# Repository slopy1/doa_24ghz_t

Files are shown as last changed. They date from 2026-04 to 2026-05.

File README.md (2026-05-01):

# DOA-24GHz: Direction-of-Arrival Estimation at 2.4 GHz

**Portable, real-time DoA estimation using a 2-element antenna array on an embedded FPGA platform**




## Overview

This thesis project implements a portable Direction-of-Arrival (DoA) estimation system at 2.4 GHz. A two-channel coherent SDR (BladeRF 2.0 xA4) feeds an FPGA SoC that runs the cross-correlation pipeline in fabric and root-MUSIC on the application processor. The system is bench-portable: a barrel-jack-powered SDR, two λ/2-spaced whip antennas, an nRF5340 signal source, and a single Ethernet link to a host PC.

Four DoA algorithms are implemented:
- **Root-MUSIC** (default) — polynomial root finding, fast and accurate
- **MUSIC** — spectral search with pseudo-spectrum visualization
- **MVDR** (Capon) — minimum variance beamformer
- **Phase Difference** — simple and fast baseline

Based on: Wachowiak & Kryszkiewicz (2022) — *"Angle of arrival estimation in a multi-antenna software defined radio system"*

## Current Platform Status

| Platform | Role | Branch / state |
| --- | --- | --- |
| **AMD Kria KV260** (Zynq UltraScale+ K26, Ubuntu 22.04 aarch64) | **Primary** — active thesis development, current capture campaigns | `main` |
| **Digilent Cora Z7** (Zynq-7000, PetaLinux 2025.2) | **Validated reference** — end-to-end pipeline + display, frozen | `feature/fir-backpressure` (frozen, not merged) |

The two platforms run the **same `doa_pipeline` RTL** (FIR + phase-cal rotation + cross-correlation + autocorrelation accumulators) and the same root-MUSIC implementation, with platform-specific transports for AXI register I/O and DMA.

### Why two platforms?

The thesis began on the Cora Z7. The Cora pipeline reached an end-to-end validated state on the `feature/fir-backpressure` branch (RTL + GNU Radio + headless driver + touch display), but PetaLinux 2025.2 ships with a confirmed upstream regression in chipidea USB binding (AMD answer record [AR#000039143](https://adaptivesupport.amd.com/), all-platforms, fix ETA 2026.1) that breaks BladeRF USB enumeration on any rebuilt `image.ub`. Each RTL or driver iteration past that point would have required either rolling forward onto a broken USB stack or freezing on a stale pre-rebuild image. The KV260 (Kria K26 SOM, Ubuntu 22.04 aarch64) sidesteps PetaLinux entirely and bypasses the bug, so live thesis development moved there. The Cora reference branch remains in this repo as a validated baseline; current capture campaigns run on the KV260.

## Hardware

| Component | Model | Purpose |
|---|---|---|
| FPGA SoC (primary) | AMD Kria KV260 starter kit (K26 SOM, ZU+ MPSoC) | Live thesis platform — Ubuntu + headless NumPy driver |
| FPGA SoC (reference) | Digilent Cora Z7 (Zynq-7000) | Frozen end-to-end reference — PetaLinux + GNU Radio |
| SDR | Nuand BladeRF 2.0 xA4 | 2-channel coherent receiver, 1 MS/s |
| Antennas | 2× Linx ANT-2.4-CW-RCL whips | Half-wavelength ULA (61.2 mm) |
| Signal source | nRF5340 DK (Zephyr `radio_test`) | 2.419 GHz GFSK / modulated carrier |
| Display (Cora-era, optional) | Waveshare ESP32-S3 4.3" Touch LCD | LVGL touch UI via UART |
| Power | TalentCell LiFePO4 12.8 V + DC-DC buck (Cora bench); BladeRF barrel jack 5 V/2 A | |

See [docs/HARDWARE_DETAILS.md](docs/HARDWARE_DETAILS.md) for enclosure dimensions and wiring.

## RF Parameters

| Parameter | Current campaign value |
|---|---|
| Center frequency | 2.41895 GHz (nRF ch 19 = 2.419 GHz, off-tuned 50 kHz) |
| Sample rate | 1 MS/s |
| RX bandwidth | 1 MHz |
| Antenna spacing | 61.2 mm (λ/2 at 2.45 GHz) |
| Array type | 2-element Uniform Linear Array |
| BladeRF gain | 50 dB |

## Repository Structure

```
doa_24ghz_t/
├── kv260_headless/             # KV260 driver path (PRIMARY)
│   ├── aoa_estimation_fpga_kv260.py   # NumPy + SoapySDR DoA driver
│   ├── aoa_estimation_headless.py     # ARM-only path (no FPGA accel)
│   ├── phase_calibration_headless.py  # Wired phase calibration
│   ├── emio_probe.py                  # EMIO GPIO bring-up check
│   ├── dma_probe.py                   # AXI-DMA state dump
│   └── ...
├── cora_headless/              # Cora Z7 driver (frozen reference)
│   ├── aoa_estimation_fpga_v2.py      # FPGA-accelerated DoA
│   ├── aoa_estimation_headless.py     # ARM-only baseline
│   ├── main.py                        # UART display controller
│   ├── web_dashboard.py               # HTTP + SSE web UI
│   ├── display_firmware/              # ESP32 LVGL touch display
│   └── initd/                         # SysVinit auto-start
├── fpga/
│   ├── rtl/                    # doa_pipeline + dma_safe_ctrl + supporting IP
│   ├── vivado_kv260/           # KV260 block design + constraints
│   ├── tb/                     # iverilog testbenches
│   └── GETTING_STARTED.md      # Vivado build flow
├── gnuradio_flowgraphs/        # Cora-era GRC flowgraphs (reference)
├── scripts/                    # Campaign automation, analysis, deploy
├── data/                       # Capture sessions (runA … runE, baselines)
├── results/                    # Campaign analysis outputs (plots, CSVs, fits)
├── hardware/                   # 3D-printed enclosure (OpenSCAD + STL)
└── docs/                       # Specs, thesis chapter sources, hardware details
```

## Quick Start (KV260 — primary path)

```bash
# 1. Bring up bitstream + udmabuf + EMIO gates (idempotent)
ssh ubuntu@<kv260-ip> 'sudo bash ~/doa/bench_bringup.sh'

# 2. Run a capture (60 s, root-MUSIC, unfiltered, ch 19 + 50 kHz off-tune)
ssh ubuntu@<kv260-ip> 'sudo python3 ~/doa/aoa_estimation_fpga_kv260.py \
    --filter none --algo rootmusic --freq 2.418e9 --gain 50'

# 3. Per-angle protocol (label captures by angle for the campaign)
ssh ubuntu@<kv260-ip> 'echo "50deg" > ~/doa/data/current_label.txt'
# … repeat capture for next angle …
```

Per-capture CSV + JSON sidecar lands under `~/doa/data/aoa_<LABEL>_<MODE>_<ALGO>_<TS>.csv`. See [docs/DEMO_QUICKSTART.md](docs/DEMO_QUICKSTART.md) for the full bench protocol.

## Quick Start (Cora Z7 — reference)

The Cora reference path lives on the `feature/fir-backpressure` branch (frozen, not merged into `main`):

```bash
git fetch origin feature/fir-backpressure
git checkout feature/fir-backpressure
# Then deploy to petalinux@<cora-ip>:/home/petalinux/doa/ per cora_headless/README
```

The Cora deployment includes a web dashboard (`http://<cora-ip>:8080`) and a touch display front-end. Live thesis development happens on `main` against the KV260 — this branch is preserved as the validated end-to-end baseline.

## Calibration

Wired phase calibration using a signal source, attenuator, and power splitter:

```
Signal Source (nRF5340 @ 2.419 GHz)
    → 30 dB SMA attenuator
    → 2-way power splitter
        → matched cable → BladeRF RX1
        → matched cable → BladeRF RX2
```

```bash
# KV260
sudo python3 ~/doa/phase_calibration_headless.py --freq 2.418e9 --duration 10
```

The `--filter=none` calibration is filter-agnostic (broadband static phase offset), reusable across filter regimes.

## Documentation

| Document | Description |
|---|---|
| [DEMO_QUICKSTART](docs/DEMO_QUICKSTART.md) | Step-by-step bench/demo procedure |
| [DEMO_COMMANDS](docs/DEMO_COMMANDS.txt) | Command reference (nRF + driver) |
| [HARDWARE_DETAILS](docs/HARDWARE_DETAILS.md) | Enclosure, components, power |
| [INSTALL_GUIDE](INSTALL_GUIDE.md) | Host PC + KV260 software setup |
| [fpga/GETTING_STARTED](fpga/GETTING_STARTED.md) | Vivado build flow + register map |
| [docs/specs/](docs/specs/) | Phase-by-phase RTL design specs |

## FPGA Pipeline

The `doa_pipeline` IP runs the per-snapshot signal processing in fabric:

```
BladeRF IQ stream → channel_splitter → fir_filter_sc16 → phase_rotate_sc16
                                                              ↓
                                       xcorr_acc + autocorr_acc (R00, R11)
                                                              ↓
                                                    AXI-Lite read-back
```

15 AXI-Lite registers, 48-bit accumulators read as LO/HI pairs. Same RTL on both targets, two transports:

- **Cora Z7**: AXI-Lite at `0x4000_0000` via `/dev/mem` mapping; AXI-DMA on OCM (0xFFFC_0000) bypassing CMA
- **KV260**: AXI-Lite at `0xA001_0000` via EMIO GPIO bit-banged register I/O (Path C); AXI-DMA on `S_AXI_HP0_FPD` with udmabuf-allocated CMA buffers

The KV260 transport works around an AXI-Lite write-strobe stride bug observed on the Kria HPM0_FPD aperture — see [docs/specs/2026-04-22-kv260-plan-of-attack.md](docs/specs/2026-04-22-kv260-plan-of-attack.md) for the full debug arc.

## License

MIT License

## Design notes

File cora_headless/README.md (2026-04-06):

# Cora Z7 Headless DoA System

This package contains all the software and documentation for the portable Direction of Arrival (DoA) estimation system based on the BladeRF 2.0 SDR and Cora Z7 FPGA board.

## System Architecture

```
┌─────────────────────────────────────────────────────────────────┐
│                                                                  │
│   ┌──────────────┐      UART       ┌──────────────────────┐    │
│   │   Waveshare  │◄───────────────►│      Cora Z7         │    │
│   │  ESP32 LCD   │   (Commands &   │   (PetaLinux +       │    │
│   │  (Touch UI)  │    Responses)   │    Python Scripts)   │    │
│   └──────────────┘                 └──────────┬───────────┘    │
│                                               │                 │
│                                          USB 2.0               │
│                                          (6 MSPS max)          │
│                                               │                 │
│                                    ┌──────────▼───────────┐    │
│                                    │     BladeRF 2.0      │    │
│                                    │     2×2 MIMO SDR     │    │
│                                    │     (Coherent RX)    │    │
│                                    └──────────┬───────────┘    │
│                                               │                 │
│                                    ┌──────────▼───────────┐    │
│                                    │   2-Element ULA      │    │
│                                    │   λ/2 = 61.2mm       │    │
│                                    │   @ 2.45 GHz         │    │
│                                    └─────────────────────-┘    │
│                                                                  │
└─────────────────────────────────────────────────────────────────┘
```

## Package Contents

```
cora_headless/
├── README.md                          # This file
├── main.py                            # UART command listener (runs on Cora)
├── phase_calibration_headless.py      # Calibration script
├── aoa_estimation_headless.py         # DoA estimation with multiple algorithms
│
├── display_firmware/
│   └── doa_display_firmware.ino       # ESP32 display firmware (Arduino)
│
├── systemd/
│   └── doa-controller.service         # Auto-start service for Cora
│
└── docs/
    └── WIRING_DIAGRAM.md              # Complete electrical connections
```

## Quick Start

### 1. Deploy to Cora Z7

```bash
# Copy files to Cora (adjust IP/hostname)
scp -r main.py *_headless.py root@cora:/home/root/doa/

# SSH into Cora
ssh root@cora

# Install service
cp doa-controller.service /etc/systemd/system/
systemctl daemon-reload
systemctl enable doa-controller
systemctl start doa-controller
```

### 2. Flash Display Firmware

1. Open `display_firmware/doa_display_firmware.ino` in Arduino IDE
2. Install required libraries:
   - LVGL (v8.x)
   - Board support for ESP32-S3
3. Select board: "ESP32S3 Dev Module" (or Waveshare-specific if available)
4. Flash via USB

### 3. Connect Hardware

Follow the wiring diagram in `docs/WIRING_DIAGRAM.md`.

### 4. First Run

1. Power on the system
2. Wait for display to show "Ready"
3. Tap **CALIBRATE** (with wired setup connected)
4. Record calibration value
5. Tap **ESTIMATE** to begin DoA measurements

## UART Protocol

### Commands (Display → Cora)

| Command | Description |
|---|---|
| `CALIBRATE` | Run phase calibration |
| `ESTIMATE` | Start DoA with default algorithm |
| `ESTIMATE:MUSIC` | Start with specific algorithm |
| `STATUS` | Query current state |
| `GET_CAL` | Get calibration coefficient |
| `SET_CAL:-12.5` | Manually set calibration (degrees) |
| `STOP` | Stop current operation |
| `SHUTDOWN` | Safe system shutdown |

### Responses (Cora → Display)

| Response | Description |
|---|---|
| `OK:<msg>` | Command acknowledged |
| `AOA:45.2` | Estimated angle (degrees) |
| `CAL:-8.7` | Calibration coefficient (degrees) |
| `STATUS:IDLE` | Current state |
| `PROGRESS:50` | Operation progress (0-100%) |
| `ERROR:<msg>` | Error message |
| `DONE` | Operation completed |

## Supported Algorithms

| Algorithm | Description | Speed | Accuracy |
|---|---|---|---|
| `PHASEDIFF`  | Simple phase difference | Fastest  | Low |
| `MUSIC` | Spectral search (181 points) | Slow | High |
| `ROOTMUSIC`  | Polynomial root finding (default) | Fast | High |
| `MVDR` | Capon beamformer | Medium | Medium |

## Hardware Constraints

- **USB 2.0 Bandwidth**: Limited to ~6 MSPS (vs 61 MSPS theoretical)
- **Thesis Justification**: "Due to hardware constraints of the FPGA platform, the system operates at reduced bandwidth sufficient for proof-of-concept DoA estimation."

## Calibration

The system requires wired phase calibration before use:

1. Connect signal source via splitter to both RX channels
2. Use matched-length cables
3. Include 30dB attenuator for safety
4. Run calibration for 10+ seconds
5. Record the stable phase offset value

**Typical values**: -30° to +30° depending on hardware

## Troubleshooting

| Symptom | Cause | Solution |
|---|---|---|
| "Disconnected" on display  | UART not connected | Check TX/RX wiring |
| No calibration signal | Gain too low | Increase RX gain |
| Erratic AoA readings | Missing calibration | Run CALIBRATE first |
| AoA stuck at 90° | No signal / weak signal | Check antenna connections |
| System won't power on | JP3 set to USB | Set JP3 to EXT |

## Development

### Testing Without Hardware

Both Python scripts support simulation mode when SoapySDR is unavailable:

```bash
# Test calibration
python phase_calibration_headless.py --duration=5

# Test estimation
python aoa_estimation_headless.py --cal=-10 --algo=ROOTMUSIC --single
```

### Testing main.py Locally

```bash
# Runs in stdin mode when UART unavailable
python main.py

# Enter commands manually:
> STATUS
> CALIBRATE
> ESTIMATE:MUSIC
> STOP
```

## References

- Wachowiak & Kryszkiewicz (2022) - "Angle of arrival estimation in a multi-antenna software defined radio system"
- gr-aoa: https://github.com/MarcinWachowiak/GNU-Radio-USRP-AoA
- BladeRF Wiki: https://github.com/Nuand/bladeRF/wiki
- Cora Z7 Reference: https://digilent.com/reference/programmable-logic/cora-z7/reference-manual

## License

MIT License - DoA Thesis Project 2026

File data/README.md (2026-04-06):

# Dataset Directory

This directory contains HDF5 captures for DOA experiments.

## File Naming Convention

```
capture_YYYYMMDD_HHMMSS_angle+XX_distY.Ym_SNR.h5
```

Example: `capture_20241221_153000_angle+30_dist2.0m_high.h5`

## Collecting Data

```bash
# Single capture
python scripts/collect_dataset.py --angle 30 --distance 2 --snr high

# Multiple repetitions
python scripts/collect_dataset.py --angle 30 --distance 2 --snr high --reps 10

# Full experiment matrix (run for each angle/distance)
for angle in -60 -45 -30 -15 0 15 30 45 60; do
    python scripts/collect_dataset.py --angle $angle --distance 2 --snr high --reps 10
    python scripts/collect_dataset.py --angle $angle --distance 5 --snr low --reps 10
done
```

## File Format

Each HDF5 file contains:

### Datasets
- `channel_0`: Complex64 array (RX0 samples)
- `channel_1`: Complex64 array (RX1 samples)

### Attributes
| Attribute | Type | Description |
|---|---|---|
| `timestamp_utc` | string | ISO timestamp |
| `center_frequency_hz` | float | 2.45e9 |
| `sample_rate_hz` | float | 5e6 |
| `nominal_angle_deg` | int | Ground truth angle |
| `distance_m` | float | TX-RX distance |
| `snr_label` | string | "high" or "low" |

## Data Size Estimate

- 1 second capture: ~40 MB (2 channels × 5M samples × 4 bytes)
- Full matrix (180 captures): ~7.2 GB

## Note on Large Files

Large HDF5 files are NOT committed to git. If you need to share data:

1. Use Git LFS: `git lfs track "*.h5"`
2. Use external storage (Dropbox, Google Drive, etc.)
3. Store a manifest file listing available captures

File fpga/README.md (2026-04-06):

# FPGA Implementation

This directory contains FPGA-related code and notes for accelerating the DOA pipeline on Zynq-7000.

## Target Platform

**Cora Z7-07S** (Xilinx Zynq-7000 XC7Z007S)

## Vivado Project

**Location:** `/home/vmau/tools/projects/cora-linux/cora_doa_hw/cora_doa_hw.xpr` (Vivado 2025.2)

**Block design (system):**
- ZYNQ7 Processing System (processing_system7_0)
- AXI DMA (axi_dma_0)
- Xilinx FFT IP (xfft_0)
- AXI Interconnect (axi_interconnect_0)
- Processor System Reset (rst_ps7_0_50M)
- xlconstant_0, xlconstant_1 (tieoffs, marked Discontinued)

Bitstream successfully generated. See `notes/vivado_block_design_2026-03-25.png` for screenshot.

## Directory Structure

```
fpga/
├── README.md              ← This file
├── GETTING_STARTED.md     ← Step-by-step implementation guide
├── rtl/
│   └── xcorr_acc.v        ← Cross-correlation module (skeleton, MAC TODO)
├── tb/
│   └── (testbench, next step)
├── constraints/
│   └── (timing .xdc if needed)
└── notes/
    └── vivado_block_design_2026-03-25.png
```

## Implementation Status

| Component | Status | Notes |
|---|---|---|
| Vivado block design | Done | FFT + DMA + AXI Interconnect wired |
| Bitstream (infrastructure) | Done | Generated successfully |
| Cross-correlation IP | In progress | Module skeleton in `rtl/xcorr_acc.v`, MAC datapath TODO |
| Power estimation | Designed | Same accumulator pattern as xcorr |
| Phase extraction | Pending | CORDIC or LUT, may stay on PS |
| AXI-Lite wrapper | Pending | After xcorr_acc simulation passes |
| Block design integration | Pending | Wire xcorr_acc into existing design |

## Architecture: Time-Domain Approach

Chosen over frequency-domain (FFT) for simplicity. The FFT block remains in the design for future use.

### What runs on PL (FPGA fabric)

1. **Streaming cross-correlation** (`xcorr_acc.v`)
   - Complex multiply-accumulate: `r_01 = Σ ch0[n] × conj(ch1[n])`
   - AXI-Stream input (64-bit, both channels packed)
   - AXI-Lite output registers for ARM to read results
   - ~4 DSP48 slices, ~500 LUTs

2. **Power estimation** (future, same accumulator structure)
   - `P_0 = Σ|ch0[n]|²`, `P_1 = Σ|ch1[n]|²`

### What runs on PS (ARM cores)

1. Phase extraction (atan2)
2. Grid search over angles
3. Kalman filter for drift tracking
4. Posterior computation

## Resource Budget

| Resource | Available | xcorr_acc | FFT (existing) | Remaining |
|---|---|---|---|---|
| DSP48 | 66 | 4 | ~10-15 | ~47 |
| BRAM | 50 | 0 | ~8-10 | ~30 |
| LUTs | 14,400 | ~500 | ~2000 | ~11,900 |
| FFs | 28,800 | ~1000 | ~2000 | ~25,800 |

## Next Steps

See [GETTING_STARTED.md](GETTING_STARTED.md) for the full walkthrough.

## References

- [docs/fpga_mapping.md](../docs/fpga_mapping.md) — Full architecture document
- Xilinx UG585 — Zynq-7000 TRM
- Xilinx UG1399 — Vitis HLS User Guide

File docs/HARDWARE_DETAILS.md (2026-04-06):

# Hardware Details — Portable Enclosure & Components

## Portable Enclosure

**Enclosure:** Meijia portable case, IP67 rated.

| Dimension | Imperial | Metric |
|---|---|---|
| Outside | 11.65 x 8.35 x 3.78" | 296 x 212 x 96mm |
| Inside | 10.54 x 6.04 x 3.16" | 268 x 153 x 80mm |
| Lid depth | 1.08" | 27.4mm |
| Bottom depth | 2.08" | 52.8mm |

Display mounts in lid (27.4mm deep — display at 8.6mm fits with 18.8mm to spare). All other components in bottom half.

## Display Bezel

3D-printed flat-frame mount. Source files:
- `hardware/display_bezel.scad` (OpenSCAD parametric source)
- `hardware/display_bezel.stl` and `.3mf` (exported)
- `hardware/ASSEMBLY.md` (install instructions)

Design: flat frame sits on lid exterior, display drops through cut hole from inside, optional back retainer clamps from behind.

## Display Measurements (Waveshare 4.3" 800x480)

- PCB: 106.33 x 68.2 x 8.6mm
- Glass (full incl. black frame): 106.2 x 67.8mm
- Glass/module thickness: 4.89mm
- Active area: 92.2 x 57.4mm (black border: 4.5mm top, 9.5mm bottom, 5.2mm each side)
- Bezel window: set to full glass (106.2 x 67.8mm)
- Bezel outer: ~120.8 x 82.4 x 2.5mm frame
- Lid hole to cut: ~106.9 x 68.8mm

## Components & Power

| Component | Power | Notes |
|---|---|---|
| Cora Z7 | 5V via barrel jack | JP3 set to EXT |
| BladeRF 2.0 xA4 | 5V via barrel jack (2A+) | TPS2115A auto-selects barrel over USB |
| Waveshare 4.3" display | 5V via USB-C | Mounts in lid, communicates via UART |
| Powered USB hub (Atolla) | 5V/3A own adapter | BladeRF USB + FT232R USB through hub |
| FT232R adapter | USB-powered from hub | TTL wires to ESP32 GPIO15/16 |
| 2-element ULA | Passive | lambda/2 = 61.2mm spacing @ 2.45 GHz |
| Battery | TalentCell LiFePO4 12.8V 6Ah | |
| DC-DC converter | Tobsun EA25-5V | 12.8V -> 5V, 25W |
| Power distribution | Wago 221 lever nuts | 5V bus to all devices |

## BladeRF Power Supply

The Cora Z7 USB-A host port (J11) provides limited current. The BladeRF 2.0 xA4 should be externally powered via its DC barrel jack (5V, 2A+, 5.5x2.5mm center-positive). Power options:
- **Bench supply**: 5V 2A current limit, alligator clips to barrel jack breakout wires
- **Portable**: TalentCell LiFePO4 (~13V) -> Tobsun EA25-5V 25W DC-DC converter -> 5V barrel jack
- **Wall adapter**: Any 5V 2A+ supply with 5.5x2.5mm center-positive barrel plug

The BladeRF's TPS2115A power mux auto-selects the barrel jack over USB when external power is present. Plug barrel jack first, then USB.

## Antennas

- **2x Linx ANT-2.4-CW-RCL** — 2.4 GHz helical whip, SMA, ~1 inch tall. Mounted on BladeRF RX1/RX2.
- Known issue: floppy hinge, needs to be stabilized (hot glue, heat shrink, or rigid bracket mount).

## Calibration Hardware

- **Mini-Circuits VAT-30A+** — 30 dB SMA fixed attenuator (DC-6 GHz, 1W). Place before splitter to protect BladeRF (max input ~0 dBm).
- **2-way power splitter** + **2x matched-length SMA cables** — for wired phase calibration.
- Connected as of 2026-03-18.

## Bottom Layout (approximate)

```
+----------------------------------+
|  BladeRF 2.0 xA4    |  Cora Z7  |
|  168 x 100 mm       |  89x89    |
|                      |           |
+----------------------+  USB Hub  |
|  TalentCell Battery  |  DC-DC    |
|  150 x 100 mm        |  Wago    |
+----------------------------------+
         ~296 x 212 mm
```

See `docs/WIRING_DIAGRAM.md` for detailed wiring and `docs/system_block_diagram.drawio` for the system block diagram.

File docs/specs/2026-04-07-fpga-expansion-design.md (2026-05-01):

# FPGA Expansion Design — 3-Phase Incremental Plan

**Date:** 2026-04-07
**Target:** Cora Z7 (Zynq-7000 XC7Z007S), Vivado 2025.2
**Goal:** Maximize FPGA utilization — move FIR filtering, auto-correlations, calibration, and multi-snapshot averaging into fabric. Each phase produces a working bitstream.

## Current State

**FPGA (PL):**
- `xcorr_acc` — computes r₀₁ = Σ(ch0 × conj(ch1)) per 1024-sample snapshot
- `xcorr_acc_axi` — AXI-Lite wrapper, 4 read-only registers (32-bit truncated from 48-bit accumulators)
- AXI DMA (SG mode) — ARM pushes one snapshot at a time
- ~4 DSP48 / ~2K LUTs / ~2K FFs used

**ARM (PS) — Python does all of this per update:**
1. Read 102,400 samples (100 × 1024) from BladeRF via SoapySDR
2. Apply FIR filter (201-tap lowpass/bandpass) via FFT convolution — both channels
3. Apply phase calibration rotation on ch1
4. Loop 100 times:
   a. Send 1024-sample snapshot to FPGA via DMA
   b. Read r₀₁ from AXI-Lite registers
   c. Compute r₀₀, r₁₁ in SC16 integer math (NumPy)
5. Average all 100 snapshots
6. Build 2×2 covariance matrix R
7. Eigendecomposition + Root-MUSIC → angle

**Known issues:**
- 32-bit register truncation causes MISMATCH on first 2-3 iterations (startup transient with large values)
- 100-iteration Python loop is the main latency bottleneck
- FIR filter on Cortex-A9 is slow even with FFT method

## Resource Budget (XC7Z007S)

| Resource | Total | Currently Used | Available |
|---|---|---|---|
| LUTs | 14,400 | ~2,000 | ~12,400 |
| FFs | 28,800 | ~2,000 | ~26,800 |
| DSP48E1 | 66 | ~4 | 62 |
| BRAM 36Kb | 50 | ~5 (DMA+FFT IP) | ~45 |
| BRAM 18Kb | 100 | ~10 | ~90 |

---

## Phase A — Enhanced Datapath (keep current DMA model)

**Goal:** Move FIR filtering, calibration rotation, and auto-correlations into fabric. ARM still loops 100×, but each iteration does almost no computation — just DMA kick + register read.

### A.1 New RTL Modules

#### `fir_filter_sc16` — FIR filter for one SC16 channel

```
Inputs:  s_axis_tdata[31:0] (SC16: {Q[31:16], I[15:0]})
         s_axis_tvalid, s_axis_tready
Outputs: m_axis_tdata[31:0] (filtered SC16)
         m_axis_tvalid, m_axis_tready
Config:  AXI-Lite writable coefficient RAM (up to 64 taps)
```

- Symmetric FIR (halves the multipliers needed for real-coefficient lowpass/bandpass)
- 64 taps max (vs 201 in Python — shorter but at line rate, and we can increase snapshot count to compensate)
- Filter I and Q components independently (real-coefficient FIR on complex data)
- Resource estimate: ~32 DSP48 for 64-tap symmetric (16 unique coefficients × 2 for I/Q), ~2K LUTs, 2 BRAM for coefficient storage

**Why 64 taps instead of 201:** At 1 Msps with 64 taps, the transition bandwidth is wider (~15 kHz vs ~5 kHz), but the stopband rejection is still >40 dB — sufficient for our SNR improvement goal. Going to 201 taps would consume all 66 DSP48s on just the filter.

**Alternative: 32 taps** if we need DSP headroom. 32-tap symmetric = 16 multipliers × 2 (I/Q) = 32 DSP48. Trade-off: ~30 dB stopband rejection.

**Recommended: 48 taps** — 24 unique coefficients × 2 = 48 DSP48. Leaves 14 DSP48 for xcorr + auto-corr. Good balance of rejection (~38 dB) and resource usage.

#### `phase_rotate_sc16` — Calibration phase rotation

```
Inputs:  s_axis_tdata[31:0] (SC16)
         s_axis_tvalid, s_axis_tready
Outputs: m_axis_tdata[31:0] (rotated SC16)
         m_axis_tvalid, m_axis_tready
Config:  AXI-Lite writable registers: cos_cal[15:0], sin_cal[15:0] (Q1.15 fixed-point)
```

- Complex multiply: (I + jQ) × (cos_cal - j·sin_cal)
  - I' = I·cos_cal + Q·sin_cal
  - Q' = Q·cos_cal - I·sin_cal
- Resource estimate: 4 DSP48, ~200 LUTs
- ARM writes cos/sin of calibration angle as Q1.15 values via AXI-Lite

#### `autocorr_acc` — Auto-correlation accumulator for r₀₀ and r₁₁

```
Inputs:  ch0_tdata[31:0], ch1_tdata[31:0] (SC16, after filtering)
         tvalid
Outputs: r00[47:0], r11[47:0], result_valid
```

- r₀₀ += I₀² + Q₀² (power of ch0)
- r₁₁ += I₁² + Q₁² (power of ch1)
- Same snapshot boundary logic as xcorr_acc (counter, latch, reset)
- Resource estimate: 4 DSP48, ~500 LUTs
- Can share the same AXI wrapper or be added to xcorr_acc_axi

### A.2 Modified `xcorr_acc_axi` — Expanded Register Map

Expand from 4 to 12 registers. Use full 48-bit readback (split into low/high words):

| Offset | Name | Width | Access | Description |
|---|---|---|---|---|
| 0x00 | XCORR_RE_LO | 32 | R | r₀₁ real, bits [31:0] |
| 0x04 | XCORR_RE_HI | 32 | R | r₀₁ real, bits [47:32] (sign-extended) |
| 0x08 | XCORR_IM_LO | 32 | R | r₀₁ imag, bits [31:0] |
| 0x0C | XCORR_IM_HI | 32 | R | r₀₁ imag, bits [47:32] (sign-extended) |
| 0x10 | R00_LO | 32 | R | r₀₀ auto-corr, bits [31:0] |
| 0x14 | R00_HI | 32 | R | r₀₀ auto-corr, bits [47:32] |
| 0x18 | R11_LO | 32 | R | r₁₁ auto-corr, bits [31:0] |
| 0x1C | R11_HI | 32 | R | r₁₁ auto-corr, bits [47:32] |
| 0x20 | STATUS | 32 | R | bit 0 = result_valid (sticky, clear-on-read) |
| 0x24 | SNAP_COUNT | 32 | R | completed snapshot counter |
| 0x28 | COS_CAL | 16 | R/W | calibration cos(θ) in Q1.15 |
| 0x2C | SIN_CAL | 16 | R/W | calibration sin(θ) in Q1.15 |
| 0x30 | FILTER_COEFF_ADDR | 8 | W | coefficient index to write |
| 0x34 | FILTER_COEFF_DATA | 16 | W | coefficient value (Q1.15) |
| 0x38 | FILTER_CTRL | 8 | R/W | bit 0 = filter enable, bit 1 = coefficients loaded |

Need C_S_AXI_ADDR_WIDTH ≥ 8 (currently 12, so no change needed).

### A.3 Block Design Changes (Vivado)

Current path:
```
DMA MM2S → xcorr_acc_axi (s_axis)
```

New path:
```
DMA MM2S → channel_splitter → fir_filter_sc16 (ch0) → ┐
                             → fir_filter_sc16 (ch1) → phase_rotate_sc16 → channel_merger
                                                                              ↓
                                                              xcorr_acc_axi (expanded, includes autocorr)
```

**channel_splitter:** Demuxes the interleaved 2-beat stream into two separate SC16 streams (ch0, ch1). Simple FSM toggling on beat_phase.

**channel_merger:** Re-interleaves the two filtered/calibrated SC16 streams back into the 2-beat format expected by xcorr_acc.

Alternatively: modify xcorr_acc to accept two separate input ports instead of interleaved. This avoids the split/merge overhead.

### A.4 Python Driver Changes (`aoa_estimation_fpga_v3.py`)

```python
# Phase A: ARM still loops, but registers provide full covariance per snapshot

# At startup — write filter coefficients and calibration
fpga.write_filter_coefficients(taps)  # AXI-Lite writes to coeff RAM
fpga.write_calibration(cal_deg)       # Write cos/sin to registers

# Per-update loop (100 snapshots)
for k in range(n_snap):
    fpga.dma_transfer(ch0_snap, ch1_snap)  # Push raw SC16 data
    r01_re, r01_im = fpga.read_xcorr_48bit()  # Full 48-bit read
    r00 = fpga.read_r00_48bit()
    r11 = fpga.read_r11_48bit()
    # Accumulate on ARM (simple addition, no DSP)
    acc_re += r01_re
    acc_im += r01_im
    acc_r00 += r00
    acc_r11 += r11

# Build R and run Root-MUSIC (same as before)
```

**What ARM no longer does:**
- FIR filtering (moved to FPGA)
- Phase calibration rotation (moved to FPGA)
- SC16 quantization for r₀₀/r₁₁ (FPGA computes directly)
- The Python loop is now: DMA kick → read 6 registers → add to accumulators

### A.5 Resource Estimate (Phase A)

| Resource | Phase A Usage | Total Available | % Used |
|---|---|---|---|
| DSP48E1 | ~56 (48 FIR + 4 phase_rot + 4 xcorr + 4 autocorr, but xcorr reuses) | 66 | ~85% |
| LUTs | ~6,000 | 14,400 | ~42% |
| FFs | ~5,000 | 28,800 | ~17% |
| BRAM 18Kb | ~4 (coeff storage) | 100 | ~4% |

**Note:** 48-tap FIR uses 48 DSP48 if we filter both channels. If resources are too tight, reduce to 32 taps (32 DSP48) or use a single time-shared FIR for both channels (halves DSP48 but doubles latency — fine at 1 Msps since the clock is 100 MHz, giving 100× oversampling).

**Recommended: Time-shared single FIR** — processes ch0, then ch1, using the same multiplier array. Uses 24 DSP48 for a 48-tap symmetric filter. Total DSP48: 24 + 4 + 4 + 4 = 36 (~55%).

### A.6 Testing Strategy

1. **Simulation (iverilog):**
   - `tb_fir_filter_sc16.v` — impulse response test, known sinusoid filtering
   - `tb_phase_rotate_sc16.v` — verify rotation angles (0°, 45°, 90°, 180°)
   - `tb_autocorr_acc.v` — known-power input, verify r₀₀/r₁₁
   - `tb_full_pipeline.v` — end-to-end: raw SC16 → filter → rotate → xcorr + autocorr

2. **Hardware test (on Cora):**
   - `test_fpga_pipeline.py` — synthetic DMA test similar to existing `test_fpga_xcorr.py`
   - Compare FPGA pipeline output vs NumPy reference for known phase/amplitude inputs

3. **Live comparison:**
   - `--debug` flag prints FPGA vs ARM reference for first N iterations with real BladeRF data

---

## Phase B — Autonomous Streaming (rework DMA)

**Goal:** Eliminate the 100-iteration Python loop. FPGA accumulates N snapshots autonomously. ARM reads the final averaged covariance matrix once per update.

### B.1 DMA Changes

Replace single-shot SG DMA with **cyclic DMA** (ring buffer):
- ARM sets up a circular SG descriptor ring
- DMA streams continuously from a shared DDR buffer
- BladeRF → SoapySDR writes to buffer, DMA reads from it
- FPGA consumes at line rate

Alternative (simpler): ARM still pushes data, but sends all 100 snapshots in one large DMA transfer (102,400 × 2 channels × 4 bytes = 819,200 bytes). Single SG descriptor chain, FPGA processes the entire batch.

**Recommended: Large single transfer** — simpler than true ring buffer, still eliminates the per-snapshot DMA setup overhead. ARM calls `readStream` once for all samples, packs them into the DMA buffer, kicks one transfer, waits for completion.

### B.2 New RTL: `multi_snapshot_acc`

Wraps xcorr_acc + autocorr_acc with an outer counter:
```
Parameter: NUM_SNAPSHOTS (writable via AXI-Lite, default 100)

For each snapshot (1024 samples):
  - Accumulate r01, r00, r11 as before
  - At snapshot boundary: add to outer accumulator
  - After NUM_SNAPSHOTS: latch final averaged values, assert result_valid
```

Register map adds:
| Offset | Name | Width | Access | Description |
|---|---|---|---|---|
| 0x3C | NUM_SNAPSHOTS | 16 | R/W | Snapshots to average before signaling result |
| 0x40 | AVG_R01_RE_LO | 32 | R | Averaged r₀₁ real |
| ... | | | | (6 more averaged registers) |

### B.3 Python Driver Changes

```python
# Phase B: single DMA transfer, single register read
fpga.write_num_snapshots(100)
fpga.dma_transfer_bulk(ch0_all, ch1_all)  # One big transfer
fpga.wait_for_result()                     # Poll STATUS register
R = fpga.read_covariance_matrix()          # Read 6 values → build 2x2 R
aoa = root_music_doa(R, ...)               # Only computation ARM does
```

### B.4 Resource Estimate (Phase B, incremental over A)

Additional ~500 LUTs, ~500 FFs for outer accumulator and control. DSP48 unchanged.

---

## Phase C — Full FPGA DoA (angle output)

**Goal:** FPGA outputs the DoA angle directly. ARM just reads one register.

### C.1 2×2 Eigendecomposition in Fixed-Point

For a 2×2 Hermitian matrix R = [[r₀₀, r₀₁], [r₀₁*, r₁₁]], the noise eigenvector has a closed-form:

```
The noise subspace eigenvector for a 2×2 matrix is:
  e_noise = [-r₀₁, r₀₀ - λ_min]  (unnormalized)

where λ_min = (r₀₀ + r₁₁)/2 - sqrt((r₀₀ - r₁₁)²/4 + |r₀₁|²)
```

This requires:
- Fixed-point square root (iterative, ~16 cycles for 48-bit)
- Basic arithmetic (add, subtract, shift)

### C.2 Root-MUSIC for 2 Elements

For a 2-element ULA with 1 source, Root-MUSIC reduces to:
```
phase = atan2(imag(r₀₁), real(r₀₁)) - cal_phase
angle = arccos(phase / (2π × d/λ))
```

Wait — for 2 elements and 1 source, Root-MUSIC simplifies to essentially the phase-difference method applied to the noise subspace. The polynomial is degree 1. This means:

- **CORDIC** for atan2 (~16 iterations, ~200 LUTs)
- **CORDIC** for arccos (same unit, different mode)
- Fixed-point division (or shift if d/λ = 0.5)

### C.3 Register Map Addition

| Offset | Name | Width | Access | Description |
|---|---|---|---|---|
| 0x50 | DOA_ANGLE | 16 | R | Estimated angle × 10 (e.g., 854 = 85.4°) |
| 0x54 | DOA_VALID | 1 | R | New angle available |

### C.4 Resource Estimate (Phase C, incremental over B)

Additional ~2K LUTs for CORDIC + sqrt + control. No additional DSP48.

**Total Phase C estimate:**

| Resource | Total Usage | Available | % Used |
|---|---|---|---|
| DSP48E1 | ~36 | 66 | ~55% |
| LUTs | ~9,000 | 14,400 | ~63% |
| FFs | ~7,000 | 28,800 | ~24% |
| BRAM 18Kb | ~4 | 100 | ~4% |

---

## Implementation Order (Tomorrow's Plan)

### Day 1 — Phase A Foundation

**Morning (RTL + Simulation):**

1. **Write `fir_filter_sc16.v`** — time-shared symmetric FIR, 48 taps
   - Coefficient loading via simple interface (not AXI-Lite yet — test first)
   - Testbench: impulse response, known sinusoid at 50 kHz, verify stopband rejection

2. **Write `phase_rotate_sc16.v`** — complex multiply with cos/sin registers
   - Testbench: 0°, 45°, 90°, 180° rotation, verify against NumPy

3. **Write `autocorr_acc.v`** — power accumulator for both channels
   - Testbench: known-amplitude input, verify r₀₀/r₁₁ match

4. **Run all simulations with iverilog** — all tests must pass before Vivado

**Afternoon (Integration):**

5. **Expand `xcorr_acc_axi.v`** — new register map (48-bit readback, cal registers, filter ctrl)
   - Testbench: AXI-Lite read/write verification

6. **Write `doa_pipeline.v`** — top-level wrapper connecting:
   `s_axis → fir_filter (time-shared) → phase_rotate (ch1 only) → xcorr_acc + autocorr_acc → registers`

7. **Full pipeline testbench** — synthetic SC16 data through entire chain, compare with NumPy

### Day 2 — Vivado + Hardware

8. **Package IP in Vivado** — add `doa_pipeline` as custom IP
9. **Update block design** — replace `xcorr_acc_axi_0` with new `doa_pipeline`
10. **Synthesis + Implementation** — check timing, utilization
11. **Generate bitstream** — save as `BOOT_phaseA.BIN`
12. **Write `aoa_estimation_fpga_v3.py`** — new driver using expanded registers
13. **Hardware test** — run `test_fpga_pipeline.py` with synthetic data
14. **Live test** — compare Phase A output vs current v2 with real BladeRF data

### Day 3+ — Phase B

15. Rework DMA to bulk transfer
16. Add multi-snapshot accumulator
17. New bitstream + driver
18. Benchmark: update rate comparison (Phase A vs Phase B vs pure ARM)

---

## Fallback Strategy

- **Current bitstream** saved as `BOOT_current.BIN` before any changes
- Each phase produces a named bitstream: `BOOT_phaseA.BIN`, `BOOT_phaseB.BIN`
- Python scripts versioned: `v2` (current), `v3` (Phase A), `v4` (Phase B)
- If Phase A synthesis fails timing: reduce FIR to 32 taps
- If Phase B DMA rework is too complex: stay on Phase A (still a major improvement)

## Design Decisions Summary

| Decision | Choice | Rationale |
|---|---|---|
| FIR tap count | 48 (symmetric → 24 unique) | Balances rejection (~38 dB) vs DSP48 budget |
| FIR architecture | Time-shared (1 filter, 2 channels) | Halves DSP48 usage, 100 MHz clock gives 100× margin at 1 Msps |
| Accumulator width | 48-bit | Matches existing xcorr_acc, 6 bits headroom over worst case |
| Register readback | 48-bit split (LO/HI) | Fixes 32-bit truncation bug seen in debug |
| Cal rotation | Q1.15 cos/sin | 15-bit fractional precision ≈ 0.002° angular resolution |
| Phase A→B transition | Large single DMA transfer | Simpler than ring buffer, eliminates per-snapshot overhead |
| Phase C eigen | Closed-form 2×2 | No iterative solver needed for 2-element array |

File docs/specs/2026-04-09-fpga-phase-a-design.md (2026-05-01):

# FPGA Phase A — Enhanced Datapath Design Spec

**Date:** 2026-04-09
**Parent spec:** `2026-04-07-fpga-expansion-design.md`
**Target:** Cora Z7 (Zynq-7000 XC7Z007S), Vivado 2025.2
**Goal:** Move FIR filtering, phase calibration rotation, and auto-correlations (r00/r11) into the FPGA fabric. ARM still loops 100 snapshots via DMA, but each iteration is reduced to: DMA kick + read 3 register pairs.

---

## 1. Design Decisions

| Decision | Choice | Rationale |
|---|---|---|
| FIR tap count | 48 (symmetric -> 24 unique) | ~38 dB stopband rejection, fits DSP48 budget |
| FIR architecture | Time-shared single filter | Processes ch0 then ch1 on same multiplier array. 100 MHz / 1 Msps = 100x clock headroom |
| Coefficient loading | Runtime-loadable via AXI-Lite | Supports bandpass/lowpass/none switching from Python without resynthesis |
| Accumulator width | 48-bit | Matches existing xcorr_acc, 6 bits headroom over worst case |
| Register readback | 48-bit split (LO/HI pairs) | Fixes the 32-bit truncation bug seen in v2 debug output |
| Cal rotation format | Q1.15 cos/sin | 15-bit fractional precision = ~0.002 deg angular resolution |
| Phase rotation | ch1 only | Matches ARM code's apply_calibration() behavior |

## 2. Resource Estimate

| Resource | Phase A Usage | Total Available | % Used |
|---|---|---|---|
| DSP48E1 | ~36 (24 FIR + 4 phase_rot + 4 xcorr + 4 autocorr) | 66 | ~55% |
| LUTs | ~6,000 | 14,400 | ~42% |
| FFs | ~5,000 | 28,800 | ~17% |
| BRAM 18Kb | ~4 (coeff storage + FIR delay lines) | 100 | ~4% |

## 3. Datapath Architecture

```
DMA MM2S (raw SC16, interleaved ch0/ch1 beats)
    |
    v
channel_splitter --- demux beat 0 -> ch0, beat 1 -> ch1
    |           |
    v           v
 FIR(ch0)    FIR(ch1)    <-- time-shared single multiplier array
    |           |
    |           v
    |     phase_rotate    <-- complex multiply by (cos_cal - j*sin_cal)
    |     (ch1 only)
    |           |
    v           v
xcorr_acc (r01 = ch0 * conj(ch1))   <-- existing math, unchanged
autocorr_acc (r00 = |ch0|^2, r11 = |ch1|^2)   <-- new
    |
    v
AXI-Lite registers (48-bit split readback)
ARM reads r01_re, r01_im, r00, r11
```

## 4. New RTL Modules

### 4.1 `channel_splitter`

Demuxes the interleaved 2-beat AXI-Stream into two separate SC16 streams.

- Input: 32-bit AXI-Stream (beat 0 = ch0, beat 1 = ch1)
- Output: two 32-bit SC16 streams with valid signals
- Simple FSM toggling on beat_phase (same logic currently inside xcorr_acc)

### 4.2 `fir_filter_sc16`

Time-shared symmetric FIR filter processing both channels.

- 48 taps, symmetric -> 24 unique coefficients
- Processes I and Q independently (real-coefficient FIR on complex data)
- Coefficient RAM writable via simple addr/data interface
- Filter enable/bypass control bit
- Time-sharing: processes ch0 samples first, then ch1, using same multiplier array

### 4.3 `phase_rotate_sc16`

Complex multiply for calibration phase rotation on ch1.

- (I + jQ) x (cos_cal - j*sin_cal)
- I' = I*cos_cal + Q*sin_cal
- Q' = Q*cos_cal - I*sin_cal
- cos_cal and sin_cal are Q1.15 fixed-point, writable via AXI-Lite

### 4.4 `autocorr_acc`

Auto-correlation accumulator computing power for both channels.

- r00 += I0^2 + Q0^2 (power of ch0)
- r11 += I1^2 + Q1^2 (power of ch1)
- Same snapshot boundary logic as xcorr_acc (counter, latch, reset)
- 48-bit accumulators

## 5. Register Map

Base address: `0x4000_0000` (unchanged). C_S_AXI_ADDR_WIDTH = 12 (unchanged).

### Read-only registers (result values):

| Offset | Name | Width | Description |
|---|---|---|---|
| 0x00 | XCORR_RE_LO | 32 | r01 real, bits [31:0] |
| 0x04 | XCORR_RE_HI | 32 | r01 real, bits [47:32] (sign-extended) |
| 0x08 | XCORR_IM_LO | 32 | r01 imag, bits [31:0] |
| 0x0C | XCORR_IM_HI | 32 | r01 imag, bits [47:32] (sign-extended) |
| 0x10 | R00_LO | 32 | r00 auto-corr ch0, bits [31:0] |
| 0x14 | R00_HI | 32 | r00 auto-corr ch0, bits [47:32] |
| 0x18 | R11_LO | 32 | r11 auto-corr ch1, bits [31:0] |
| 0x1C | R11_HI | 32 | r11 auto-corr ch1, bits [47:32] |
| 0x20 | STATUS | 32 | bit 0 = result_valid (sticky, clear-on-read) |
| 0x24 | SNAP_COUNT | 32 | completed snapshot counter |

### Read/write registers (configuration):

| Offset | Name | Width | Description |
|---|---|---|---|
| 0x28 | COS_CAL | 16 | cos(cal_angle) in Q1.15 signed fixed-point |
| 0x2C | SIN_CAL | 16 | sin(cal_angle) in Q1.15 signed fixed-point |
| 0x30 | COEFF_ADDR | 8 | Coefficient index to write (0-23) |
| 0x34 | COEFF_DATA | 16 | Coefficient value in Q1.15 -- write triggers storage |
| 0x38 | FILTER_CTRL | 8 | bit 0 = filter enable, bit 1 = coefficients loaded |

Address decode: `axi_araddr[5:2]` gives 16 register slots (0x00-0x3C).

## 6. Annotated Verilog Reference

The following Verilog is annotated line-by-line for study. This represents the target RTL for Phase A.

### 6.1 `channel_splitter.v`

```verilog
// channel_splitter.v -- Demux interleaved 2-beat AXI-Stream into separate ch0/ch1
//
// The DMA sends data as alternating "beats":
//   Beat 0: {ch0_Q[31:16], ch0_I[15:0]}   (channel 0, I and Q packed into 32 bits)
//   Beat 1: {ch1_Q[31:16], ch1_I[15:0]}   (channel 1, I and Q packed into 32 bits)
//
// This module splits that single interleaved stream into two independent streams,
// one for each channel. Downstream modules (FIR, phase rotate) work on one
// channel at a time, so they need separated data.

`timescale 1ns / 1ps  // simulation time unit = 1 ns, precision = 1 ps

module channel_splitter (
    input  wire        clk,          // system clock (100 MHz on Cora Z7)
    input  wire        rst_n,        // active-low reset (0 = reset, 1 = running)

    // --- AXI-Stream input (interleaved ch0/ch1 beats from DMA) ---
    input  wire [31:0] s_axis_tdata,  // 32-bit data: {Q[31:16], I[15:0]}
    input  wire        s_axis_tvalid, // high when data on tdata is valid
    output wire        s_axis_tready, // we assert this to say "ready to accept"

    // --- Channel 0 output ---
    output reg  [31:0] ch0_tdata,     // ch0 sample: {Q[31:16], I[15:0]}
    output reg         ch0_tvalid,    // high for one cycle when ch0_tdata is valid

    // --- Channel 1 output ---
    output reg  [31:0] ch1_tdata,     // ch1 sample: {Q[31:16], I[15:0]}
    output reg         ch1_tvalid     // high for one cycle when ch1_tdata is valid
);

    // beat_phase tracks which beat we're on:
    //   0 = expecting ch0 data (beat 0)
    //   1 = expecting ch1 data (beat 1)
    reg beat_phase;

    // We're always ready to accept data -- no backpressure (streaming design)
    assign s_axis_tready = 1'b1;

    always @(posedge clk) begin          // execute on every rising clock edge
        if (!rst_n) begin                // RESET: clear everything
            beat_phase <= 0;             // start expecting ch0
            ch0_tdata  <= 32'd0;
            ch0_tvalid <= 1'b0;
            ch1_tdata  <= 32'd0;
            ch1_tvalid <= 1'b0;
        end else begin
            // Default: both outputs invalid this cycle (pulse behavior)
            ch0_tvalid <= 1'b0;
            ch1_tvalid <= 1'b0;

            if (s_axis_tvalid) begin     // new beat arrived from DMA
                if (beat_phase == 1'b0) begin
                    // Beat 0: this is channel 0 data
                    ch0_tdata  <= s_axis_tdata;   // capture the 32-bit sample
                    ch0_tvalid <= 1'b1;           // signal "ch0 data ready"
                    beat_phase <= 1'b1;           // next beat will be ch1
                end else begin
                    // Beat 1: this is channel 1 data
                    ch1_tdata  <= s_axis_tdata;   // capture the 32-bit sample
                    ch1_tvalid <= 1'b1;           // signal "ch1 data ready"
                    beat_phase <= 1'b0;           // next beat will be ch0 again
                end
            end
        end
    end

endmodule
```

### 6.2 `fir_filter_sc16.v`

```verilog
// fir_filter_sc16.v -- Time-shared symmetric FIR filter for SC16 data
//
// WHAT THIS DOES:
//   Takes raw SC16 samples (16-bit signed I + 16-bit signed Q) and applies
//   a FIR (Finite Impulse Response) filter. The filter smooths the signal
//   by computing a weighted sum of the current and past samples. The weights
//   are the "coefficients" (aka "taps") loaded at startup by the ARM.
//
// TIME-SHARING:
//   We have two channels to filter (ch0 and ch1), but only one set of
//   multipliers. The FPGA clock (100 MHz) is 100x faster than the sample
//   rate (1 MHz), so we process ch0 first, then ch1, reusing the same
//   hardware. This halves our DSP48 usage.
//
// SYMMETRIC OPTIMIZATION:
//   For a linear-phase FIR, coeff[k] == coeff[N-1-k]. Instead of doing
//   48 multiplies, we add the two samples that share a coefficient first:
//     result += coeff[k] * (sample[k] + sample[N-1-k])
//   This halves the multiplies again: 48 taps -> 24 multiplies per component.
//
// COMPLEX DATA:
//   SC16 = signed 16-bit I (in-phase) + signed 16-bit Q (quadrature).
//   Since our FIR coefficients are real-valued (not complex), we filter
//   I and Q independently using the same coefficients. Each "multiply"
//   is actually two multiplies (one for I, one for Q), using 2 DSP48s.
//   24 coefficient pairs x 2 (I+Q) = 48 DSP48s... but time-sharing means
//   we reuse them for both channels, so it's still 24 DSP48s total.
//
// FIXED POINT:
//   Coefficients are Q1.15 (1 sign bit, 15 fractional bits, range [-1, +1)).
//   Multiply: 16-bit sample x 16-bit coeff = 32-bit product.
//   Accumulate across 24 taps: needs ~37 bits (32 + ceil(log2(24)) = 37).
//   We use 48-bit accumulators for headroom, then truncate back to 16-bit
//   for the output.

`timescale 1ns / 1ps

module fir_filter_sc16 #(
    parameter NUM_TAPS    = 48,        // total filter length (must be even)
    parameter NUM_UNIQUE  = NUM_TAPS/2,// unique coefficients (symmetric)
    parameter COEFF_WIDTH = 16,        // Q1.15 coefficient width
    parameter DATA_WIDTH  = 16,        // SC16 component width (I or Q)
    parameter ACC_WIDTH   = 48         // internal accumulator width
)(
    input  wire        clk,
    input  wire        rst_n,

    // --- Coefficient loading interface (active at startup) ---
    input  wire [$clog2(NUM_UNIQUE)-1:0] coeff_addr,  // which coefficient (0-23)
    input  wire [COEFF_WIDTH-1:0]        coeff_data,  // the coefficient value
    input  wire                          coeff_wr_en, // pulse high to store

    // --- Filter enable (bypass when 0) ---
    input  wire        filter_en,

    // --- Channel 0 input/output ---
    input  wire [31:0] ch0_tdata,     // {Q[31:16], I[15:0]}
    input  wire        ch0_tvalid,
    output reg  [31:0] ch0_out_tdata, // filtered {Q[31:16], I[15:0]}
    output reg         ch0_out_tvalid,

    // --- Channel 1 input/output ---
    input  wire [31:0] ch1_tdata,
    input  wire        ch1_tvalid,
    output reg  [31:0] ch1_out_tdata,
    output reg         ch1_out_tvalid
);

    // ---------------------------------------------------------------
    // Coefficient storage (RAM)
    // ---------------------------------------------------------------
    // 24 coefficients stored in a small register array.
    // ARM writes these once at startup via AXI-Lite -> coeff_addr/data/wr_en.
    reg signed [COEFF_WIDTH-1:0] coeffs [0:NUM_UNIQUE-1];

    // On write-enable pulse, store the coefficient at the given address
    integer ci;
    always @(posedge clk) begin
        if (!rst_n) begin
            for (ci = 0; ci < NUM_UNIQUE; ci = ci + 1)
                coeffs[ci] <= 0;
        end else if (coeff_wr_en) begin
            coeffs[coeff_addr] <= coeff_data;
        end
    end

    // ---------------------------------------------------------------
    // Delay line (shift register) for each channel's I and Q
    // ---------------------------------------------------------------
    // A FIR filter needs access to the current sample AND the past (NUM_TAPS-1)
    // samples. We store them in a shift register: new samples enter at index 0,
    // old samples shift toward index NUM_TAPS-1.
    //
    // We keep separate delay lines for ch0 and ch1, each with I and Q.

    reg signed [DATA_WIDTH-1:0] ch0_delay_i [0:NUM_TAPS-1];
    reg signed [DATA_WIDTH-1:0] ch0_delay_q [0:NUM_TAPS-1];
    reg signed [DATA_WIDTH-1:0] ch1_delay_i [0:NUM_TAPS-1];
    reg signed [DATA_WIDTH-1:0] ch1_delay_q [0:NUM_TAPS-1];

    // Shift new sample into delay line (oldest sample falls off the end)
    integer di;
    always @(posedge clk) begin
        if (!rst_n) begin
            for (di = 0; di < NUM_TAPS; di = di + 1) begin
                ch0_delay_i[di] <= 0;
                ch0_delay_q[di] <= 0;
                ch1_delay_i[di] <= 0;
                ch1_delay_q[di] <= 0;
            end
        end else begin
            // Channel 0: shift when new sample arrives
            if (ch0_tvalid) begin
                for (di = NUM_TAPS-1; di > 0; di = di - 1) begin
                    ch0_delay_i[di] <= ch0_delay_i[di-1];  // shift right
                    ch0_delay_q[di] <= ch0_delay_q[di-1];
                end
                // New sample enters at position 0
                // tdata format: {Q[31:16], I[15:0]}
                ch0_delay_i[0] <= $signed(ch0_tdata[15:0]);   // I component
                ch0_delay_q[0] <= $signed(ch0_tdata[31:16]);  // Q component
            end

            // Channel 1: same logic
            if (ch1_tvalid) begin
                for (di = NUM_TAPS-1; di > 0; di = di - 1) begin
                    ch1_delay_i[di] <= ch1_delay_i[di-1];
                    ch1_delay_q[di] <= ch1_delay_q[di-1];
                end
                ch1_delay_i[0] <= $signed(ch1_tdata[15:0]);
                ch1_delay_q[0] <= $signed(ch1_tdata[31:16]);
            end
        end
    end

    // ---------------------------------------------------------------
    // FIR computation (symmetric, combinational for now)
    // ---------------------------------------------------------------
    // For each channel, compute:
    //   output_I = sum over k=0..23 of: coeff[k] * (delay_I[k] + delay_I[47-k])
    //   output_Q = sum over k=0..23 of: coeff[k] * (delay_Q[k] + delay_Q[47-k])
    //
    // The (delay[k] + delay[47-k]) exploits symmetry -- two samples that
    // share the same coefficient get added first, then multiplied once.
    // This is a standard FPGA FIR optimization.
    //
    // NOTE: In synthesis, Vivado will infer DSP48 slices for the multiplies.
    // In simulation (iverilog), these are just behavioral multiplies.

    // --- Channel 0 ---
    reg signed [ACC_WIDTH-1:0] ch0_acc_i;  // running sum for I component
    reg signed [ACC_WIDTH-1:0] ch0_acc_q;  // running sum for Q component

    // --- Channel 1 ---
    reg signed [ACC_WIDTH-1:0] ch1_acc_i;
    reg signed [ACC_WIDTH-1:0] ch1_acc_q;

    // Pipelined computation: when a valid sample arrives, compute the
    // filter output over multiple clock cycles (one coefficient per cycle).
    // With 24 coefficients and 100 MHz clock, this takes 24 cycles = 240 ns,
    // well within the ~1000 ns sample period at 1 Msps.

    // State machine for time-shared computation
    localparam IDLE    = 2'd0;   // waiting for a new sample
    localparam COMP_CH0 = 2'd1;  // computing ch0 filter output
    localparam COMP_CH1 = 2'd2;  // computing ch1 filter output
    localparam OUTPUT  = 2'd3;   // latching results

    reg [1:0] state;
    reg [$clog2(NUM_UNIQUE)-1:0] tap_idx;  // which coefficient we're processing
    reg ch0_pending;  // new ch0 sample waiting to be processed
    reg ch1_pending;  // new ch1 sample waiting to be processed

    // Pre-add results (symmetric pair sums) -- computed combinationally
    wire signed [DATA_WIDTH:0] ch0_sym_i = ch0_delay_i[tap_idx] + ch0_delay_i[NUM_TAPS-1-tap_idx];
    wire signed [DATA_WIDTH:0] ch0_sym_q = ch0_delay_q[tap_idx] + ch0_delay_q[NUM_TAPS-1-tap_idx];
    wire signed [DATA_WIDTH:0] ch1_sym_i = ch1_delay_i[tap_idx] + ch1_delay_i[NUM_TAPS-1-tap_idx];
    wire signed [DATA_WIDTH:0] ch1_sym_q = ch1_delay_q[tap_idx] + ch1_delay_q[NUM_TAPS-1-tap_idx];

    always @(posedge clk) begin
        if (!rst_n) begin
            state          <= IDLE;
            tap_idx        <= 0;
            ch0_pending    <= 0;
            ch1_pending    <= 0;
            ch0_acc_i      <= 0;
            ch0_acc_q      <= 0;
            ch1_acc_i      <= 0;
            ch1_acc_q      <= 0;
            ch0_out_tdata  <= 0;
            ch0_out_tvalid <= 0;
            ch1_out_tdata  <= 0;
            ch1_out_tvalid <= 0;
        end else begin
            // Default: output valids are pulses (high for one cycle only)
            ch0_out_tvalid <= 1'b0;
            ch1_out_tvalid <= 1'b0;

            // Capture pending flags when new samples arrive
            if (ch0_tvalid) ch0_pending <= 1'b1;
            if (ch1_tvalid) ch1_pending <= 1'b1;

            case (state)
                IDLE: begin
                    // Wait until both channels have new samples
                    // (they arrive back-to-back from the splitter)
                    if (ch0_pending && ch1_pending) begin
                        if (!filter_en) begin
                            // BYPASS: pass through unfiltered data directly
                            // Use the newest sample from the delay line
                            ch0_out_tdata  <= {ch0_delay_q[0], ch0_delay_i[0]};
                            ch0_out_tvalid <= 1'b1;
                            ch1_out_tdata  <= {ch1_delay_q[0], ch1_delay_i[0]};
                            ch1_out_tvalid <= 1'b1;
                            ch0_pending    <= 1'b0;
                            ch1_pending    <= 1'b0;
                        end else begin
                            // START FILTERING: begin with ch0
                            ch0_acc_i <= 0;   // clear accumulators
                            ch0_acc_q <= 0;
                            tap_idx   <= 0;   // start from coefficient 0
                            state     <= COMP_CH0;
                        end
                    end
                end

                COMP_CH0: begin
                    // Multiply-accumulate: acc += coeff[k] * (sample[k] + sample[47-k])
                    // The $signed() cast ensures signed multiplication in Verilog
                    ch0_acc_i <= ch0_acc_i + ($signed(coeffs[tap_idx]) * ch0_sym_i);
                    ch0_acc_q <= ch0_acc_q + ($signed(coeffs[tap_idx]) * ch0_sym_q);

                    if (tap_idx == NUM_UNIQUE - 1) begin
                        // Done with ch0 -- move to ch1
                        ch1_acc_i <= 0;
                        ch1_acc_q <= 0;
                        tap_idx   <= 0;
                        state     <= COMP_CH1;
                    end else begin
                        tap_idx <= tap_idx + 1;  // next coefficient
                    end
                end

                COMP_CH1: begin
                    // Same MAC operation, but using ch1's delay line
                    ch1_acc_i <= ch1_acc_i + ($signed(coeffs[tap_idx]) * ch1_sym_i);
                    ch1_acc_q <= ch1_acc_q + ($signed(coeffs[tap_idx]) * ch1_sym_q);

                    if (tap_idx == NUM_UNIQUE - 1) begin
                        // Done with both channels -- output results
                        state <= OUTPUT;
                    end else begin
                        tap_idx <= tap_idx + 1;
                    end
                end

                OUTPUT: begin
                    // Truncate 48-bit accumulator back to 16-bit SC16 output.
                    // Coefficients are Q1.15, so the product is Q17.15.
                    // We right-shift by 15 to get back to integer scale,
                    // then take the lower 16 bits.
                    //
                    // ch0_acc_i >>> 15 extracts the 16-bit filtered value.
                    // (>>> is arithmetic right shift -- preserves sign bit)
                    ch0_out_tdata  <= {ch0_acc_q[ACC_WIDTH-1:15], ch0_acc_i[ACC_WIDTH-1:15]};
                    ch0_out_tvalid <= 1'b1;

                    ch1_out_tdata  <= {ch1_acc_q[ACC_WIDTH-1:15], ch1_acc_i[ACC_WIDTH-1:15]};
                    ch1_out_tvalid <= 1'b1;

                    ch0_pending <= 1'b0;
                    ch1_pending <= 1'b0;
                    state       <= IDLE;
                end
            endcase
        end
    end

endmodule
```

### 6.3 `phase_rotate_sc16.v`

```verilog
// phase_rotate_sc16.v -- Calibration phase rotation for one SC16 channel
//
// WHAT THIS DOES:
//   Applies a complex rotation to compensate for the phase offset between
//   the two antenna channels. Without calibration, the measured angle is
//   wrong by a fixed amount (currently ~16.33 deg for the ARM path).
//
// THE MATH:
//   A complex sample is (I + jQ). To rotate it by angle -theta:
//     (I + jQ) * (cos(theta) - j*sin(theta))
//
//   Expanding:
//     I' = I*cos + Q*sin     (new in-phase component)
//     Q' = Q*cos - I*sin     (new quadrature component)
//
//   This is just two multiplies and an add/subtract per component.
//
// FIXED POINT:
//   cos and sin are provided as Q1.15 values by the ARM.
//   Q1.15 means: value = register_value / 32768
//   So cos(16.33 deg) = 0.9596 -> round(0.9596 * 32768) = 31444
//
//   The multiply: 16-bit sample * 16-bit cos/sin = 32-bit product.
//   We right-shift by 15 to undo the Q1.15 scaling, yielding a 16-bit result.
//   Uses 4 DSP48 slices (I*cos, I*sin, Q*cos, Q*sin).

`timescale 1ns / 1ps

module phase_rotate_sc16 (
    input  wire        clk,
    input  wire        rst_n,

    // --- Calibration angle (written by ARM via AXI-Lite) ---
    input  wire signed [15:0] cos_cal,  // cos(cal_angle) in Q1.15
    input  wire signed [15:0] sin_cal,  // sin(cal_angle) in Q1.15

    // --- Input SC16 sample ---
    input  wire [31:0] s_tdata,        // {Q[31:16], I[15:0]}
    input  wire        s_tvalid,       // input valid

    // --- Output rotated SC16 sample ---
    output reg  [31:0] m_tdata,        // {Q'[31:16], I'[15:0]}
    output reg         m_tvalid        // output valid (1-cycle latency)
);

    // Extract I and Q from the input (signed 16-bit)
    wire signed [15:0] in_i = $signed(s_tdata[15:0]);    // in-phase
    wire signed [15:0] in_q = $signed(s_tdata[31:16]);   // quadrature

    // Intermediate products (32-bit, from 16x16 multiply)
    // These will map to DSP48 slices in synthesis.
    wire signed [31:0] i_cos = in_i * cos_cal;   // I * cos(theta)
    wire signed [31:0] q_sin = in_q * sin_cal;   // Q * sin(theta)
    wire signed [31:0] q_cos = in_q * cos_cal;   // Q * cos(theta)
    wire signed [31:0] i_sin = in_i * sin_cal;   // I * sin(theta)

    // Compute rotated I' and Q':
    //   I' = I*cos + Q*sin
    //   Q' = Q*cos - I*sin
    //
    // The products are Q17.15 (32-bit). We add/subtract, then extract
    // bits [30:15] to get back to 16-bit Q1.0 (integer) scale.
    // Bit 30 (not 31) because the sign bit of Q1.15 * Q1.15 is at bit 30.
    wire signed [32:0] rot_i_full = i_cos + q_sin;  // 33-bit to handle overflow
    wire signed [32:0] rot_q_full = q_cos - i_sin;

    // Right-shift by 15 and truncate to 16 bits
    wire signed [15:0] rot_i = rot_i_full[30:15];
    wire signed [15:0] rot_q = rot_q_full[30:15];

    // Pipeline register: one clock cycle latency
    always @(posedge clk) begin
        if (!rst_n) begin
            m_tdata  <= 32'd0;
            m_tvalid <= 1'b0;
        end else begin
            m_tvalid <= s_tvalid;              // valid follows input by 1 cycle
            if (s_tvalid) begin
                m_tdata <= {rot_q, rot_i};     // repack as {Q[31:16], I[15:0]}
            end
        end
    end

endmodule
```

### 6.4 `autocorr_acc.v`

```verilog
// autocorr_acc.v -- Auto-correlation (power) accumulator for two channels
//
// WHAT THIS DOES:
//   Computes the signal power for each channel over a snapshot:
//     r00 = sum of (I0^2 + Q0^2) for all samples in ch0
//     r11 = sum of (I1^2 + Q1^2) for all samples in ch1
//
//   These are the diagonal elements of the 2x2 covariance matrix R.
//   Together with r01 (from xcorr_acc), the ARM has the full matrix:
//     R = [[r00, r01],
//          [conj(r01), r11]]
//
// WHY IN FPGA:
//   The v2 Python code computes r00/r11 on the ARM by converting CF32->SC16
//   and doing NumPy integer math. Moving this to fabric means the ARM's
//   inner loop has zero computation -- just DMA + register reads.
//
// FIXED POINT:
//   Input: 16-bit signed I, 16-bit signed Q
//   I^2 + Q^2: max value per sample = 32767^2 + 32767^2 = ~2.15 * 10^9
//   Over 1024 samples: max = ~2.2 * 10^12, needs 42 bits.
//   We use 48-bit accumulators for headroom (same as xcorr_acc).
//   Uses 4 DSP48 slices (I0^2, Q0^2, I1^2, Q1^2).

`timescale 1ns / 1ps

module autocorr_acc #(
    parameter SNAPSHOT_LEN = 1024,   // samples per snapshot
    parameter ACC_WIDTH    = 48      // accumulator bit width
)(
    input  wire        clk,
    input  wire        rst_n,

    // --- Channel 0 input (filtered SC16) ---
    input  wire [31:0] ch0_tdata,    // {Q[31:16], I[15:0]}
    input  wire        ch0_tvalid,

    // --- Channel 1 input (filtered + rotated SC16) ---
    input  wire [31:0] ch1_tdata,
    input  wire        ch1_tvalid,

    // --- Results (latched at snapshot boundary) ---
    output reg  [ACC_WIDTH-1:0] r00,           // auto-corr of ch0 (unsigned)
    output reg  [ACC_WIDTH-1:0] r11,           // auto-corr of ch1 (unsigned)
    output reg                  result_valid    // pulse high for one cycle
);

    // Extract signed I and Q from each channel
    wire signed [15:0] ch0_i = $signed(ch0_tdata[15:0]);
    wire signed [15:0] ch0_q = $signed(ch0_tdata[31:16]);
    wire signed [15:0] ch1_i = $signed(ch1_tdata[15:0]);
    wire signed [15:0] ch1_q = $signed(ch1_tdata[31:16]);

    // Power per sample: I^2 + Q^2
    // 16-bit * 16-bit = 32-bit, both terms positive, sum fits in 33 bits
    wire [32:0] ch0_power = (ch0_i * ch0_i) + (ch0_q * ch0_q);
    wire [32:0] ch1_power = (ch1_i * ch1_i) + (ch1_q * ch1_q);

    // Running accumulators (48-bit, reset each snapshot)
    reg [ACC_WIDTH-1:0] acc_r00;
    reg [ACC_WIDTH-1:0] acc_r11;

    // Sample counter -- counts how many samples we've seen in this snapshot
    reg [$clog2(SNAPSHOT_LEN)-1:0] sample_cnt;

    // We accumulate when BOTH channels have valid data on the same cycle.
    // Since they come from the FIR (which outputs ch0 and ch1 together
    // in the OUTPUT state), they should be aligned.
    wire both_valid = ch0_tvalid & ch1_tvalid;

    always @(posedge clk) begin
        if (!rst_n) begin
            acc_r00      <= 0;
            acc_r11      <= 0;
            r00          <= 0;
            r11          <= 0;
            sample_cnt   <= 0;
            result_valid <= 0;
        end else if (both_valid) begin
            // Accumulate power for this sample
            acc_r00 <= acc_r00 + ch0_power;
            acc_r11 <= acc_r11 + ch1_power;

            if (sample_cnt == SNAPSHOT_LEN - 1) begin
                // End of snapshot: latch the final values (including this sample)
                r00          <= acc_r00 + ch0_power;
                r11          <= acc_r11 + ch1_power;
                result_valid <= 1'b1;

                // Reset for next snapshot
                acc_r00    <= 0;
                acc_r11    <= 0;
                sample_cnt <= 0;
            end else begin
                result_valid <= 0;
                sample_cnt   <= sample_cnt + 1;
            end
        end else begin
            result_valid <= 0;   // no valid data this cycle, no pulse
        end
    end

endmodule
```

### 6.5 `doa_pipeline.v` (Top-level wrapper)

```verilog
// doa_pipeline.v -- Top-level Phase A DoA processing pipeline
//
// This is the module that replaces xcorr_acc_axi in the Vivado block design.
// It connects all the Phase A modules together:
//
//   DMA input -> splitter -> FIR filter -> phase rotate (ch1) ->
//   -> xcorr_acc (r01) + autocorr_acc (r00, r11) -> AXI-Lite registers
//
// From the ARM's perspective, this looks like a single AXI-Lite peripheral
// at base address 0x4000_0000 with an AXI-Stream slave port for DMA data.
//
// The ARM:
//   1. Writes filter coefficients (0x30/0x34) and calibration (0x28/0x2C) at startup
//   2. Enables the filter (0x38 bit 0)
//   3. For each snapshot: DMA 2048 beats -> read r01, r00, r11 from registers
//   4. Averages 100 snapshots, runs Root-MUSIC

`timescale 1ns / 1ps

module doa_pipeline #(
    parameter SNAPSHOT_LEN        = 1024,
    parameter ACC_WIDTH           = 48,
    parameter NUM_TAPS            = 48,
    parameter C_S_AXI_DATA_WIDTH  = 32,
    parameter C_S_AXI_ADDR_WIDTH  = 12
)(
    // --- Clock and reset ---
    (* X_INTERFACE_PARAMETER = "ASSOCIATED_BUSIF s_axi:s_axis, ASSOCIATED_RESET s_axi_aresetn" *)
    input  wire        s_axi_aclk,
    input  wire        s_axi_aresetn,

    // --- AXI-Lite Slave (register access from ARM) ---
    input  wire [C_S_AXI_ADDR_WIDTH-1:0] s_axi_awaddr,
    input  wire [2:0]                     s_axi_awprot,
    input  wire                           s_axi_awvalid,
    output reg                            s_axi_awready,

    input  wire [C_S_AXI_DATA_WIDTH-1:0] s_axi_wdata,
    input  wire [3:0]                     s_axi_wstrb,
    input  wire                           s_axi_wvalid,
    output reg                            s_axi_wready,

    output reg  [1:0]                     s_axi_bresp,
    output reg                            s_axi_bvalid,
    input  wire                           s_axi_bready,

    input  wire [C_S_AXI_ADDR_WIDTH-1:0] s_axi_araddr,
    input  wire [2:0]                     s_axi_arprot,
    input  wire                           s_axi_arvalid,
    output reg                            s_axi_arready,

    output reg  [C_S_AXI_DATA_WIDTH-1:0] s_axi_rdata,
    output reg  [1:0]                     s_axi_rresp,
    output reg                            s_axi_rvalid,
    input  wire                           s_axi_rready,

    // --- AXI-Stream Slave (DMA data input) ---
    (* X_INTERFACE_INFO = "xilinx.com:interface:axis:1.0 s_axis TDATA" *)
    (* X_INTERFACE_PARAMETER = "CLK_DOMAIN s_axi_aclk, FREQ_HZ 50000000, HAS_TKEEP 0, HAS_TLAST 0, HAS_TREADY 1, HAS_TSTRB 0, TDATA_NUM_BYTES 4" *)
    input  wire [31:0] s_axis_tdata,
    (* X_INTERFACE_INFO = "xilinx.com:interface:axis:1.0 s_axis TVALID" *)
    input  wire        s_axis_tvalid,
    (* X_INTERFACE_INFO = "xilinx.com:interface:axis:1.0 s_axis TREADY" *)
    output wire        s_axis_tready
);

    // ===============================================================
    // Internal wires connecting the pipeline stages
    // ===============================================================

    // Splitter outputs
    wire [31:0] split_ch0_tdata;
    wire        split_ch0_tvalid;
    wire [31:0] split_ch1_tdata;
    wire        split_ch1_tvalid;

    // FIR filter outputs
    wire [31:0] fir_ch0_tdata;
    wire        fir_ch0_tvalid;
    wire [31:0] fir_ch1_tdata;
    wire        fir_ch1_tvalid;

    // Phase rotate output (ch1 only; ch0 passes through)
    wire [31:0] rot_ch1_tdata;
    wire        rot_ch1_tvalid;

    // xcorr_acc results
    wire [ACC_WIDTH-1:0] xcorr_re_raw;
    wire [ACC_WIDTH-1:0] xcorr_im_raw;
    wire                 xcorr_valid;

    // autocorr_acc results
    wire [ACC_WIDTH-1:0] r00_raw;
    wire [ACC_WIDTH-1:0] r11_raw;
    wire                 autocorr_valid;

    // ===============================================================
    // Writable configuration registers (ARM writes via AXI-Lite)
    // ===============================================================

    reg signed [15:0] reg_cos_cal;    // 0x28: cos(cal_angle) Q1.15
    reg signed [15:0] reg_sin_cal;    // 0x2C: sin(cal_angle) Q1.15
    reg [4:0]         reg_coeff_addr; // 0x30: coefficient index (0-23)
    reg signed [15:0] reg_coeff_data; // 0x34: coefficient value
    reg               coeff_wr_pulse; // triggers one-cycle write to FIR
    reg               reg_filter_en;  // 0x38 bit 0: enable filter
    reg               reg_coeff_loaded; // 0x38 bit 1: coefficients loaded

    // ===============================================================
    // Read-only result registers (latched at snapshot boundary)
    // ===============================================================

    reg [ACC_WIDTH-1:0] reg_xcorr_re;   // 0x00/0x04
    reg [ACC_WIDTH-1:0] reg_xcorr_im;   // 0x08/0x0C
    reg [ACC_WIDTH-1:0] reg_r00;        // 0x10/0x14
    reg [ACC_WIDTH-1:0] reg_r11;        // 0x18/0x1C
    reg                 reg_valid;      // 0x20 bit 0 (sticky, clear-on-read)
    reg [31:0]          reg_snap_count; // 0x24

    reg clear_valid;  // signal from read logic to clear valid bit

    // Latch results when xcorr_acc signals completion
    // (xcorr and autocorr should fire on the same cycle since they
    // share the same data stream and snapshot length)
    always @(posedge s_axi_aclk) begin
        if (!s_axi_aresetn) begin
            reg_xcorr_re  <= 0;
            reg_xcorr_im  <= 0;
            reg_r00       <= 0;
            reg_r11       <= 0;
            reg_valid     <= 0;
            reg_snap_count <= 0;
        end else begin
            if (clear_valid)
                reg_valid <= 0;

            if (xcorr_valid) begin
                reg_xcorr_re   <= xcorr_re_raw;
                reg_xcorr_im   <= xcorr_im_raw;
                reg_r00        <= r00_raw;
                reg_r11        <= r11_raw;
                reg_valid      <= 1;
                reg_snap_count <= reg_snap_count + 1;
            end
        end
    end

    // ===============================================================
    // Pipeline instantiation
    // ===============================================================

    // --- Stage 1: Split interleaved stream into ch0 and ch1 ---
    channel_splitter u_splitter (
        .clk           (s_axi_aclk),
        .rst_n         (s_axi_aresetn),
        .s_axis_tdata  (s_axis_tdata),
        .s_axis_tvalid (s_axis_tvalid),
        .s_axis_tready (s_axis_tready),
        .ch0_tdata     (split_ch0_tdata),
        .ch0_tvalid    (split_ch0_tvalid),
        .ch1_tdata     (split_ch1_tdata),
        .ch1_tvalid    (split_ch1_tvalid)
    );

    // --- Stage 2: FIR filter (both channels, time-shared) ---
    fir_filter_sc16 #(
        .NUM_TAPS  (NUM_TAPS),
        .ACC_WIDTH (ACC_WIDTH)
    ) u_fir (
        .clk            (s_axi_aclk),
        .rst_n          (s_axi_aresetn),
        .coeff_addr     (reg_coeff_addr),
        .coeff_data     (reg_coeff_data),
        .coeff_wr_en    (coeff_wr_pulse),
        .filter_en      (reg_filter_en),
        .ch0_tdata      (split_ch0_tdata),
        .ch0_tvalid     (split_ch0_tvalid),
        .ch0_out_tdata  (fir_ch0_tdata),
        .ch0_out_tvalid (fir_ch0_tvalid),
        .ch1_tdata      (split_ch1_tdata),
        .ch1_tvalid     (split_ch1_tvalid),
        .ch1_out_tdata  (fir_ch1_tdata),
        .ch1_out_tvalid (fir_ch1_tvalid)
    );

    // --- Stage 3: Phase rotation on ch1 only ---
    phase_rotate_sc16 u_rotate (
        .clk      (s_axi_aclk),
        .rst_n    (s_axi_aresetn),
        .cos_cal  (reg_cos_cal),
        .sin_cal  (reg_sin_cal),
        .s_tdata  (fir_ch1_tdata),
        .s_tvalid (fir_ch1_tvalid),
        .m_tdata  (rot_ch1_tdata),
        .m_tvalid (rot_ch1_tvalid)
    );

    // --- Stage 4a: Cross-correlation (r01 = ch0 * conj(ch1)) ---
    // We need to re-interleave ch0 and ch1 for xcorr_acc, which expects
    // the 2-beat format. We use a small FSM for this.
    //
    // ch0 comes from FIR directly (no rotation).
    // ch1 comes from phase_rotate.
    // xcorr_acc needs: beat0=ch0, beat1=ch1, beat0=ch0, beat1=ch1, ...

    reg [31:0] xcorr_axis_tdata;
    reg        xcorr_axis_tvalid;
    reg        interleave_phase;  // 0=send ch0, 1=send ch1

    // Buffer the ch0 and ch1 samples to align them for interleaving
    reg [31:0] buf_ch0;
    reg        buf_ch0_valid;
    reg [31:0] buf_ch1;
    reg        buf_ch1_valid;

    always @(posedge s_axi_aclk) begin
        if (!s_axi_aresetn) begin
            buf_ch0       <= 0;
            buf_ch0_valid <= 0;
            buf_ch1       <= 0;
            buf_ch1_valid <= 0;
            xcorr_axis_tdata  <= 0;
            xcorr_axis_tvalid <= 0;
            interleave_phase  <= 0;
        end else begin
            xcorr_axis_tvalid <= 0;  // default: no output this cycle

            // Capture filtered ch0 (straight from FIR, not rotated)
            if (fir_ch0_tvalid) begin
                buf_ch0       <= fir_ch0_tdata;
                buf_ch0_valid <= 1;
            end

            // Capture rotated ch1
            if (rot_ch1_tvalid) begin
                buf_ch1       <= rot_ch1_tdata;
                buf_ch1_valid <= 1;
            end

            // When both are ready, emit interleaved beats
            if (buf_ch0_valid && buf_ch1_valid) begin
                if (interleave_phase == 0) begin
                    // Beat 0: ch0
                    xcorr_axis_tdata  <= buf_ch0;
                    xcorr_axis_tvalid <= 1;
                    interleave_phase  <= 1;
                end else begin
                    // Beat 1: ch1
                    xcorr_axis_tdata  <= buf_ch1;
                    xcorr_axis_tvalid <= 1;
                    interleave_phase  <= 0;
                    // Both consumed
                    buf_ch0_valid <= 0;
                    buf_ch1_valid <= 0;
                end
            end
        end
    end

    // xcorr_acc core (existing module, unchanged)
    xcorr_acc #(
        .SNAPSHOT_LEN (SNAPSHOT_LEN),
        .ACC_WIDTH    (ACC_WIDTH)
    ) u_xcorr (
        .clk            (s_axi_aclk),
        .rst_n          (s_axi_aresetn),
        .s_axis_tdata   (xcorr_axis_tdata),
        .s_axis_tvalid  (xcorr_axis_tvalid),
        .s_axis_tready  (),  // xcorr is always ready
        .xcorr_re       (xcorr_re_raw),
        .xcorr_im       (xcorr_im_raw),
        .result_valid   (xcorr_valid)
    );

    // --- Stage 4b: Auto-correlation (r00, r11) in parallel ---
    // Uses filtered ch0 and rotated ch1, same data as xcorr_acc
    autocorr_acc #(
        .SNAPSHOT_LEN (SNAPSHOT_LEN),
        .ACC_WIDTH    (ACC_WIDTH)
    ) u_autocorr (
        .clk          (s_axi_aclk),
        .rst_n        (s_axi_aresetn),
        .ch0_tdata    (buf_ch0),     // filtered ch0
        .ch0_tvalid   (buf_ch0_valid && buf_ch1_valid),
        .ch1_tdata    (buf_ch1),     // filtered + rotated ch1
        .ch1_tvalid   (buf_ch0_valid && buf_ch1_valid),
        .r00          (r00_raw),
        .r11          (r11_raw),
        .result_valid (autocorr_valid)
    );

    // ===============================================================
    // AXI-Lite Read Logic
    // ===============================================================
    // The ARM reads registers by sending an address on the AR channel,
    // then we respond with data on the R channel.

    reg [C_S_AXI_ADDR_WIDTH-1:0] axi_araddr;

    always @(posedge s_axi_aclk) begin
        if (!s_axi_aresetn) begin
            s_axi_arready <= 0;
            axi_araddr    <= 0;
        end else if (s_axi_arvalid && !s_axi_arready) begin
            s_axi_arready <= 1;           // accept the read address
            axi_araddr    <= s_axi_araddr;// latch it
        end else begin
            s_axi_arready <= 0;
        end
    end

    // Decode address and return the appropriate register value
    always @(posedge s_axi_aclk) begin
        if (!s_axi_aresetn) begin
            s_axi_rdata  <= 0;
            s_axi_rresp  <= 0;
            s_axi_rvalid <= 0;
            clear_valid  <= 0;
        end else if (s_axi_arready && s_axi_arvalid && !s_axi_rvalid) begin
            s_axi_rvalid <= 1;
            s_axi_rresp  <= 2'b00;  // OKAY

            // Decode using bits [5:2] -> 16 register slots
            case (axi_araddr[5:2])
                4'h0: s_axi_rdata <= reg_xcorr_re[31:0];                        // 0x00
                4'h1: s_axi_rdata <= {{16{reg_xcorr_re[ACC_WIDTH-1]}},           // 0x04
                                      reg_xcorr_re[ACC_WIDTH-1:32]};             // sign-extend
                4'h2: s_axi_rdata <= reg_xcorr_im[31:0];                         // 0x08
                4'h3: s_axi_rdata <= {{16{reg_xcorr_im[ACC_WIDTH-1]}},           // 0x0C
                                      reg_xcorr_im[ACC_WIDTH-1:32]};
                4'h4: s_axi_rdata <= reg_r00[31:0];                              // 0x10
                4'h5: s_axi_rdata <= {{16{1'b0}}, reg_r00[ACC_WIDTH-1:32]};      // 0x14 (unsigned)
                4'h6: s_axi_rdata <= reg_r11[31:0];                              // 0x18
                4'h7: s_axi_rdata <= {{16{1'b0}}, reg_r11[ACC_WIDTH-1:32]};      // 0x1C (unsigned)
                4'h8: s_axi_rdata <= {31'b0, reg_valid};                         // 0x20
                4'h9: s_axi_rdata <= reg_snap_count;                             // 0x24
                4'hA: s_axi_rdata <= {{16{reg_cos_cal[15]}}, reg_cos_cal};       // 0x28
                4'hB: s_axi_rdata <= {{16{reg_sin_cal[15]}}, reg_sin_cal};       // 0x2C
                4'hC: s_axi_rdata <= {27'b0, reg_coeff_addr};                    // 0x30
                4'hD: s_axi_rdata <= {{16{reg_coeff_data[15]}}, reg_coeff_data}; // 0x34
                4'hE: s_axi_rdata <= {30'b0, reg_coeff_loaded, reg_filter_en};   // 0x38
                default: s_axi_rdata <= 32'hDEADBEEF;
            endcase
        end else if (s_axi_rvalid && s_axi_rready) begin
            s_axi_rvalid <= 0;
            // Clear-on-read for STATUS register (0x20 = slot 0x8)
            if (axi_araddr[5:2] == 4'h8)
                clear_valid <= 1;
            else
                clear_valid <= 0;
        end else begin
            clear_valid <= 0;
        end
    end

    // ===============================================================
    // AXI-Lite Write Logic
    // ===============================================================
    // The ARM writes configuration registers (cal angles, FIR coefficients).

    reg [C_S_AXI_ADDR_WIDTH-1:0] axi_awaddr;
    reg                           aw_ready;
    reg                           w_ready;

    always @(posedge s_axi_aclk) begin
        if (!s_axi_aresetn) begin
            s_axi_awready   <= 0;
            s_axi_wready    <= 0;
            s_axi_bvalid    <= 0;
            s_axi_bresp     <= 0;
            axi_awaddr      <= 0;
            aw_ready         <= 0;
            w_ready          <= 0;
            reg_cos_cal      <= 0;
            reg_sin_cal      <= 0;
            reg_coeff_addr   <= 0;
            reg_coeff_data   <= 0;
            coeff_wr_pulse   <= 0;
            reg_filter_en    <= 0;
            reg_coeff_loaded <= 0;
        end else begin
            coeff_wr_pulse <= 0;  // default: no write pulse

            // Capture write address
            if (s_axi_awvalid && !s_axi_awready) begin
                s_axi_awready <= 1;
                axi_awaddr    <= s_axi_awaddr;
                aw_ready      <= 1;
            end else begin
                s_axi_awready <= 0;
            end

            // Capture write data
            if (s_axi_wvalid && !s_axi_wready) begin
                s_axi_wready <= 1;
                w_ready      <= 1;
            end else begin
                s_axi_wready <= 0;
            end

            // When both address and data are captured, decode and store
            if (aw_ready && w_ready) begin
                aw_ready <= 0;
                w_ready  <= 0;

                case (axi_awaddr[5:2])
                    4'hA: reg_cos_cal    <= s_axi_wdata[15:0];    // 0x28
                    4'hB: reg_sin_cal    <= s_axi_wdata[15:0];    // 0x2C
                    4'hC: reg_coeff_addr <= s_axi_wdata[4:0];     // 0x30
                    4'hD: begin
                        reg_coeff_data <= s_axi_wdata[15:0];      // 0x34
                        coeff_wr_pulse <= 1;  // trigger FIR coeff write
                    end
                    4'hE: begin
                        reg_filter_en    <= s_axi_wdata[0];       // 0x38 bit 0
                        reg_coeff_loaded <= s_axi_wdata[1];       // 0x38 bit 1
                    end
                    default: ; // ignore writes to read-only registers
                endcase
            end

            // Write response
            if (s_axi_awready && s_axi_awvalid &&
                s_axi_wready && s_axi_wvalid && !s_axi_bvalid) begin
                s_axi_bvalid <= 1;
                s_axi_bresp  <= 2'b00;  // OKAY
            end else if (s_axi_bvalid && s_axi_bready) begin
                s_axi_bvalid <= 0;
            end
        end
    end

endmodule
```

## 7. Testing Strategy

### 7.1 Unit simulation (iverilog)

| Testbench | Verifies |
|---|---|
| `tb_channel_splitter.v` | Interleaved in -> two separate streams, correct beat assignment |
| `tb_fir_filter_sc16.v` | Impulse response matches NumPy. 50 kHz sinusoid passband/stopband |
| `tb_phase_rotate_sc16.v` | Rotation at 0/45/90/180 deg vs NumPy reference |
| `tb_autocorr_acc.v` | Constant amplitude -> known power. Random -> matches NumPy `sum(I^2 + Q^2)` |

### 7.2 Full pipeline simulation (iverilog)

`tb_doa_pipeline.v` -- End-to-end: generate SC16 with known phase, load coefficients via AXI-Lite, stream data, read registers, compare with Python reference.

### 7.3 Hardware test (on Cora)

`test_fpga_pipeline.py` -- Extends existing `test_fpga_xcorr.py`: write coefficients + cal, DMA synthetic data, read all registers, compare vs NumPy.

Regression: run with FILTER_CTRL=0, compare against current v2 xcorr results.

### 7.4 Live validation

`aoa_estimation_fpga_v3.py --debug` -- real BladeRF data, prints FPGA vs ARM reference for first 5 iterations.

## 8. Python Driver Changes (v3)

- `FPGAXcorr` gains: `write_filter_coefficients()`, `write_calibration()`, `enable_filter()`, `read_48bit()`
- ARM inner loop: DMA raw samples -> read 3 register pairs -> integer accumulate
- ARM no longer does: FIR filtering, calibration rotation, SC16 r00/r11 computation
- `design_filter()` stays -- computes taps once, writes to FPGA
- `--filter=none` sets FILTER_CTRL=0 (bypass, data passes through unfiltered)
- v2 script stays as fallback

## 9. Fallback Strategy

- Current bitstream saved as `BOOT_current.BIN`
- Phase A bitstream saved as `BOOT_phaseA.BIN`
- If synthesis fails timing: reduce to 32-tap FIR
- If FIR output is wrong: disable filter (FILTER_CTRL=0) and debug incrementally
- v2 Python script and bitstream always available for immediate rollback

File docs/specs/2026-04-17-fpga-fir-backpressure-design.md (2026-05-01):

# FPGA Phase A — FIR Backpressure & Pipeline AXI-Stream Compliance

**Date:** 2026-04-17
**Status:** Draft — brainstorming in progress
**Related:** `docs/specs/2026-04-09-fpga-phase-a-design.md`, the project notes "Current Blockers — FIR throughput bottleneck"

---

## TL;DR (one-paragraph elevator pitch for later)

The Phase A `doa_pipeline` accepts DMA samples at ~25 MSPS but the 48-tap time-shared FIR can only produce output pairs every ~50 cycles (~1 MSPS when `filter_en=1`). Because `channel_splitter.s_axis_tready` is tied high, the DMA has no way to know the FIR is busy, so ~98% of samples are lost — and worse, the FIR's delay-line shift registers advance *during* its own MAC computation, causing each accumulator to be computed against a mutating snapshot of the delay line (a silent correctness bug, visible as noisier bandpass-mode DoA estimates). This change wires proper AXI-Stream backpressure end-to-end through the pipeline, making every stage honestly handshake-compliant rather than relying on a "downstream is faster than upstream" timing guarantee. The win is twofold: bandpass/lowpass throughput recovers toward the DMA-limited rate (no more 50× sparsification), and the FIR MACs now operate on a frozen delay line so the arithmetic matches the fixed-point reference.

---

## Problem context (for the thesis chapter)

### Current pipeline

```
DMA (~25 MSPS) ──► channel_splitter ──► fir_filter_sc16 ──► phase_rotate (ch1) ──► interleaver ──► xcorr_acc
                      │                     │                                      │             └► autocorr_acc
                      │                     └─ 48-tap time-shared, ~50 cyc/pair    │
                      │                        (~1 MSPS when filter_en=1,          │
                      │                         1 cyc/pair in bypass)              │
                      └─ s_axis_tready = 1'b1 (CONSTANT — no backpressure)         └─ 2 cyc/pair
```

### Two observed symptoms, one root cause

1. **Throughput:** bandpass/lowpass run at ~3 Hz iteration rate vs bypass's ~10 Hz. The v3 driver works around part of this by polling STATUS at 2 kHz instead of 50 Hz, but the underlying FPGA throughput loss is ~50×.
2. **Noise in filtered mode:** bypass gives <2° std-dev on a static source; bandpass shows visibly noisier angle estimates even after the v3 driver's fixes.

Both symptoms stem from the same RTL decision in `channel_splitter.v:51` — `assign s_axis_tready = 1'b1` — inherited from the original `xcorr_acc_axi` which had no multi-cycle stage downstream.

### Why the delay-line corruption matters even more than raw throughput

In `fir_filter_sc16.v`, the delay-line shift (`always @(posedge clk) if (ch0_tvalid) ...`) is outside the MAC FSM. While the FSM is in `COMP_CH0` or `COMP_CH1`, any new `tvalid` still shifts the delay line. The combinational symmetric-pair wires (`ch0_sym_i`, etc.) read whatever is currently in the array. So over ~50 MAC cycles, the FIR is summing `coeff[k] * (delay_now[k] + delay_now[47-k])` where `delay_now` is mutating under it — each tap's contribution comes from a different snapshot.

In bypass, output is latched in one cycle, so no mutation window exists. That matches the field observation: bypass clean, filter noisy.

---

## Design decisions log

> Each decision below is recorded with **Choice**, **Why**, **Alternatives considered**, **Trade-off accepted**. This log is appended during brainstorming so the rationale is preserved for thesis writeup and future maintenance.

### D1 — Scope: fix the bug, not just the throughput

- **Choice:** Treat this as a correctness + throughput fix, not a throughput-only optimization. Verify the delay-line corruption via iverilog comparison against a NumPy golden reference first, then land backpressure + write regression tests that catch both failure modes.
- **Why:** the project notes's Known Issues entry describes this as a throughput-only problem ("FIR output quality is correct, just throughput-limited"). Reading the RTL carefully shows that framing is incomplete — the delay line mutates mid-MAC whenever the FIR is throttled upstream, so filtered-mode output is off. Catching this now means the backpressure fix also explains the "filter noisy vs bypass clean" asymmetry, which is useful thesis material.
- **Alternatives considered:** (A) ship backpressure alone and keep the Known-Issues framing; (C) treat FIR output as good-enough per v3 driver observations and leave it.
- **Trade-off accepted:** +~20 min of iverilog sim work up front, in exchange for a cleaner narrative and a regression test that prevents this specific failure mode from ever silently reappearing.

### D2 — Backpressure depth: propagate AXI-Stream ready end-to-end

- **Choice:** Make every stage of the pipeline honest-AXI-Stream: `channel_splitter`, `fir_filter_sc16`, `phase_rotate_sc16`, and the wrapper's interleaver all declare `tready` as a real input, and the DMA-facing `s_axis_tready` is the logical AND of all downstream readiness signals (with any needed pipeline-aware buffering).
- **Why:** Today the xcorr/autocorr path only works because the FIR is ~25× slower than the 2-cycle interleaver — it's a timing guarantee, not an architectural one. After adding FIR backpressure we'd still be one optimization away (parallel MACs, shorter taps, DSP block use) from silently overwriting `buf_ch0/buf_ch1`. Making every stage self-defending removes that landmine for the next person (thesis reviewer, future maintainer, future me).
- **Alternatives considered:** (a) only fix the DMA↔splitter↔FIR boundary; rely on timing math to prove the interleaver stays safe.
- **Trade-off accepted:** Touch one more module (`xcorr_acc` handshake) and add one extra "interleaver busy" gate. ~10 additional lines, a few more testbench cases. Worth it for explainability — "the pipeline uses standard AXI-Stream flow control everywhere" is a one-sentence thesis claim; the alternative needs a timing-analysis footnote.

### D3 — Readiness expression lives inside the FIR module

- **Choice:** `fir_filter_sc16` exports its own `m_tready_for_pair` (or equivalent) output. The expression `(state == IDLE) && !ch0_pending && !ch1_pending` is computed inside the module, not by the wrapper.
- **Why:** The readiness condition is a pure function of FIR-internal FSM state. Exposing internals to the wrapper couples two files that should be independent. If the FSM is ever refactored (e.g., to a pipelined MAC with shorter critical path), the ready expression updates in the same file — the wrapper doesn't move. This also matches standard Xilinx/ARM AXI-Stream slave convention: every stream port publishes its own `tready`.
- **Alternatives considered:** (b) expose raw `busy` and compute ready in the wrapper; (c) let `channel_splitter` peek at FIR state directly.
- **Trade-off accepted:** One extra output wire per AXI-Stream slave port in the FIR. Essentially free; the cost is all in the naming/interface design, which we do once.

### D4 — Handshake style at the DMA↔splitter boundary: Xilinx `axis_register_slice`

- **Choice:** Insert Xilinx's stock `axis_register_slice` IP in the Vivado block design between `AXI DMA M_AXIS_MM2S` and `doa_pipeline.s_axis`. `channel_splitter.s_axis_tready` becomes a real input driven combinationally from FIR ready; the register-slice IP registers the handshake toward the DMA.
- **Why:** The RTL change in `channel_splitter.v` is the same size as the pure-combinational approach (~5–8 lines), but routing through Xilinx's certified IP breaks the FIR→DMA combinational path with a registered stage. Benefits:
  - **Zero timing risk** — registered `tready` guarantees no long combinational path from FIR FSM state to the DMA interface, regardless of future clock upgrades or fanout changes.
  - **Zero debug risk on the skid behavior itself** — Xilinx IP has a formal spec and is widely battle-tested; hand-rolled skid buffers have a reputation for off-by-one replay bugs.
  - **Thesis-friendly** — one-sentence description: "an `axis_register_slice` inserts a registered handshake between DMA and the pipeline, standard Xilinx AXI-Stream reference pattern."
  - **Marginal cost** — since we already need a Vivado respin for every other RTL change here, adding one IP block is ~3–5 minutes of block-design editing.
- **Alternatives considered:**
  - **(i) Pure combinational `tready`** driven by FIR ready, no register-slice. Meets timing today (+3.74 ns slack, added AND-gate path costs ~1–2 ns) but creates a long combinational path from FSM state out to the DMA. Works, but fragile to future changes.
  - **(ii) Hand-rolled skid buffer** in Verilog (`held_beat` register + valid flag + replay logic). ~15–25 lines of RTL, reputation for subtle off-by-one bugs in the replay cycle. Pure downside vs (ii').
- **Trade-off accepted:** One extra IP instance in the block design (not in RTL), one additional connectivity validation step during synthesis, plus `axis_register_slice` itself costs a small number of FFs (~100, negligible vs our 43% FF budget). **Fallback if licensing/tool issues block this:** option (i) is a clean drop-in replacement — same `channel_splitter` RTL change, just remove the IP block and wire DMA straight to `doa_pipeline`. The RTL is designed to work in either configuration.

---

## Before/after pipeline diagrams

### Before (current — broken)

```
                                           tready = 1'b1 (hardwired)
                                         ◄────────────────────┐
                                                              │
 [AXI DMA]                                                    │
 MM2S_tdata ─────► [channel_splitter] ── ch0_tvalid ──────┐   │
 MM2S_tvalid ────►                                        │   │
                                       ── ch1_tvalid ──┐  │   │
                                                       │  │   │
                                                       ▼  ▼   │
                                             [fir_filter_sc16]│
                                             (48 taps, ~50    │
                                              cyc/pair MAC)   │
                                                       │      │
                                                       │ one-cycle tvalid pulses
                                                       │ (ch0_out, ch1_out)
                                                       ▼
                                                    [buf_ch0]   (latch w/ valid)
                                                    [buf_ch1]   (latch w/ valid)
                                                       │
                                                 2 cyc drain
                                                       │
                                                       ▼
                                           [xcorr_acc]  (tready dangling)
                                           [autocorr_acc]

 BUGS:
   ▲ DMA sends at ~25 MSPS, FIR consumes at ~1 MSPS → 98% of samples
     never enter the MAC. Throughput bottleneck.
   ▲ Delay-line shift registers in the FIR advance on EVERY tvalid —
     even while the MAC FSM is mid-computation. So each MAC sum is
     taken over a mutating snapshot of the delay line. Correctness bug,
     visible as noisy filtered-mode DoA estimates (vs clean bypass).
```

### After (proposed — fixed)

```
                              ┌──── registered tready ─────┐
                              │                            │
 [AXI DMA]                    │                            │
 MM2S_tdata ─────►[axis_register_slice]─ tdata ──►[channel_splitter]
 MM2S_tvalid ────► (Xilinx IP,            tvalid            │
                    1-deep skid,          tready ◄──────────┘ (combinational
                    registered ports)                          from fir_ready)
                                                               │
                                                               │ tready into
                                                               │ splitter =
                                                               │ FIR's published
                                                               │ ready
                                                               ▼
                                                     [fir_filter_sc16]
                                                     publishes:
                                                       m_ready (= IDLE && !pending)
                                                       m_tvalid (output pair)
                                                     expects:
                                                       m_tready (from interleaver)
                                                               │
                                                               │ FIR holds its
                                                               │ OUTPUT state
                                                               │ until interleaver
                                                               │ accepts
                                                               ▼
                                                     [interleaver]
                                                     drops m_tready when
                                                     buf_ch0_valid &&
                                                     buf_ch1_valid
                                                               │
                                                               ▼
                                                     [xcorr_acc]   (publishes
                                                                    tready = 1'b1,
                                                                    declared)
                                                     [autocorr_acc] (same)

 FIXES:
   ▲ DMA can be told "wait" — tready goes low while FIR MAC is running.
     When FIR finishes (~50 cycles later) and its output pair is drained
     by the interleaver, tready rises again. No more dropped samples.
   ▲ Because the FIR no longer accepts new samples during COMP_CH0/COMP_CH1,
     the delay lines cannot shift mid-MAC. Each accumulator sees a consistent
     snapshot. Arithmetic now matches the fixed-point reference.
   ▲ Every AXI-Stream port in the pipeline publishes its own tready.
     Implicit timing invariants ("xcorr faster than FIR") are replaced
     with explicit handshake — the RTL is honestly flow-controlled.
```

### Flow-control legend

```
  ─────►  tdata / tvalid  (data flowing downstream)
  ◄─────  tready          (backpressure flowing upstream)
  [box]   RTL module or Xilinx IP
```

---

## Design (to be filled in as we confirm each section)

### Architecture change summary

Summary of what moves where, in one paragraph per scope:

**Block design.** Insert one `axis_register_slice` IP between `axi_dma_0/M_AXIS_MM2S` and `doa_pipeline_0/s_axis`. No other BD changes; same clock, same reset, same register-map base address. All 15 AXI-Lite registers keep their current offsets and semantics.

**RTL.** Three modules gain AXI-Stream `tready` handshake ports; one module gets a correctness fix on its delay-line shift gating. Concretely:
- `channel_splitter.v` — `s_axis_tready` goes from `1'b1` to a combinational function of downstream FIR ready.
- `fir_filter_sc16.v` — publishes `m_ready` (slave-side) and `m_tready`-aware `m_tvalid` (master-side); delay-line shift gated on `state == IDLE`.
- `phase_rotate_sc16.v` — declares `s_tready` and `m_tready`, trivially always ready.
- `xcorr_acc.v` — declares `s_axis_tready = 1'b1` instead of leaving it dangling.
- `doa_pipeline.v` — wires the new handshake signals; interleaver asserts "not ready" when both `buf_ch*_valid` are set.

**Testbenches.** Five files touched (one new Python post-process script), all additive — existing test cases stay. See D5 for the full inventory.

**Driver (`cora_headless/aoa_estimation_fpga_v3.py`).** **No change** expected. Register map is identical; STATUS semantics unchanged. The current 0.5 ms STATUS poll timeout may become unnecessary once bandpass throughput recovers, but leaving it at 0.5 ms is harmless.

**Yocto / rootfs.** **No change.** Same bitstream loader, same init.d script, same udev rules. Only the `BOOT.BIN` / bitstream on the Phase A SD card changes. Phase 0 fallback card remains untouched as escape hatch.

**Measured expected impact.** Bandpass iteration rate: 3 Hz → ≥ 8 Hz (targeting closer to 10 Hz bypass rate). Filtered-mode DoA std-dev: drops to within 1.5× of bypass (currently visibly worse). No change to bypass mode, since `filter_en=0` already avoids the MAC path entirely.

### Module interface changes

All changes are **additive** — existing ports keep their names. New ports are added to carry the AXI-Stream ready signal at each stage.

#### `channel_splitter.v`
- `s_axis_tready` changes from internally-driven (`= 1'b1`) to **combinationally driven** by a new input port wired to the downstream FIR's `m_ready`.
- Add ports:
  - `input wire s_axis_tready_in` *(new — gating signal; the module's own `s_axis_tready` output is a pass-through plus the beat-phase gate)*
- Beat-phase FSM now advances only when `s_axis_tvalid && s_axis_tready` (AXI-Stream handshake).

#### `fir_filter_sc16.v`
- Add ports:
  - `output wire m_ready` — slave-side ready: asserts when the FIR can accept a new sample pair (`state == IDLE && !ch0_pending && !ch1_pending`).
  - `output reg m_tvalid` — master-side valid: rises one cycle after the OUTPUT state, **stays high until `m_tready` is asserted** (previously was a one-cycle pulse).
  - `input wire m_tready` — master-side ready, from interleaver.
- The existing `ch0_out_tvalid` / `ch1_out_tvalid` one-cycle pulses are **replaced** by the handshake-compliant `m_tvalid` / `m_tready` pair. (ch0/ch1 data emit together; no more implicit two-port semantics.)
- Delay-line shift is **gated on `state == IDLE`** — this is the correctness fix. Shifts only happen between MACs, not during.

#### `phase_rotate_sc16.v`
- Add ports:
  - `output wire s_tready` — trivially always high (single-cycle combinational rotate); declared for protocol compliance.
  - `input wire m_tready` — pass-through to the slave-side ready of the sink.
- Internal latency is 1 cycle; `m_tvalid` stays high until `m_tready`.

#### `xcorr_acc.v`
- Add port:
  - `output wire s_axis_tready` — declared and tied to `1'b1`. Formalizes what was previously dangling.

#### `doa_pipeline.v` (wrapper)
- Wire the new ready signals:
  - `splitter.s_axis_tready_in  ← fir.m_ready`
  - `fir.m_tready               ← interleaver's "not full" signal (`!(buf_ch0_valid && buf_ch1_valid)`)`
  - `rotate.m_tready            ← interleaver's "not full" signal` (same condition as FIR)
- The interleaver block (lines 178-239 of current `doa_pipeline.v`) gets a small rewrite: clear `buf_ch0_valid`/`buf_ch1_valid` at the right handshake edges, assert "not ready" while both are full.
- Block-design level: insert `axis_register_slice` between AXI DMA `M_AXIS_MM2S` and the new `doa_pipeline.s_axis` port. Both sides keep `TDATA_WIDTH=32`. Default config (1-deep skid, both `REG_CONFIG=1`).

### Testbench plan

#### D5 — Dual verification path: Verilog behavioral reference (A2) + Python NumPy diff (A1)

- **Choice:** Run both an in-simulation Verilog behavioral reference model and a Python post-process comparison, rather than pick one.
- **Why:**
  - **A2 alone** gives fast pass/fail in `vvp` — good for iterating on the RTL fix, but no visualization.
  - **A1 alone** gives thesis-quality comparison plots (delay-line-corrupted output overlaid with fixed output and golden reference) but requires a two-step flow.
  - **A1's cost is near zero** because the NumPy reference already exists in `cora_headless/aoa_estimation_fpga_v3.py` — same windowed-sinc coefficients, same convolution. We wrap it as a function and reuse.
  - **A2's cost is one-time** (~30 lines of Verilog behavioral FIR in the testbench).
  - Together you get: fast local iteration (A2) + a thesis figure that literally shows the bug and the fix side by side (A1).
- **Alternatives considered:** Pick one; skip investigation entirely and hope the fix works (rejected in D1).
- **Trade-off accepted:** One extra `$fwrite` in `tb_fir_filter_sc16` to dump input/output as CSV (~5 lines) and a Python script (~40 lines, mostly matplotlib) under `fpga/tb/plot_fir_diff.py`. Thesis figure is worth it.

#### Test case inventory

Added in this change:

1. **`tb_channel_splitter`** — new case: drop `tready` for N cycles, verify `beat_phase` does not advance until tready rises. Verify last-held beat replays on rising tready.
2. **`tb_fir_filter_sc16`** —
   - Full-rate input test (ties `s_axis_tvalid=1` every cycle) against the **in-sim Verilog behavioral reference** (A2). On the current RTL this should FAIL; after the fix, PASS.
   - `m_tready` stall test: hold `m_tready` low, verify `m_tvalid` stays high (pair held, not re-emitted) and that `m_ready` (slave-side) goes low (FIR refuses new input pairs).
   - `$fwrite` dump of input/output CSV for Python post-process (A1).
3. **`tb_doa_pipeline`** — full-rate DMA test that counts N snapshots, verifies `SNAP_COUNT` matches expected (today this test would show 1/50 the expected count).
4. **`tb_xcorr_acc`** — trivial: verify tready is now declared and stays high.
5. **`fpga/tb/plot_fir_diff.py`** (new) — reads CSV dump from #2, computes NumPy golden reference, emits max-abs-error / std-dev metrics and a 3-trace comparison plot (current-RTL, fixed-RTL, golden).

#### Regression protection

The full-rate test in `tb_fir_filter_sc16` is the one that catches this specific bug class. If a future refactor ever breaks backpressure (e.g., someone re-ties `s_axis_tready = 1'b1` in `channel_splitter`), the delay-line corruption returns and this test fails. That's exactly the regression-prevention guarantee we want.

### Vivado respin checklist

On the build VM (`vmau@192.168.122.93`), project `cora_doa_hw`:

1. **Copy updated RTL** to the VM's project source tree (same paths used in `fpga/rtl/`).
2. **Open block design** (`cora_doa_hw.xpr → design_1.bd`).
3. **Insert `axis_register_slice`** between `axi_dma_0/M_AXIS_MM2S` and `doa_pipeline_0/s_axis`. Default config. Connect `aclk` and `aresetn` to the existing 50 MHz domain.
4. **Validate design** — connectivity check should pass with no new warnings (besides the existing harmless `xfft_0 s_axis_data_tvalid` one).
5. **Run synthesis** — check LUT/FF/DSP deltas are small (expect <1% change). WNS should stay comfortably positive.
6. **Run implementation** — verify timing met (WNS still positive, TNS = 0). **If the `doa_pipeline/splitter/fir` critical path degrades below ~+1 ns slack, re-examine:** likely the interleaver "not full" signal needs a registered stage.
7. **Generate bitstream.**
8. **Export hardware** (`.xsa`) and update the Cora Phase A SD card's `BOOT.BIN` / device tree if needed (no DT change expected — same IP, same register map).

Exit criteria for the VM side: clean implementation report, positive slack, bitstream in hand.

### Verification on Cora

The pre-change Phase A SD card is preserved as the **A/B baseline** — any behavioral regression can be diagnosed by a card swap rather than a git bisect.
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

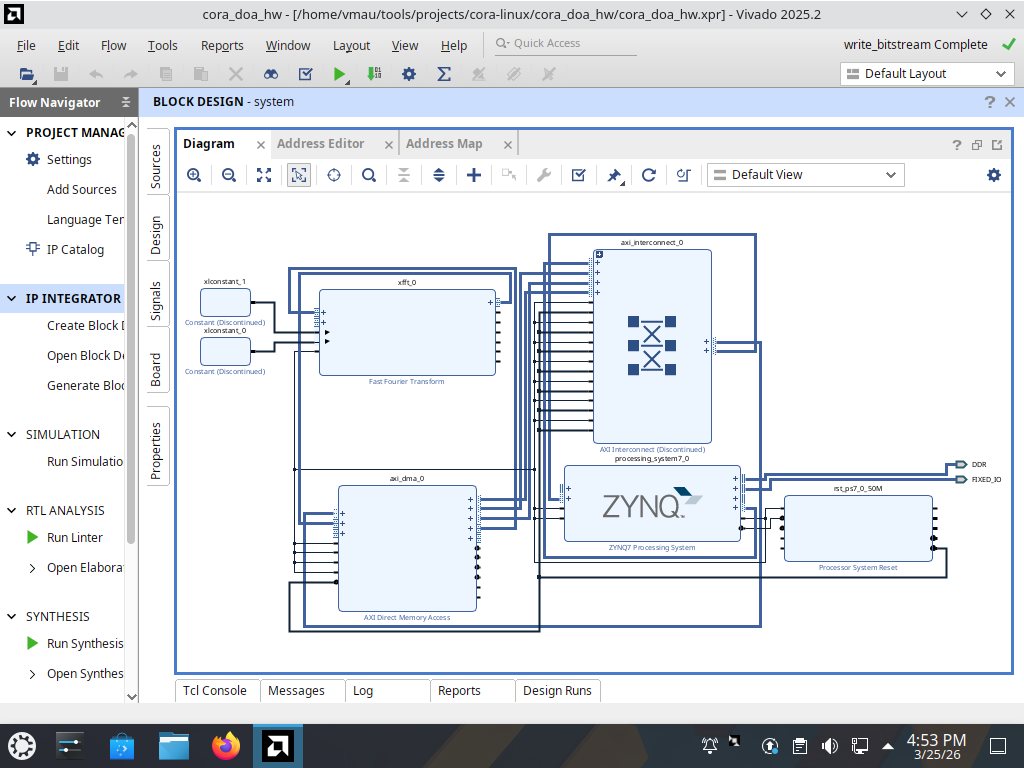
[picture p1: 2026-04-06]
fpga/notes/vivado_block_design_2026-03-25.png

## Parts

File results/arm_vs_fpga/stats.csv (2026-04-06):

filename | mode | algo | group | true_angle_deg | calibration_deg | source | n_total | n_used | mean_deg | median_deg | std_deg | mad_deg | bias_deg | mean_folded_deg | std_folded_deg | mad_folded_deg | bias_folded_deg
aoa_ARM_ROOTMUSIC_20180309_171310.csv | ARM | ROOTMUSIC | rootmusic_pair_90deg | 90.0 |  | yaml | 344 | 338 | 93.92662721893493 | 108.2 | 19.685223212423487 | 5.75 | 3.926627218934925 | 70.35384615384616 | 3.9818952289385168 | 2.25 | -19.646153846153837
aoa_FPGA_ROOTMUSIC_20180309_171428.csv | FPGA | ROOTMUSIC | rootmusic_pair_90deg | 90.0 |  | yaml | 102 | 100 | 99.04400000000001 | 94.94999999999999 | 13.462648065269065 | 11.000000000000014 | 9.044000000000011 | 77.30999999999999 | 10.059836133372306 | 6.04999999999999 | -12.690000000000012
aoa_ARM_MUSIC_20180309_181138.csv | ARM | MUSIC | music_pair_90deg | 90.0 |  | yaml | 1038 | 1034 | 100.20599613152805 | 116.0 | 47.14521163881357 | 31.0 | 10.205996131528053 | 45.3394584139265 | 18.177990854252865 | 13.0 | -44.6605415860735
aoa_FPGA_MUSIC_20180309_181642.csv | FPGA | MUSIC | music_pair_90deg | 90.0 |  | yaml | 273 | 271 | 86.54612546125462 | 77.0 | 37.88379764254421 | 31.0 | -3.4538745387453815 | 56.398523985239855 | 17.717637102051114 | 11.0 | -33.601476014760145

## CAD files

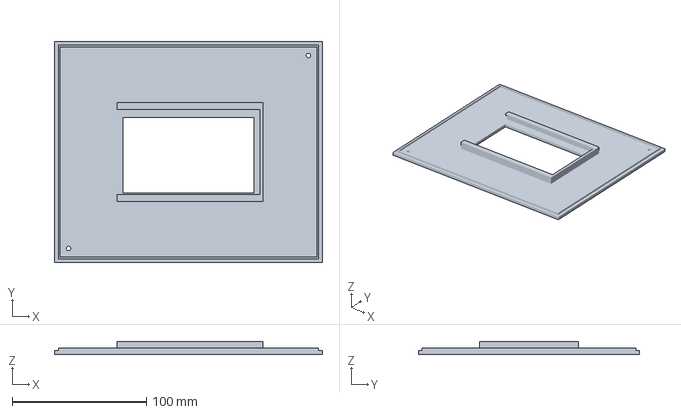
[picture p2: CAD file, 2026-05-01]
hardware/doa_enclosure_lid.3mf
200.0 x 165.0 x 10.0 mm

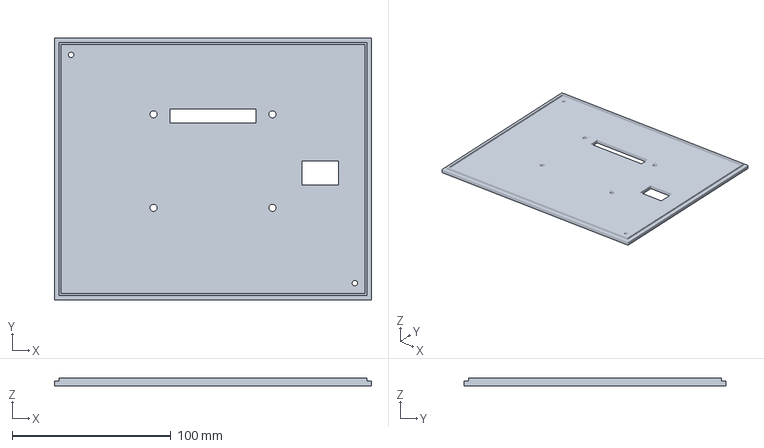
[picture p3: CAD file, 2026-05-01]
hardware/lid_testlid.3mf
200.0 x 165.0 x 5.00 mm

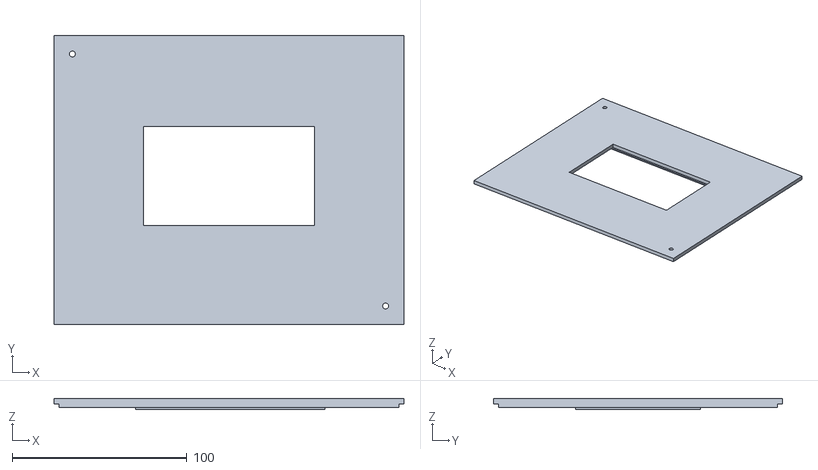
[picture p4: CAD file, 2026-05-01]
hardware/doa_enclosure_lid3.stl
200.0 x 165.0 x 6.00

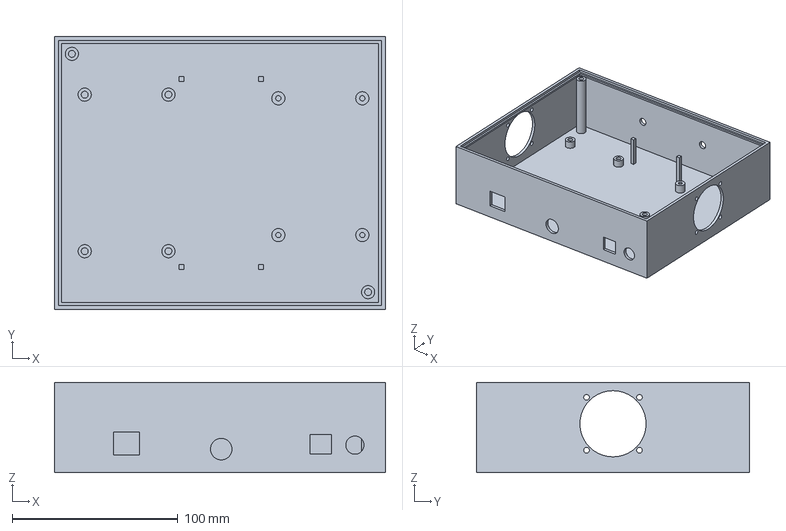
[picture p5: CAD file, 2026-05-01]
hardware/doa_enclosure_body.3mf
200.0 x 165.0 x 54.5 mm

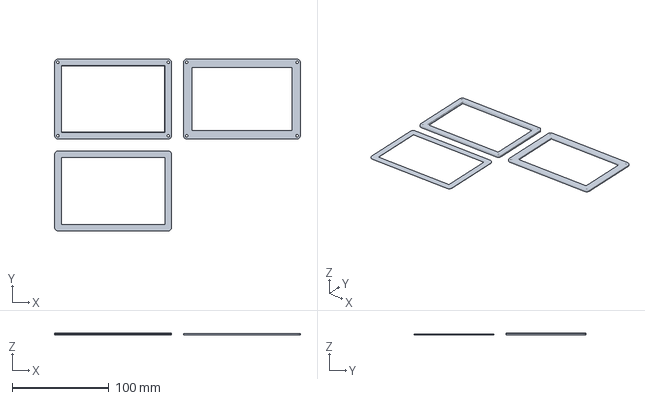
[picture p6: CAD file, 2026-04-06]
hardware/display_bezel.3mf
253.9 x 177.6 x 2.50 mm

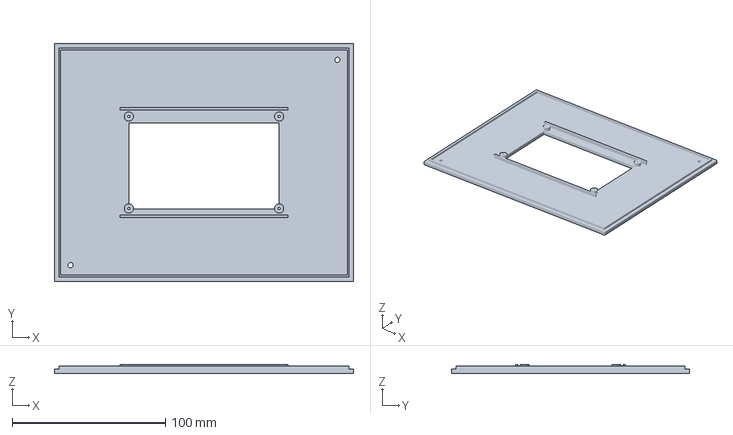
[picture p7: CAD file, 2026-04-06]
hardware/doa_enclosure_lid2.3mf
195.0 x 155.0 x 6.00 mm

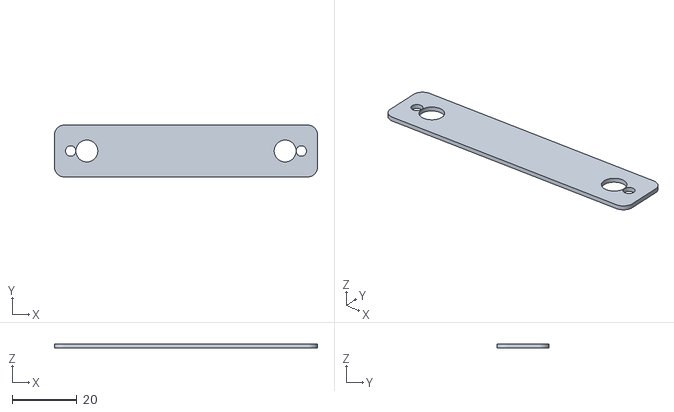
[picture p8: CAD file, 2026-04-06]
hardware/antenna_bracket.stl
81.2 x 16.0 x 1.20

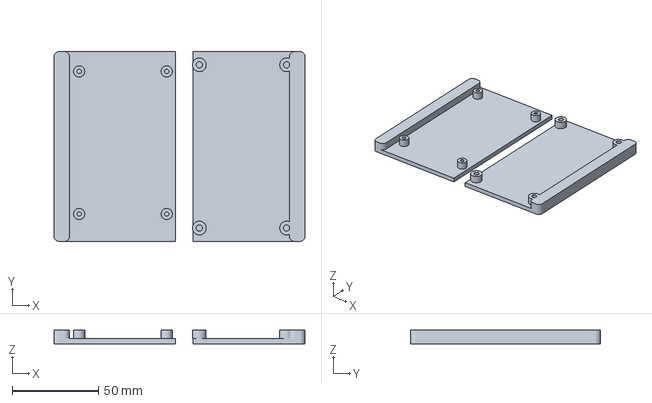
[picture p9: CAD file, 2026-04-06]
hardware/board_tray.3mf
145.5 x 110.0 x 8.00 mm

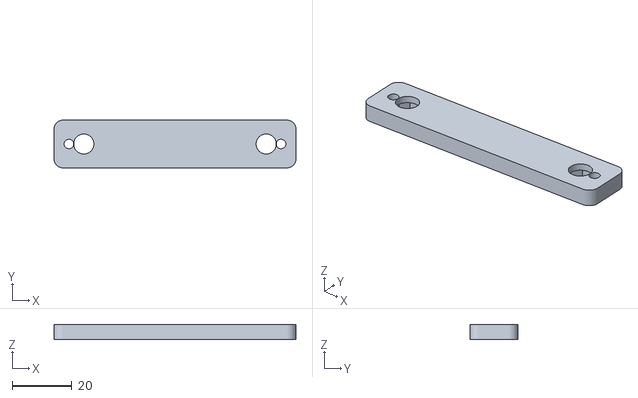
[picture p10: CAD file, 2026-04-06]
hardware/antenna_bracke_1.stl
81.2 x 16.0 x 5.00

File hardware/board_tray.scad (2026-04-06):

/* =========================================================
   Sliding Board Tray — BladeRF 2.0 xA4 + Cora Z7
   For Meijia Portable Case  (268 x 153 x 52.8mm bottom)

   Both boards side by side on standoffs. Tray slides
   along the case length, leaving ~158mm for battery,
   DC-DC converter, fans, and wiring in the other half.

   Layout (top view inside case):
   ┌────────────────────────────────────────────────┐
   │                                                │
   │  ┌──────────┬──┬────────┐                      │
   │  │ BladeRF  │  │ Cora   │                      │
   │  │ 63.5 x   │  │ 58 x   │  ← tray ~110mm      │ 153mm
   │  │ 101.25   │  │ 102    │                      │
   │  │ (SMAs ↓) │  │        │                      │
   │  └──────────┴──┴────────┘                      │
   │     ~140mm wide                                │
   │     ← slides along 268mm, ~158mm free →        │
   └────────────────────────────────────────────────┘
                       268mm

   Board measurements (from calipers):
     BladeRF PCB:  63.5 x 101.25mm  (excl. SMA/barrel/ethernet)
       Holes: 50.74 x 82.65mm spacing, D=2.6mm
       Right edge to right hole center: 5.16mm
       SMA edge to front hole center: ~11.5mm
     Cora Z7 PCB:  58 x 102mm
       Holes: 50.6 x 94.6mm spacing, D=3.67mm
       Hole edge to PCB edge: 1.9mm → center offset ~3.7mm

   Print settings:
     Orientation : flat on bed (rails face up)
     Layer height : 0.20 mm
     Infill       : 30-40%
     Supports     : none needed
     Material     : PETG preferred (stiffer than PLA for a tray)
   ========================================================= */


// ── CASE DIMENSIONS ─────────────────────────────────────

case_inner_l = 268;     // mm  (length, long axis)
case_inner_w = 153;     // mm  (width, short axis)
case_inner_d =  52.8;   // mm  (bottom half depth)


// ── BOARD DIMENSIONS (PCB only, excl. connectors) ───────

// BladeRF 2.0 xA4
bladerf_w = 63.5;       // mm  (short axis — SMA connector edge)
bladerf_l = 101.25;     // mm  (long axis)

// Cora Z7
cora_w = 58;             // mm  (short axis)
cora_l = 102;            // mm  (long axis)


// ── TRAY PARAMETERS — ADJUST THESE ─────────────────────

// Clearance between tray edges and case walls
wall_clearance = 0.5;   // mm per side

// Gap between the two boards (cable routing slot)
board_gap = 10;          // mm — USB + power cables route through here

// Border around boards on the tray
tray_border = 4;         // mm on each side

// Base plate
base_t = 3.0;           // mm thickness

// Side rails (run along the tray length on both sides)
rail_h = 5.0;           // mm above base top surface
rail_w = 3.0;           // mm wide

// Standoff height (airflow clearance under boards)
standoff_h = 5.0;       // mm above base top

// BladeRF standoffs (M2.5 screws through 2.6mm holes)
bladerf_standoff_d = 6.5;    // mm outer diameter
bladerf_screw_d    = 2.6;    // mm  (matches board holes)

// Cora Z7 standoffs (M3 screws through 3.67mm holes)
cora_standoff_d = 8.0;       // mm outer diameter
cora_screw_d    = 3.67;      // mm  (matches board holes)

// Rounded corners
corner_r = 3.0;          // mm

$fn = 48;


// ── MOUNTING HOLES (measured with calipers) ─────────────
//
// Each entry is [x, y] from the board's bottom-left corner.
// x = along board width (short axis)
// y = along board length (long axis)

// BladeRF 2.0 xA4
// Hole spacing: 50.74mm (W) x 82.65mm (L), D=2.6mm
// Right edge → right hole center: 5.16mm
// SMA edge (y=0) → front hole center: ~11.5mm
bladerf_hole_x_right = bladerf_w - 5.16;               // = 58.34
bladerf_hole_x_left  = bladerf_hole_x_right - 50.74;   // = 7.60
bladerf_hole_y_front = 11.5;                            // ~11.5 (SMA side)
bladerf_hole_y_back  = 11.5 + 82.65;                   // = 94.15

board_bladerf_holes = [
    [bladerf_hole_x_left,  bladerf_hole_y_front],   // front-left
    [bladerf_hole_x_right, bladerf_hole_y_front],   // front-right
    [bladerf_hole_x_left,  bladerf_hole_y_back],    // back-left
    [bladerf_hole_x_right, bladerf_hole_y_back],    // back-right
];

// Cora Z7
// Hole spacing: 50.6mm (W) x 94.6mm (L), D=3.67mm
// Hole edge to PCB edge: 1.9mm → center = 1.9 + 3.67/2 = 3.735mm
cora_hole_offset = 1.9 + 3.67 / 2;   // = 3.735mm from each edge

board_cora_holes = [
    [cora_hole_offset,          cora_hole_offset],            // bottom-left
    [cora_hole_offset + 50.6,   cora_hole_offset],            // bottom-right
    [cora_hole_offset,          cora_hole_offset + 94.6],     // top-left
    [cora_hole_offset + 50.6,   cora_hole_offset + 94.6],     // top-right
];


// ── DERIVED ─────────────────────────────────────────────

// Both boards side by side along X (width), long axes along Y (length)
boards_max_l = max(bladerf_l, cora_l);   // = 102mm (Cora slightly longer)

// Tray outer dimensions
tray_w = tray_border + bladerf_w + board_gap + cora_w + tray_border;  // ~139.5mm
tray_l = tray_border + boards_max_l + tray_border;                     // ~110mm

// Board origins on tray (bottom-left corner of each PCB)
// Both centered vertically (Y) on the tray
bladerf_x = tray_border;
bladerf_y = tray_border + (boards_max_l - bladerf_l) / 2;   // +0.375mm centering

cora_x = tray_border + bladerf_w + board_gap;
cora_y = tray_border + (boards_max_l - cora_l) / 2;          // +0mm (longest board)

// Cable slot between boards (vertical cut along Y axis)
slot_x_pos = tray_border + bladerf_w;    // starts at right edge of BladeRF
slot_y_pos = 0;                           // full tray length

echo("─── Tray dimensions ─────────────────────────────────");
echo(str("  Tray (W x L x base):       ", tray_w, " x ", tray_l, " x ", base_t, " mm"));
echo(str("  Total height (base+rail):   ", base_t + rail_h, " mm"));
echo(str("  Slide range along length:   ", case_inner_l - tray_l, " mm"));
echo(str("  Slide range across width:   ", case_inner_w - tray_w, " mm"));
echo(str("  Free along case length:     ", case_inner_l - tray_l, " mm"));
echo(str("  BladeRF origin on tray:     (", bladerf_x, ", ", bladerf_y, ")"));
echo(str("  Cora origin on tray:        (", cora_x, ", ", cora_y, ")"));
echo("─────────────────────────────────────────────────────");


// ─────────────────────────────────────────────────────────
// Helpers
// ─────────────────────────────────────────────────────────

module rounded_box(l, w, h, r) {
    hull() {
        for (xi = [r, l - r])
        for (yi = [r, w - r])
            translate([xi, yi, 0])
                cylinder(r = r, h = h);
    }
}

// Parametric standoff: different hole/OD per board
module standoff(x, y, od, id) {
    translate([x, y, base_t]) {
        difference() {
            cylinder(d = od, h = standoff_h);
            translate([0, 0, -0.1])
                cylinder(d = id, h = standoff_h + 0.2);
        }
    }
}


// ─────────────────────────────────────────────────────────
// BOARD TRAY — main module
// ─────────────────────────────────────────────────────────
//
//  Top view:
//    ┌──────────────────────────────────┐
//    │  ┌──────────┐ slot ┌──────────┐  │
//    │  │ BladeRF  │      │ Cora Z7  │  │
//    │  │ 63.5mm   │      │  58mm    │  │
//    │  │          │      │          │  │
//    │  └──────────┘      └──────────┘  │
//    └──────────────────────────────────┘
//       rail (left)          rail (right)
//
//  Side view (cross-section along X):
//       rail                              rail
//    ┌──┐                                ┌──┐
//    │  │  ○ BladeRF      ○ Cora         │  │
//    │  ├──┤══════════╡  ╞══════════════─┤  │
//    └──┴──┴──────────┘  └───────────────┴──┘
//           base plate    cable slot    base plate

module board_tray() {
    difference() {
        union() {
            // ① Base plate
            rounded_box(tray_w, tray_l, base_t, corner_r);

            // ② Side rails (along Y axis, both X edges)
            // Left rail (x=0)
            rounded_box(rail_w, tray_l, base_t + rail_h, corner_r);
            // Right rail (x=tray_w)
            translate([tray_w - rail_w, 0, 0])
                rounded_box(rail_w, tray_l, base_t + rail_h, corner_r);

            // ③ BladeRF standoffs (M2.5, D=2.6mm holes)
            for (h = board_bladerf_holes)
                standoff(
                    bladerf_x + h[0],
                    bladerf_y + h[1],
                    bladerf_standoff_d,
                    bladerf_screw_d
                );

            // ④ Cora Z7 standoffs (M3, D=3.67mm holes)
            for (h = board_cora_holes)
                standoff(
                    cora_x + h[0],
                    cora_y + h[1],
                    cora_standoff_d,
                    cora_screw_d
                );
        }

        // ⑤ Cable routing slot between boards (through base plate)
        //    Runs along Y axis between the two boards
        translate([slot_x_pos, -0.1, -0.1])
            cube([board_gap, tray_l + 0.2, base_t + 0.2]);
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

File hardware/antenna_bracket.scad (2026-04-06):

/* =========================================================
   Antenna Bracket — 2-element ULA mount for Meijia case lid

   Holds two SMA bulkhead connectors at exactly λ/2 spacing
   (61.2mm center-to-center @ 2.45 GHz).

   Mounts on the lid exterior, centered along the top long
   edge (opposite hinges, away from display cutout).

   Antennas fold flat when lid is closed, flip up 90° for use.

   Cross-section (lid closed):
       outside
   ┌────────────────────────┐
   │  ant1 (flat)  ant2     │  ← antennas folded
   │  ┌──┐  61.2mm  ┌──┐   │
   │  │SMA│         │SMA│   │  ← bracket
   ├──┴──┴──────────┴──┴────┤
   │        LID             │
   └────────────────────────┘
       inside

   Print settings:
     Orientation : flat on bed (mounting face down)
     Layer height: 0.15-0.20 mm
     Infill      : 50%+ (small part, needs rigidity)
     Supports    : none
     Material    : PETG preferred
   ========================================================= */


// ── ANTENNA PARAMETERS ─────────────────────────────────

// λ/2 spacing at 2.45 GHz
element_spacing = 61.2;        // mm center-to-center

// SMA bulkhead barrel diameter (standard = 6.35mm / 1/4")
// Measure yours and adjust if different
sma_barrel_d = 6.35;           // mm — hole for the SMA barrel
sma_clearance = 0.2;           // mm — fit tolerance per side
sma_hole_d = sma_barrel_d + 2 * sma_clearance;  // = 6.75mm

// SMA nut flat-to-flat (hex nut that tightens from inside)
// Standard SMA nut is ~8mm across flats
sma_nut_af = 8.0;              // mm across flats
sma_nut_h  = 3.0;              // mm nut height
// Hex recess diameter (circumscribed circle of hex)
sma_nut_d  = sma_nut_af / cos(30);  // ~9.24mm


// ── BRACKET PARAMETERS ─────────────────────────────────

// Bracket body
bracket_t   = 5.0;            // mm — thickness (SMA barrel + nut must fit)
bracket_h   = 16.0;           // mm — height (short axis, perpendicular to lid edge)
bracket_pad = 10.0;           // mm — padding beyond each SMA hole

// Derived length
bracket_l = element_spacing + 2 * bracket_pad;  // ~81.2mm

// Corner rounding
corner_r = 3.0;               // mm

// Mounting holes (M3 screws to attach bracket to lid)
mount_screw_d = 3.2;          // mm — M3 clearance hole
// Mounting holes placed at each end of the bracket
mount_inset_x = bracket_pad / 2;   // mm from bracket ends
mount_inset_y = bracket_h / 2;     // mm — centered vertically

$fn = 60;


// ── DERIVED POSITIONS ──────────────────────────────────

// SMA holes centered vertically, spaced along length
sma1_x = bracket_pad;                        // = 10mm from left edge
sma1_y = bracket_h / 2;
sma2_x = bracket_pad + element_spacing;      // = 71.2mm from left edge
sma2_y = bracket_h / 2;

echo("─── Antenna Bracket ─────────────────────────────────");
echo(str("  Element spacing:    ", element_spacing, " mm (λ/2 @ 2.45 GHz)"));
echo(str("  Bracket (L×H×T):    ", bracket_l, " × ", bracket_h, " × ", bracket_t, " mm"));
echo(str("  SMA hole diameter:  ", sma_hole_d, " mm"));
echo(str("  SMA 1 position:     (", sma1_x, ", ", sma1_y, ")"));
echo(str("  SMA 2 position:     (", sma2_x, ", ", sma2_y, ")"));
echo("─────────────────────────────────────────────────────");


// ── HELPERS ────────────────────────────────────────────

module rounded_rect(l, w, h, r) {
    hull() {
        for (xi = [r, l - r])
        for (yi = [r, w - r])
            translate([xi, yi, 0])
                cylinder(r = r, h = h);
    }
}

// Hexagonal recess for SMA nut (cut from bottom)
module hex_recess(af, h) {
    d = af / cos(30);
    cylinder(d = d, h = h, $fn = 6);
}


// ── MAIN BRACKET ───────────────────────────────────────

module antenna_bracket() {
    difference() {
        // ① Solid body
        rounded_rect(bracket_l, bracket_h, bracket_t, corner_r);

        // ② SMA barrel holes (through)
        for (pos = [[sma1_x, sma1_y], [sma2_x, sma2_y]]) {
            translate([pos[0], pos[1], -0.1])
                cylinder(d = sma_hole_d, h = bracket_t + 0.2);
        }

        // ③ Hex nut recesses on bottom face (so nut sits flush)
        for (pos = [[sma1_x, sma1_y], [sma2_x, sma2_y]]) {
            translate([pos[0], pos[1], -0.1])
                hex_recess(sma_nut_af, sma_nut_h + 0.1);
        }

        // ④ Mounting screw holes (M3, through)
        for (mx = [mount_inset_x, bracket_l - mount_inset_x]) {
            translate([mx, mount_inset_y, -0.1])
                cylinder(d = mount_screw_d, h = bracket_t + 0.2);
        }
    }
}


// ── LID DRILL TEMPLATE (optional) ─────────────────────
// Thin plate with hole positions marked — tape to lid,
// drill through the marked holes.

module lid_template() {
    template_t = 1.2;    // thin enough to print fast

    difference() {
        rounded_rect(bracket_l, bracket_h, template_t, corner_r);

        // SMA holes (mark only, same diameter)
        for (pos = [[sma1_x, sma1_y], [sma2_x, sma2_y]]) {
            translate([pos[0], pos[1], -0.1])
                cylinder(d = sma_hole_d, h = template_t + 0.2);
        }

        // Mounting holes
        for (mx = [mount_inset_x, bracket_l - mount_inset_x]) {
            translate([mx, mount_inset_y, -0.1])
                cylinder(d = mount_screw_d, h = template_t + 0.2);
        }
    }
}


// ── RENDER ─────────────────────────────────────────────

// Uncomment the part you want to export:

antenna_bracket();
//lid_template();

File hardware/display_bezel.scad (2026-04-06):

/* =========================================================
   Waveshare 4.3" Display Flat-Frame Bezel
   For Meijia Portable Case  (295.9 x 212.1mm lid)

   Display PCB:    106.33 x 68.2 x 8.6mm
   Glass measured: 106.2  x 67.8mm (full glass incl. black frame)
   Active area:    ~95    x 54mm   (inside black frame — window opening)

   Why flat frame (not a deep channel):
     Lid interior depth ≈ 9-10mm  (12.52mm rim - ~3mm panel)
     Display depth     =  8.6mm  → barely fits, no room for a channel
     Solution: frame sits on lid EXTERIOR, display drops straight
     through a cut hole into the lid interior — glass presses
     against the frame back surface from inside.

   Install order:
     1. Print bezel() face-down, lid_template() flat
     2. Lay lid_template on lid exterior, trace & cut hole
     3. M3 screws or 2mm bead of silicone fix frame to lid exterior
     4. From inside, push display glass against frame window
     5. Run a bead of silicone around PCB edges from inside
     6. Optional: print back_retainer() and screw in for positive lock

   Print settings:
     Orientation : face DOWN (flat on bed — cleanest window edges)
     Layer height : 0.15 mm
     Infill       : 40%
     Supports     : none needed
   ========================================================= */


// ── ADJUST THESE ──────────────────────────────────────────

// Screen window opening = full glass (including black border frame)
// Measured from display face
screen_l = 106.2;   // mm  (full glass, long axis)
screen_w =  67.8;   // mm  (full glass, short axis)

// Fit tolerance on each side of PCB channel (back pocket + lid hole)
// 0.25 = snug | 0.4 = loose
clearance = 0.30;   // mm per side

// Frame thickness (how far screen glass sits below lid surface)
// Thicker = stronger frame, deeper recess. 2.5mm is a good balance.
face_t    = 2.5;    // mm

// Frame border width around the PCB pocket
border    = 7.0;    // mm each side

// Rounded corners
corner_r  = 4.0;    // mm

// Screw holes (M3 pilot, screws come from inside case through lid)
screw_d   = 2.8;    // mm  (2.8 for M3 pilot / heat-insert OD)


// ── FIXED — from datasheet / measurement ─────────────────

pcb_l = 106.33;
pcb_w =  68.20;
pcb_t =   8.60;    // used for back_retainer standoff reference only


// ── DERIVED ───────────────────────────────────────────────

chan_l  = pcb_l + 2 * clearance;   // lid hole to cut = this
chan_w  = pcb_w + 2 * clearance;
outer_l = chan_l + 2 * border;
outer_w = chan_w + 2 * border;

// Back pocket depth: shallow register that centers display on frame
pocket_d = 1.0;    // mm — just enough to locate the PCB

$fn = 64;

echo("─── Bezel dimensions ────────────────────────────────");
echo(str("  Frame (L x W x thick):    ", outer_l, " x ", outer_w, " x ", face_t, " mm"));
echo(str("  CUT LID HOLE (L x W):     ", chan_l,  " x ", chan_w,  " mm"));
echo(str("  Screen window (L x W):    ", screen_l, " x ", screen_w, " mm"));
echo(str("  Border around window:     ", (outer_l-screen_l)/2, " mm each side"));
echo("─────────────────────────────────────────────────────");


// ─────────────────────────────────────────────────────────
// Helper
// ─────────────────────────────────────────────────────────

module rounded_box(l, w, h, r) {
    hull() {
        for (xi = [r, l - r])
        for (yi = [r, w - r])
            translate([xi, yi, 0])
                cylinder(r = r, h = h);
    }
}


// ─────────────────────────────────────────────────────────
// MAIN BEZEL  — print this face-down
// ─────────────────────────────────────────────────────────
//
//  Front (outside of case):
//  ┌─────────────────────────────────────────┐
//  │  ●                                  ●  │  ← corner screw holes
//  │     ┌─────────────────────────────┐     │
//  │     │   SCREEN WINDOW  (air)      │     │
//  │     └─────────────────────────────┘     │
//  │  ●                                  ●  │
//  └─────────────────────────────────────────┘
//  Back (inside of case / against lid):
//  ┌─────────────────────────────────────────┐
//  │     ┌───────────────────────────────┐   │  ← 1mm back pocket
//  │     │  LID HOLE + PCB fits here     │   │    (locates display)
//  │     └───────────────────────────────┘   │
//  └─────────────────────────────────────────┘
//  Display glass rests against the frame back surface
//  around the pocket opening. PCB drops through lid hole.

module bezel() {
    difference() {

        // ① Flat plate
        rounded_box(outer_l, outer_w, face_t, corner_r);

        // ② Screen window — centered, full depth
        translate([(outer_l - screen_l) / 2,
                   (outer_w - screen_w) / 2,
                   -0.1])
            cube([screen_l, screen_w, face_t + 0.2]);

        // ③ Back pocket — shallow recess, matches lid hole
        //   Display glass edge rests on the 1mm step around this opening
        translate([(outer_l - chan_l) / 2,
                   (outer_w - chan_w) / 2,
                   face_t - pocket_d])
            cube([chan_l, chan_w, pocket_d + 0.1]);

        // ④ Corner pilot holes (M3 screws from inside lid)
        si = border / 2;
        for (x = [si, outer_l - si])
        for (y = [si, outer_w - si])
            translate([x, y, -0.1])
                cylinder(d = screw_d, h = face_t + 0.2);
    }
}


// ─────────────────────────────────────────────────────────
// LID CUTTING TEMPLATE  — print flat, place on lid, trace
// Outer outline = frame footprint
// Inner cutout  = the hole to cut through the lid
// ─────────────────────────────────────────────────────────

module lid_template() {
    template_t = 1.2;    // thin — just for tracing
    wall       = 2.0;    // keep inner + outer reference

    translate([0, -(outer_w + 12), 0])
    difference() {
        // Outer reference (same footprint as bezel frame)
        rounded_box(outer_l, outer_w, template_t, corner_r);

        // Inner cutout = lid hole
        translate([(outer_l - chan_l) / 2,
                   (outer_w - chan_w) / 2,
                   -0.1])
            cube([chan_l, chan_w, template_t + 0.2]);
    }
}


// ─────────────────────────────────────────────────────────
// BACK RETAINER  — optional, print separately
// Locks display from inside. Screws through lid into bezel
// pilot holes. Add M3 x 10mm screws + 3.5mm spacers/washers
// to span the lid thickness.
// ─────────────────────────────────────────────────────────

module back_retainer() {
    ret_t = 2.0;

    translate([outer_l + 12, 0, 0])
    difference() {
        rounded_box(outer_l, outer_w, ret_t, corner_r);

        // Central window — clears display body, retains by edges only
        // Make it 4mm smaller each side than the PCB
        inset = 4.0;
        translate([(outer_l - chan_l + inset) / 2,
                   (outer_w - chan_w + inset) / 2,
                   -0.1])
            cube([chan_l - inset, chan_w - inset, ret_t + 0.2]);

        // Corner holes matching bezel pilot holes
        si = border / 2;
        for (x = [si, outer_l - si])
        for (y = [si, outer_w - si])
            translate([x, y, -0.1])
                cylinder(d = screw_d, h = ret_t + 0.2);
    }
}


// ─────────────────────────────────────────────────────────
// Render — comment/uncomment as needed
// ─────────────────────────────────────────────────────────

bezel();
// lid_template();    // uncomment to also render cutting template
// back_retainer();   // uncomment to also render back retainer

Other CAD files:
hardware/doa_enclosure_lid_22.stl
hardware/doa_enclosure_body.scad
hardware/board_tray.stl
hardware/display_bezel.stl
hardware/doa_enclosure_body.stl
hardware/doa_enclosure_lid.scad
hardware/doa_enclosure_lid.stl
hardware/doa_enclosure_lid2.stl
hardware/doa_enclosure_lid_43b.scad
hardware/doa_enclosure_lid_43b_mount.scad
hardware/lid_testlid.stl

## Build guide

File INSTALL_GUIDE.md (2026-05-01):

# DoA-24GHz Installation Guide

Two installation paths depending on what you're trying to do:

| Path | Audience | Hardware required |
|---|---|---|
| **A: Host PC** | Browse the repo, replay captured data, run offline analysis | None — pure Python |
| **B: KV260 deployment** | Reproduce the live capture pipeline | KV260 + BladeRF 2.0 xA4 + 2× whip antennas + nRF5340 (or other 2.4 GHz tone source) |

A Cora Z7 (frozen reference) path also exists on the `feature/fir-backpressure` branch — see the bottom of this document.

---

## Path A: Host PC (offline analysis)

For reading capture sessions, regenerating campaign plots, or browsing the codebase. No SDR or FPGA hardware needed.

### Requirements

- Python 3.10 or newer
- A Linux, macOS, or Windows host with `pip`

### Install

```bash
git clone https://github.com/slopy1/doa_24ghz_t.git
cd doa_24ghz_t
pip install -r requirements.txt
```

### Sanity check

```bash
# Re-render an existing campaign's plots from CSV/JSON
python3 scripts/analyze_campaign.py --campaign-dir results/campaign_20260429_203028_v2/
```

If the script runs without import errors and writes PNGs, your environment is ready.

---

## Path B: KV260 deployment (live capture)

Reproduces the live thesis pipeline. Tested on Ubuntu 22.04 LTS for AMD/Xilinx Kria (`xilinx-zynqmp-common-20232-*` images and Canonical's official Kria image).

### Hardware checklist

| Item | Notes |
|---|---|
| AMD Kria KV260 vision starter kit | K26 SOM, included KV260 carrier card |
| BladeRF 2.0 xA4 | **Barrel-jack 5 V/2 A required** before USB (USB 5 V is insufficient at full RF power) |
| USB 3.0 cable | Type-A to Type-B Micro |
| 2× 2.4 GHz whip antennas | λ/2-spaced (61.2 mm), SMA |
| 2× matched SMA cables, 1× 30 dB attenuator, 1× 2-way splitter | For wired phase calibration |
| nRF5340 DK (or any tunable 2.4 GHz CW source) | Zephyr `radio_test` ch 19 = 2.419 GHz |

### 1. System packages (KV260, Ubuntu 22.04 aarch64)

```bash
sudo apt update
sudo apt install -y \
    build-essential cmake git pkg-config \
    libusb-1.0-0-dev \
    python3-dev python3-pip python3-numpy python3-scipy python3-matplotlib \
    python3-libgpiod libgpiod-dev \
    fpgautil device-tree-compiler
```

The `fpgautil` and `device-tree-compiler` packages come from the AMD/Xilinx Kria archive. If `fpgautil` is missing, follow the [Canonical Kria install guide](https://ubuntu.com/download/amd) to add the Xilinx PPA.

### 2. SoapySDR + libbladeRF + SoapyBladeRF (build from source)

The Ubuntu 22.04 packaged versions of `soapysdr` and `libbladerf` are too old to stream cleanly at 1 MS/s coherent on the Kria. Build all three from upstream:

```bash
# SoapySDR
cd ~ && git clone https://github.com/pothosware/SoapySDR.git
cd SoapySDR && mkdir build && cd build
cmake .. && make -j$(nproc) && sudo make install
sudo ldconfig

# libbladeRF (Nuand)
cd ~ && git clone https://github.com/Nuand/bladeRF.git
cd bladeRF/host && mkdir build && cd build
cmake .. && make -j$(nproc) && sudo make install
sudo ldconfig

# SoapyBladeRF (Pothosware)
cd ~ && git clone https://github.com/pothosware/SoapyBladeRF.git
cd SoapyBladeRF && mkdir build && cd build
cmake .. && make -j$(nproc) && sudo make install
sudo ldconfig
```

Verify:

```bash
SoapySDRUtil --info | grep -i bladerf      # SoapyBladeRF should be listed
SoapySDRUtil --rate-test --args="driver=bladerf" --rate=1e6
# Expect "All complete!" with no overflow warnings.
```

### 3. u-dma-buf (DMA-coherent buffer for the BladeRF → DDR data path)

The KV260 image blocks `/dev/mem` (`CONFIG_STRICT_DEVMEM=y`), so the driver allocates DMA buffers via [u-dma-buf](https://github.com/ikwzm/udmabuf) instead. Build from source (apt and DKMS packages are stale on Ubuntu 22.04 aarch64):

```bash
cd ~ && git clone https://github.com/ikwzm/udmabuf.git
cd udmabuf && make
sudo make install
# Verify the module loads:
sudo modprobe u-dma-buf udmabuf0=12288
ls /sys/class/u-dma-buf/      # should show udmabuf0
```

The u-dma-buf module is non-persistent across reboots — `bench_bringup.sh` re-modprobes on every session.

### 4. BladeRF udev rules

```bash
sudo tee /etc/udev/rules.d/88-nuand.rules > /dev/null << 'EOF'
ATTR{idVendor}=="2cf0", ATTR{idProduct}=="5246", MODE="0660", GROUP="plugdev"
ATTR{idVendor}=="2cf0", ATTR{idProduct}=="5250", MODE="0660", GROUP="plugdev"
EOF
sudo udevadm control --reload-rules && sudo udevadm trigger
sudo usermod -aG plugdev $USER
# log out + back in for the group change
```

### 5. Deploy the driver and bring-up scripts

```bash
# From a host PC:
scp -r kv260_headless/ ubuntu@<kv260-ip>:~/doa/
scp fpga/vivado_kv260/built/*.bit.bin ubuntu@<kv260-ip>:~/doa/
scp fpga/vivado_kv260/built/*.dtbo    ubuntu@<kv260-ip>:~/doa/
scp scripts/bench_bringup.sh          ubuntu@<kv260-ip>:~/doa/
```

### 6. Bring-up + first capture

```bash
# On the KV260:
sudo bash ~/doa/bench_bringup.sh   # idempotent: unloadapp + fpgautil + udmabuf + EMIO gate

# Then run a 60 s capture:
sudo python3 ~/doa/aoa_estimation_fpga_kv260.py \
    --filter none --algo rootmusic --freq 2.418e9 --gain 50
```

You should see real-time AoA estimates printed to stdout at ≈7.7 Hz.

### Gotchas

- **BladeRF barrel jack must be powered before the KV260 USB connection.** USB 5 V at the SoM port is not enough current at full RF gain.
- **`/dev/mem` is blocked.** Use UIO + udmabuf, not `mmap` on `/dev/mem`. Sysfs path is `/sys/class/u-dma-buf/`.
- **`kria-dashboard` snap can reload starter kits mid-session.** If the bitstream evaporates after a few minutes, re-run `bench_bringup.sh` or `sudo snap disable kria-dashboard`.
- **Fan-gate pin A12 must be driven constantly high** in any custom bitstream, or the carrier card thermally shuts the SOM down within 15–60 s. The supplied `kv260_emio_doa.bit.bin` already does this.
- **No RTC** on the carrier — `sudo date -s ...` after each reboot if your captures need real timestamps.

---

## Cora Z7 (legacy reference)

The Cora pipeline is preserved as a validated end-to-end baseline on the `feature/fir-backpressure` branch:

```bash
git fetch origin feature/fir-backpressure
git checkout feature/fir-backpressure
cat cora_headless/README.md   # full deployment notes
```

The Cora path uses GNU Radio 3.10.12 + `gnuradio.soapy` (not gr-osmosdr) + `gr-aoa` and PetaLinux 2025.2. It is not actively maintained on `main` — see the README's "Why two platforms?" section for context.

---

## Troubleshooting

| Issue | First thing to check |
|---|---|
| `SoapySDRUtil --info` doesn't list bladerf | `sudo ldconfig`, confirm SoapyBladeRF install path is in `/usr/local/lib/SoapySDR/modules*/` |
| `bladeRF-cli -p` hangs | Barrel jack 5 V is missing or undervolt — verify with a multimeter |
| Driver immediately exits with `OSError: [Errno 19] No such device` | `bench_bringup.sh` didn't run, or `kria-dashboard` reaped the bitstream |
| `run_snapshot` returns `None` ~12% of the time | Known: fabric STATUS_VALID race; in-flight work, not a configuration error |
| AoA rate ≈ 1 Hz instead of ≈ 7 Hz with `--filter=none` | Pre-2026-04-29 driver — pull latest and rerun |

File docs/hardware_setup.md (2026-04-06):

# Hardware Setup Guide

## Equipment List

| Item | Model | Quantity |
|---|---|---|
| SDR Receiver | Nuand BladeRF 2.0 micro | 1 |
| FPGA Board | Digilent Cora Z7-07S | 1 |
| Antenna | 2.4 GHz whip | 2 |
| Antenna Mount | Aluminum bracket | 1 |
| USB Cable | USB 3.0 Type-A to Micro-B | 1 |
| Power Supply | 5V 3A USB-C (for Cora) | 1 |

## BladeRF 2.0 Configuration

### Channel Mapping

```
         ┌─────────────────────────────┐
         │       BladeRF 2.0           │
         │                             │
   RX0 ◄─┤ SMA (LEFT)     SMA (RIGHT) ├─► RX1
         │                             │
         │     ○ LED    ○ LED          │
         │                             │
         └──────────┬──────────────────┘
                    │
                 USB 3.0
```

- **RX0** = `channel_0` = Left antenna (viewed from behind)
- **RX1** = `channel_1` = Right antenna

### MIMO Synchronization

The BladeRF 2.0 micro uses a single clock for both RX channels, ensuring coherent sampling. No external sync cables needed.

```python
# MIMO configuration
device.sync_config(
    layout=_bladerf.ChannelLayout.RX_X2,  # 2-channel RX
    fmt=_bladerf.Format.SC16_Q11,          # 16-bit I/Q
    num_buffers=32,
    buffer_size=16384,
    num_transfers=16,
    stream_timeout=5000
)
```

## Antenna Array Setup

### Spacing Measurement

```
     ◄───── d = 6.1 cm ─────►
     
    [ANT0]              [ANT1]
       │                   │
       └─────────┬─────────┘
                 │
            Array Center
                 │
                 ▼
            Broadside (θ = 0°)
```

**Target spacing:** d = λ/2 = 6.1 cm at 2.45 GHz

**Measurement method:**
1. Use digital calipers
2. Measure center-to-center
3. Tolerance: ±0.5 mm

### Mounting

- Use rigid aluminum bracket
- Maintain identical antenna heights
- Ensure antennas are parallel
- Avoid metal objects within 20 cm

## TX Setup (Controlled Experiments)

### Option 1: BladeRF TX

Use a second BladeRF (or TX channel of same unit in loopback):

```python
tx = device.Channel(_bladerf.CHANNEL_TX(0))
tx.frequency = int(2.45e9)
tx.sample_rate = int(5e6)
tx.gain = 40  # Adjust for distance
```

### Option 2: ESP32 Beacon

Simple WiFi beacon at 2.4 GHz:
- Constant carrier mode
- Known position
- Battery powered for mobility

## Cora Z7 Setup

### Connections

```
Cora Z7          BladeRF
┌──────┐         ┌──────┐
│      │         │      │
│ PMOD ├─────────┤ GPIO │  (optional, for triggers)
│      │         │      │
│ USB  │         │ USB  │
└──┬───┘         └──┬───┘
   │                │
   └────────────────┴──► Host PC
```

### FPGA Image

The streaming covariance computation runs on PL. See `fpga/` for:
- Vivado project files
- HLS source for cross-correlation IP
- Bitstream

## Software Requirements

```bash
# BladeRF libraries
sudo apt install libbladerf-dev bladerf-fpga-hostedx40

# Python bindings
pip install pybladerf  # or build from source

# Verify connection
bladeRF-cli -p
```

## Troubleshooting

| Issue | Cause | Solution |
|---|---|---|
| Device not found | USB permission | Add udev rule, reconnect |
| Low coherence | Bad cable | Replace SMA cables |
| Clipping | Gain too high | Reduce RX gain |
| No signal | TX off | Check TX script running |
| Phase jumps | Temperature drift | Let warm up 10 min |
| `ImportError: libspdlog.so.1.11` / `libfmt.so.9` when importing `gnuradio.aoa` | `gr-aoa` was built against older `spdlog`/`fmt` SONAMEs (common after a system upgrade) | Run the provided wrappers that set up a tiny compat `LD_LIBRARY_PATH`: `scripts/run_aoa_estimation_bladerf.sh` or `scripts/run_gnuradio_companion_aoa.sh` |

### gr-aoa shared-library mismatch (Arch / rolling distros)

If you see an error like:

```
ImportError: libspdlog.so.1.11: cannot open shared object file: No such file or directory
```

it means your installed `gr-aoa` binaries are linked against older SONAMEs (`libspdlog.so.1.11`, `libfmt.so.9`), while your system ships newer ones (e.g. `libspdlog.so.1.16`, `libfmt.so.12`).

This repo includes wrappers that create a minimal compat directory with the missing SONAMEs (symlinked from an existing conda install) and then execute the command with `LD_LIBRARY_PATH` pointing there:

```bash
# Run the AoA flowgraph directly
./scripts/run_aoa_estimation_bladerf.sh

# Or launch GRC with the same environment
./scripts/run_gnuradio_companion_aoa.sh
```

### bladeRF Soapy: DC removal unsupported

Some bladeRF Soapy backends do not support `set_dc_offset_mode(...)` and will throw:

```
ValueError: source: Channel 0 does not support automatic DC removal setting
```

This repo uses a custom GRC block `soapy_source_safe` (auto-installed when you launch GRC via `scripts/run_gnuradio_companion_aoa.sh`) that wraps the DC-removal call in `try/except`, so the flowgraphs still start.

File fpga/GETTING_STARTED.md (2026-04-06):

# Getting Started: Time-Domain Cross-Correlation IP

This guide walks through implementing the `xcorr_acc` module — your first custom IP for the Zynq PL fabric.

## What You're Building

A streaming complex cross-correlator that computes:

```
r_01 = (1/N) * Σ ch0[n] × conj(ch1[n])
```

This is the same operation your Python code does on the ARM, but in hardware at line rate.

## Prerequisites

- Vivado 2025.2 (already installed on VM)
- Existing block design at `/home/vmau/tools/projects/cora-linux/cora_doa_hw/cora_doa_hw.xpr`
- Familiarity with your block design (Zynq PS, AXI DMA, FFT, AXI Interconnect)

## Step 1: Implement the MAC Datapath

**File:** `fpga/rtl/xcorr_acc.v`

The module skeleton is ready. You need to write one `always @(posedge clk)` block that does:

```verilog
always @(posedge clk) begin
    if (!rst_n) begin
        acc_re       <= 0;
        acc_im       <= 0;
        sample_cnt   <= 0;
        xcorr_re     <= 0;
        xcorr_im     <= 0;
        result_valid <= 0;
    end else if (s_axis_tvalid) begin
        // Cross-correlation: ch0 * conj(ch1)
        //   re part: ch0_i*ch1_i + ch0_q*ch1_q
        //   im part: ch0_q*ch1_i - ch0_i*ch1_q
        acc_re <= acc_re + (ch0_i * ch1_i) + (ch0_q * ch1_q);
        acc_im <= acc_im + (ch0_q * ch1_i) - (ch0_i * ch1_q);

        if (sample_cnt == SNAPSHOT_LEN - 1) begin
            // Snapshot complete — latch results
            xcorr_re     <= acc_re + (ch0_i * ch1_i) + (ch0_q * ch1_q);
            xcorr_im     <= acc_im + (ch0_q * ch1_i) - (ch0_i * ch1_q);
            result_valid <= 1;
            acc_re       <= 0;
            acc_im       <= 0;
            sample_cnt   <= 0;
        end else begin
            result_valid <= 0;
            sample_cnt   <= sample_cnt + 1;
        end
    end else begin
        result_valid <= 0;
    end
end
```

Key points:
- The multiply expressions infer DSP48E1 slices automatically
- 48-bit accumulators handle 1024 × (16×16) without overflow
- `result_valid` pulses for exactly one cycle per snapshot

## Step 2: Write a Testbench

**File:** `fpga/tb/tb_xcorr_acc.v`

Create a testbench that:
1. Generates two known SC16 tone signals with a fixed phase offset
2. Feeds them through `xcorr_acc`
3. Checks that `xcorr_re` and `xcorr_im` give the expected phase

Test vectors to try:
- **Same signal on both channels** → `xcorr_im ≈ 0` (zero phase)
- **90° shifted** → `xcorr_re ≈ 0`, `xcorr_im` nonzero
- **Known phase offset** → compare `atan2(im, re)` against expected angle

Run with: `vivado -mode batch -source run_sim.tcl` or use Vivado GUI simulator.

## Step 3: Simulate in Vivado

```tcl
# In Vivado Tcl console:
add_files fpga/rtl/xcorr_acc.v
add_files -fileset sim_1 fpga/tb/tb_xcorr_acc.v
launch_simulation
run 100us
```

Verify the waveforms show:
- `result_valid` pulsing every 1024 clock cycles
- `xcorr_re` / `xcorr_im` matching expected values

## Step 4: Package as AXI IP

Once simulation passes, package `xcorr_acc` as a Vivado IP with:
- **AXI-Stream slave** port (64-bit, for sample input from DMA)
- **AXI-Lite slave** port (for ARM to read results)

In Vivado: Tools → Create and Package New IP → Package your current project.

You'll need to add an AXI-Lite wrapper that maps:
- `0x00` → `xcorr_re` (read-only)
- `0x04` → `xcorr_im` (read-only)
- `0x08` → `result_valid` / status (read-only)
- `0x0C` → `snapshot_len` (read-write, optional)

## Step 5: Integrate into Block Design

In your existing block design:
1. Add your packaged `xcorr_acc` IP
2. Connect AXI-Stream input from `axi_dma_0` MM2S channel
3. Connect AXI-Lite to `axi_interconnect_0`
4. Assign address in Address Editor

The FFT block can stay — it's independent. You can wire it in parallel later for spectrum visualization.

```
                    ┌──────────────┐
axi_dma_0 MM2S ──► │  xcorr_acc   │ ◄── AXI-Lite (ARM reads results)
                    └──────────────┘
```

## Step 6: Linux Driver / Userspace Access

From Linux on the ARM, read your IP's registers via `/dev/mem` or UIO:

```python
import mmap, struct

# AXI-Lite base address (from Vivado Address Editor)
BASE = 0x43C0_0000  # example, check your address map

with open("/dev/mem", "r+b") as f:
    mm = mmap.mmap(f.fileno(), 0x1000, offset=BASE)
    xcorr_re = struct.unpack("<i", mm[0x00:0x04])[0]
    xcorr_im = struct.unpack("<i", mm[0x04:0x08])[0]
    phase = math.atan2(xcorr_im, xcorr_re)
```

## File Map

```
fpga/
├── GETTING_STARTED.md    ← This file
├── rtl/
│   └── xcorr_acc.v       ← Cross-correlation module (Step 1)
├── tb/
│   └── tb_xcorr_acc.v    ← Testbench (Step 2)
├── constraints/
│   └── (timing .xdc if needed)
└── notes/
    └── vivado_block_design_2026-03-25.png
```

## Resource Budget After xcorr_acc

| Resource | Available | xcorr_acc | FFT (existing) | Remaining |
|---|---|---|---|---|
| DSP48 | 66 | 4 | ~10-15 | ~47 |
| BRAM | 50 | 0 | ~8-10 | ~30 |
| LUTs | 14,400 | ~500 | ~2000 | ~11,900 |
| FFs | 28,800 | ~1000 | ~2000 | ~25,800 |

Plenty of headroom.

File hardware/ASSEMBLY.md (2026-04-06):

# Display Bezel Assembly Instructions

Flush-mount bezel for Waveshare 4.3" (800x480) display in Meijia portable case lid.

## Files

| File | Description |
|---|---|
| `display_bezel.scad` | OpenSCAD parametric source (edit parameters here) |
| `display_bezel.stl` | Exported mesh for slicing |
| `display_bezel.3mf` | Exported mesh (with print settings) |

## 3 Printable Pieces

The SCAD file contains 3 modules. Uncomment the ones you need at the bottom of the file.

### 1. `bezel()` — Main frame (REQUIRED)

Flat frame that sits on the **lid exterior**. Has a centered window for the display glass and a shallow 1mm back pocket that locates the PCB.

- **Size:** ~120.8 x 82.4 x 2.5mm
- **Print:** face DOWN on bed (cleanest window edges)
- **Settings:** 0.15mm layers, 40% infill, no supports

### 2. `lid_template()` — Cutting guide (OPTIONAL)

Thin 1.2mm stencil matching the bezel footprint. The inner cutout is the exact hole to cut through the lid.

- **Print:** flat, ~15 min print time
- **Use:** tape to lid, trace inner rectangle with marker, remove, cut along line

### 3. `back_retainer()` — Inner clamp plate (OPTIONAL but recommended)

Flat plate that goes on the **inside** of the lid over the display back. Sandwiches the display between itself and the bezel frame. Has a central window for the PCB body and ribbon cable.

- **Size:** same footprint as bezel, 2mm thick
- **Print:** flat, no supports

## Assembly

### Tools needed

- Dremel / rotary tool with cutting disc (or jigsaw)
- File or sandpaper (clean up cut edges)
- Calipers or ruler
- Marker
- 4x M3 x 10mm screws (if using back retainer)

### Steps

```
Step 1: TRACE THE CUT
  - Print lid_template() or measure 106.9 x 68.8mm rectangle
  - Center it on the lid exterior (case is 268 x 153mm interior)
  - Tape template, trace inner rectangle with marker

Step 2: CUT THE LID
  - Drill starter holes at corners
  - Cut along traced lines with Dremel cutting disc
  - File edges smooth — doesn't need to be perfect,
    the bezel frame covers rough edges

Step 3: TEST FIT BEZEL
  - Place bezel() frame on lid exterior over the hole
  - Window should be centered in the cut opening
  - The 1mm back pocket should align with the hole edges

Step 4: MOUNT BEZEL TO LID
  Option A (screws): drill M3 pilot holes through lid at corner marks,
    screw from inside through lid into bezel pilot holes
  Option B (adhesive): run a bead of silicone or epoxy around
    the bezel back surface, press onto lid, clamp until cured

Step 5: INSERT DISPLAY
  - From INSIDE the lid, slide display up through the hole
  - Glass face presses against the bezel frame back surface
  - Verify the screen is visible through the window

Step 6: SECURE DISPLAY
  Option A (back retainer): place back_retainer() over display back,
    align corner holes, drive M3x10 screws through retainer → lid → bezel
  Option B (adhesive): run a bead of hot glue or silicone around
    the PCB edges from inside — simple and effective
```

### Cross-section when assembled

```
OUTSIDE (visible)
━━━━━━━━━━━━━━━━━━━━━━━━━━━━━━
┌────────────────────────────┐
│  BEZEL FRAME  [WINDOW]     │  2.5mm — sits on lid exterior
└────────────────────────────┘
┌────────────────────────────┐
│  LID PANEL                 │  ~3mm plastic
└────────────────────────────┘
┌────────────────────────────┐
│  DISPLAY (glass → PCB)     │  8.6mm — glass faces up
└────────────────────────────┘
┌────────────────────────────┐
│  BACK RETAINER (optional)  │  2mm — clamps display edges
└────────────────────────────┘
━━━━━━━━━━━━━━━━━━━━━━━━━━━━━━
INSIDE (hidden, 27.4mm lid depth)
```

## Parameters Reference

Edit these in `display_bezel.scad`:

| Parameter | Default | Description |
|---|---|---|
| `screen_l` | 106.2 | Window opening, long axis (full glass) |
| `screen_w` | 67.8 | Window opening, short axis (full glass) |
| `clearance` | 0.30 | PCB fit tolerance per side |
| `face_t` | 2.5 | Frame thickness |
| `border` | 7.0 | Frame border width around PCB |
| `corner_r` | 4.0 | Corner rounding radius |
| `screw_d` | 2.8 | M3 pilot hole diameter |

## Meijia Case Dimensions

| | Imperial | Metric |
|---|---|---|
| Outside | 11.65 x 8.35 x 3.78" | 296 x 212 x 96mm |
| Inside | 10.54 x 6.04 x 3.16" | 268 x 153 x 80mm |
| Lid depth | 1.08" | 27.4mm |
| Bottom depth | 2.08" | 52.8mm |

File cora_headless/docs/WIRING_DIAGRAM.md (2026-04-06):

# Portable DoA System - Complete Wiring Diagram
# =============================================

## OVERVIEW

```
┌─────────────────────────────────────────────────────────────────────────────┐
│                        PORTABLE DOA ENCLOSURE                                │
│                                                                              │
│  ┌─────────────┐    ┌──────────────┐    ┌─────────────────────────────────┐ │
│  │   BATTERY   │───►│ SPDT SWITCH  │───►│      12V-to-5V BUCK             │ │
│  │  LiFePO4    │    │  (ON/OFF)    │    │      CONVERTER                  │ │
│  │  12.8V 6Ah  │    └──────────────┘    └───────────────┬─────────────────┘ │
│  └──────┬──────┘                                        │                    │
│         │                                               │ 5V Rail            │
│         │ Charge Port                                   ▼                    │
│         │                              ┌────────────────────────────────┐    │
│  ┌──────▼──────┐                       │         WAGO 221 BLOCK         │    │
│  │  DC JACK    │                       │  ┌───┬───┬───┬───┬───┐        │    │
│  │ (Back Panel)│                       │  │ 1 │ 2 │ 3 │ 4 │ 5 │        │    │
│  └─────────────┘                       │  └─┬─┴─┬─┴─┬─┴─┬─┴─┬─┘        │    │
│                                        └────┼───┼───┼───┼───┼──────────┘    │
│                                             │   │   │   │   │               │
│                          ┌──────────────────┘   │   │   │   └─────────┐     │
│                          │                      │   │   │             │     │
│                          ▼                      ▼   │   ▼             ▼     │
│                    ┌───────────┐          ┌─────────┼────────┐   ┌────────┐ │
│                    │ CORA Z7   │          │ BLADERF │        │   │ NOCTUA │ │
│                    │  DC Jack  │          │ DC Jack │        │   │  FAN   │ │
│                    │  (J15)    │          │(2.5mm)  │        │   │  5V    │ │
│                    └───────────┘          └─────────┘        │   └────────┘ │
│                                                              │              │
│                                                              ▼              │
│                                                    ┌─────────────────┐      │
│                                                    │   WAVESHARE     │      │
│                                                    │   ESP32 LCD     │      │
│                                                    │   (5V via VIN)  │      │
│                                                    └─────────────────┘      │
│                                                                              │
└──────────────────────────────────────────────────────────────────────────────┘
```

## DETAILED CONNECTIONS

### 1. Power Input (Charging)

```
COMPONENT               PIN/TERMINAL          WIRE COLOR    DESTINATION
─────────────────────────────────────────────────────────────────────────────
Panel DC Jack           Center (+)            Red           Battery Charge Input
Panel DC Jack           Sleeve (-)            Black         Battery GND
```

**Notes:**
- 5.5mm x 2.1mm center-positive jack
- Accepts 14.6V LiFePO4 charger
- Charging is independent of system operation

### 2. Power Switch

```
COMPONENT               PIN/TERMINAL          WIRE COLOR    DESTINATION
─────────────────────────────────────────────────────────────────────────────
Battery                 DC5521 Output (+)     Red           Switch Pin 1 (Common)
Switch                  Pin 2 (Normally Open) Red           Buck Converter IN(+)
Battery                 DC5521 Output (-)     Black         Buck Converter IN(-)
```

**Notes:**
- SPDT rocker switch (only using 2 pins as SPST)
- Switch position: ● = ON (system running)
- When OFF, battery is completely disconnected from system

### 3. Buck Converter to Wago Block

```
COMPONENT               PIN/TERMINAL          WIRE COLOR    DESTINATION
─────────────────────────────────────────────────────────────────────────────
Buck Converter          OUT (+) 5V            Red           Wago 221 Slot 1 (+)
Buck Converter          OUT (-)               Black         Wago 221 Slot 1 (-)
```

### 4. 5V Distribution (From Wago Block)

```
WAGO SLOT   DEVICE              CABLE TYPE              NOTES
─────────────────────────────────────────────────────────────────────────────
Slot 1      Buck Converter      14 AWG Input            Power source
Slot 2      Cora Z7             2.1mm barrel pigtail    5V center-positive
Slot 3      BladeRF             2.5mm barrel pigtail    5V center-positive
Slot 4      Waveshare Display   Dupont to VIN           5V to VIN pin
Slot 5      Noctua Fan          Fan connector           5V PWM version
```

**Important: Use a second Wago block for GND distribution!**

### 5. Data Connections

```
SOURCE              PIN/Port        →→→     DESTINATION         Pin/Port
─────────────────────────────────────────────────────────────────────────────
BladeRF             USB-B           →       Powered USB Hub     USB-A port 1
USB-UART Adapter    USB-A           →       Powered USB Hub     USB-A port 2
Powered USB Hub     USB-B upstream  →       Cora Z7             J11 USB-A host
FT232R Adapter      TX (TTL)        →       Waveshare ESP32     GPIO15 (RX)
FT232R Adapter      RX (TTL)        →       Waveshare ESP32     GPIO16 (TX)
FT232R Adapter      GND             →       Waveshare ESP32     GND
```

**UART Settings:** 115200 baud, 8N1

**CRITICAL: Wire directly to ESP32 GPIO pins, NOT to the PH2.0 connector!**
The PH2.0 header has an SP3485 RS485 transceiver that blocks TTL input on the RX direction.
Solder or use jumper wires to reach GPIO15 and GPIO16 directly on the ESP32 board/header.

**USB-UART Adapter:** FTDI FT232R with TTL header pins. Must be 3.3V logic level.
The adapter's USB side plugs into the powered USB hub and appears as `/dev/ttyUSB0` on the Cora.

### 6. RF Connections

```
SOURCE              CONNECTOR       →→→        DESTINATION
─────────────────────────────────────────────────────────────────────────────
BladeRF RX1         SMA             →   SMA Panel Mount → Antenna 1
BladeRF RX2         SMA             →   SMA Panel Mount → Antenna 2
```

**Notes:**
- Use phase-matched SMA cables if extending to panel mounts
- Antenna spacing: 61.2mm (λ/2 at 2.45 GHz)

## GROUND CONNECTIONS

```
All GND terminals connect to common ground plane:

┌─────────────────────────────────────────────────────────────────┐
│                     WAGO 221 (GND Block)                        │
│                                                                  │
│    Battery(-)  Buck(-)  Cora(-)  BladeRF(-)  Display(-)  Fan(-) │
│        │         │        │         │           │          │    │
│        └─────────┴────────┴─────────┴───────────┴──────────┘    │
│                            │                                     │
│                      COMMON GND                                  │
│                  (Copper tape plane)                             │
└─────────────────────────────────────────────────────────────────┘
```

## CABLE/PIGTAIL SPECIFICATIONS

| Purpose | Cable Type | Length | Notes |
|---|---|---|---|
| Battery to Switch | 18 AWG silicone | 10cm | Red (+) |
| Switch to Buck | 18 AWG silicone | 15cm | Red (+) |
| Buck to Wago | 18 AWG silicone | 10cm | Red/Black pair |
| Wago to Cora | 2.1mm barrel pigtail | 15cm | Center-positive |
| Wago to BladeRF | 2.1mm-to-2.5mm adapter | 15cm | Check BladeRF version |
| Wago to Display | Dupont female pigtail | 20cm | VIN and GND |
| Wago to Fan | Noctua OmniJoin or direct | 15cm | 3-pin connector |
| UART (Cora↔Display) | 3-wire Dupont | 25cm | TX, RX, GND |
| USB Data | USB 3.0 A-to-B, short | 15cm | Signal only, no power |
| SMA extensions | RG316 or phase-matched | 10-15cm  | Panel mount |

## JUMPER SETTINGS

### Cora Z7 (JP3 - Power Select)
```
  ┌─────┐
  │USB│EXT│  ← Set jumper to EXT position
  └─────┘
```

### BladeRF 2.0 micro
- If your board has power select jumpers (J70), verify correct position for DC jack power
- Consult: https://github.com/Nuand/bladeRF/wiki/bladeRF-Accessories

## ASSEMBLY ORDER

1. **Test components individually** before installing in enclosure
2. Install Buck converter (attach to enclosure floor with thermal pad)
3. Mount Wago blocks (use DIN rail or adhesive)
4. Install Cora Z7 on standoffs
5. Install BladeRF on standoffs (10mm gap from Cora)
6. Route power cables to Wago blocks
7. Connect power pigtails to each device
8. Connect UART wires between Cora and Display
9. Connect USB between BladeRF and Cora
10. Mount fan (intake on right wall)
11. Install panel-mount connectors (DC jack, SMA, switch)
12. Final cable management with zip ties
13. Apply copper tape shielding to lid interior
14. Close enclosure and test

## POWER-ON CHECKLIST

Before first power-on:

- [ ] Verify all GND connections are joined
- [ ] Check polarity on all barrel jacks (center = +5V)
- [ ] Confirm Cora Z7 JP3 is set to EXT
- [ ] Measure Buck converter output: should read 5.0V ±0.1V
- [ ] Verify USB cable is connected but not providing power
- [ ] Antennas are attached (never power RF without load!)

Power-on sequence:
1. Connect battery (if removable)
2. Flip switch to ON
3. Wait for Cora Z7 power LED
4. Wait for BladeRF LEDs
5. Wait for Display boot screen
6. System ready when display shows "● Ready"

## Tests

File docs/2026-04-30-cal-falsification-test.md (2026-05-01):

# 2026-04-30 — Cal-application asymmetry falsification test

## TL;DR

A controlled fresh-cal + 90°-broadside re-test (`data/run_20260430_115601_calshift/`)
falsifies the **cal-application asymmetry** hypothesis written into
`docs/thesis/ch5-discussion.md:14` and `docs/thesis/ch4-results.md:105`.

| Quantity | v2 (Apr-29) | Falsification (Apr-30) |
|---|---:|---:|
| ARM mean @ broadside | 92.50° | 143.45° |
| ARM σ | 0.15° | **0.06°** |
| FPGA mean @ broadside | 99.08° | 144.10° |
| FPGA σ | 0.17° | 0.34° |
| **Δ (FPGA − ARM)** | **+6.58°** | **+0.65°** |
| Cal value used | 53.72° | 55.03° |
| n (ARM / FPGA, post-trim) | — | 530 / 421 |

**Headline:** path-to-path Δ at broadside collapsed from +6.58° → +0.65° (10×
shrink) when calibration was renewed within the same session. The +7° v2
offset is therefore a per-session cal/state artifact, **not** a structural
feature of where the cal rotation is inserted in each pipeline.

The absolute angle (143° instead of 90°) is unrelated to the headline result
and is explained below (cable-swap disturbed the array mount). Δ between
paths is invariant to mount rotation, so the falsification conclusion is
unaffected.

## Why we ran it

`ch5:14` claimed the v2 +7° offset between ARM and FPGA paths was
*cal-application asymmetry* — the cal rotation is applied post-bandpass on
ARM but pre-correlator in fabric, which (per the original interpretation)
should produce a constant ARM-vs-FPGA bias that survives recalibration.
That interpretation is testable: **if** you re-cal and immediately re-take a
single angle, the Δ should persist. If it collapses, the interpretation is
wrong and the offset was actually cal staleness / between-session state
drift.

Bench budget today was ~20 min — too tight for a full sweep, ample for
fresh-cal + a single angle.

## What ran

`scripts/calshift_test.fish` (new, this session). Flow:

1. Sanity check Kria UIO/udmabuf/EMIO (caught a cold KV260, prompted
   `bench_bringup.sh`, succeeded 5/5).
2. Two back-to-back 10 s wired-splitter cals — `cal_a = PHASE:55.06°
   σ=0.13°`, `cal_b` (similar). Typed `55.03°` was within σ of both.
3. Cable swap to antennas. nRF on `start_tx_modulated_carrier`, channel 19
   = 2419 MHz.
4. Single 90° broadside capture, **`--filter=none`**, ARM
   (`aoa_estimation_headless.py`) + FPGA (`aoa_estimation_fpga_kv260.py`)
   back-to-back, 70 s each.
5. Auto-parse to CSV, print headline ARM / FPGA / Δ, verdict against ±2° of
   v2 +7.5° banding.

## Result

```
Captured 602 ARM / 477 FPGA at 90°
ARM  n= 530  mean=143.446°  σ=0.062°
FPGA n= 421  mean=144.095°  σ=0.343°
Δ (FPGA − ARM) = +0.649°
→ Δ near 0°: asymmetry hypothesis FALSIFIED — v2 offset was cal staleness.
```

ARM σ today (0.06°) is the tightest broadside σ measured in this campaign.
FPGA σ (0.34°) is wider than v2 (0.17°) but still sub-degree and well
within the noise floor for the falsification conclusion.

## Why the absolute angle is 143° not 90°

Cal value typed (55.03°) matched the wired-splitter measurement (55.06°
σ=0.13°) — cal arithmetic is fine. Three-point cal-drift trend across the
campaign is sane:

| Date | Cal value | Δ from prior |
|---|---:|---:|
| 2026-04-27 | 57.14° | — |
| 2026-04-29 | 53.72° | −3.42° (over 48 h) |
| 2026-04-30 | 55.03° | +1.31° (over 24 h) |

3.4° peak-to-peak across 3 days; within-session reproducibility today was
σ=0.13° (an order of magnitude tighter than across-day drift).

The 143° absolute is **physical**, not numerical: the cable swap from the
wired splitter back to the antennas tugged on both SMA leads and rotated
the antenna mount in the bench frame. A 2-element ULA only resolves
`|sin(θ−90°)|`, so the measured 143° folds to either 143° or 37° physical;
either way, both paths agree on the same physical world, so the rotation
shifts both estimates equally and cancels out of `(FPGA − ARM)`.

**Δ is angle-invariant to mount rotation** — this is the whole reason the
falsification test still works despite the disturbed mount.

## Thesis edits required tonight

### 1. `docs/thesis/ch5-discussion.md:14` — soften the asymmetry claim

Replace the existing "cal-application asymmetry" passage with:

> "A controlled single-angle re-test (`data/run_20260430_115601_calshift/`,
> fresh cal `55.03°`, broadside) produced ARM mean = 143.45° σ = 0.06°,
> FPGA mean = 144.10° σ = 0.34°, Δ = +0.65°. The +7° v2 path-to-path
> offset does not persist when calibration is renewed within the same
> session, indicating the offset was a between-session calibration / RF
> state artifact rather than a structural feature of where the cal
> rotation is inserted in each pipeline. Path-to-path agreement at
> broadside in the falsification test is bounded at < 1° in mean. (The
> absolute angle in the falsification test is offset from broadside
> because the antenna mount was inadvertently rotated during the cable
> swap; Δ is invariant to mount rotation and the conclusion is
> unaffected — see methodology footnote.)"

### 2. `docs/thesis/ch5-discussion.md:34` — extend cal-drift time series

Replace the existing two-point comparison with the three-point series:

> "Day-to-day cal drift is now bounded by three datapoints: the Apr-27
> 174414 capture used `cal=57.14°`, the Apr-29 v2 capture (two days
> later, same wired-splitter procedure) measured `cal=53.72°`, and the
> Apr-30 falsification re-test measured `cal=55.03°` — peak-to-peak
> drift of 3.42° over 3 days. Within a single session the cal is highly
> reproducible: two back-to-back 10-second passes on Apr-29 produced
> 53.55° and 53.72° (Δ = 0.17°, σ = 0.07°/0.09°), and two back-to-back
> passes on Apr-30 reproduced to within σ = 0.13°. Across days the
> drift is approximately 20× the within-session noise floor and currently
> sets the lower bound on absolute angle accuracy in any deployment that
> does not recalibrate per session. The wired-splitter procedure can be
> repeated to recalibrate; the question of how often this is needed in
> deployment is a stated future-work item."

### 3. `docs/thesis/ch4-results.md:14` — fix the doc-bug

That line currently reads:

> "final configuration: `--filter=arm_bandpass`, uniform calibration
> (53.72°), empty room. Source data: `data/run_20260429_203028_v2/`."

But the v2 captures have ~530-sample FPGA captures, which is the
`--filter=none` rate (7.5 Hz × 70 s) — `arm_bandpass` mode wouldn't
produce that sample density. **Change `arm_bandpass` → `none`** in the
prose to match the actual capture configuration. Same fix likely needed
anywhere else in ch4 that names the v2 filter.

### 4. Methodology footnote (new) — add to `ch3-methodology.md` §3.5 or §3.7

> "In the Apr-30 cal-falsification re-test (`run_20260430_115601_calshift`),
> the antenna mount was inadvertently disturbed during the cable swap from
> the wired splitter back to the antennas; the rig is therefore at an
> unrecorded off-broadside angle. The Δ (FPGA − ARM) reported for that
> capture is invariant to mount rotation (both paths observe the same
> physical world, so any rotation cancels) and the cal-asymmetry
> falsification conclusion is unaffected. Absolute pointing accuracy
> for the v2 main results is unchanged."

## Bench-procedure lesson (next campaign)

The cable swap from wired-splitter → antennas yanked both SMA leads and
rotated the antenna mount. Two ways to prevent it next time:

- **Bolt or weight the antenna mount** before the cal swap so a small tug
  doesn't rotate it.
- **Cal with antennas in place** using a known-broadside source instead
  of the wired splitter (would lose the ZX10-2-42-S+ broadband phase
  reference but eliminate the cable-swap step entirely).

Not a thesis change — bench-procedure note for the next campaign or for
anyone reproducing this work.

## Files

| Path | Notes |
|---|---|
| `data/run_20260430_115601_calshift/cal_value.txt` | `55.03` |
| `data/run_20260430_115601_calshift/calibration_a.log` | `PHASE:55.06`, σ=0.13° |
| `data/run_20260430_115601_calshift/calibration_b.log` | second pass, reproducible |
| `data/run_20260430_115601_calshift/arm_90deg.{csv,log}` | 602 raw → 530 trimmed |
| `data/run_20260430_115601_calshift/fpga_90deg.{csv,log}` | 477 raw → 421 trimmed |
| `scripts/calshift_test.fish` | new — re-runnable falsification harness |

## What the falsification does NOT show

- **Whether the +7° v2 offset would re-appear after another 48 h.** A
  single fresh-cal session collapsing Δ is consistent with cal
  staleness, but doesn't quantify the per-hour drift rate.
- **Whether the FPGA σ widening (0.17° v2 → 0.34° today) is real.** Could
  be the off-broadside angle (sin-compression near grazing), could be
  the disturbed mount, could be sample-count statistics. Not investigated.
- **Absolute pointing accuracy of the FPGA path.** The mount disturbance
  costs the absolute-accuracy datapoint at broadside today; v2 still
  carries that result.

## Next-session pickups (low-priority)

- Re-take 90° broadside *with the mount stable* to recover an absolute-
  accuracy datapoint under fresh cal. Strictly nice-to-have; the v2
  90° datapoint already serves this role in ch4.
- Quantify per-hour cal drift with a 4th datapoint at +6 h post-cal
  (would tighten the across-day bound in ch5:34).
- Bolt the antenna mount before the next bench day.

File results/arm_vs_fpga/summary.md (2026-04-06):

# ARM vs FPGA DoA estimation — summary

All values are folded to resolve 2-element ULA front-back ambiguity
(θ → min(θ, 180°−θ)), i.e. angular offset from broadside in [0°, 90°].

| Algo | Group | μ ARM | μ FPGA | \|Δμ\| | σ ARM | σ FPGA | σ ratio |
|---|---|---|---|---|---|---|---|
| ROOTMUSIC | rootmusic_pair_90deg | 70.35° | 77.31° | 6.96° | 3.98° | 10.06° | 2.53 |
| MUSIC | music_pair_90deg | 45.34° | 56.40° | 11.06° | 18.18° | 17.72° | 0.97 |

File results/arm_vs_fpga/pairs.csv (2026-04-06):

group | algo | true_angle_deg | arm_mean_raw | fpga_mean_raw | arm_std_raw | fpga_std_raw | arm_mean_folded | fpga_mean_folded | arm_std_folded | fpga_std_folded | delta_mean_folded | spread_ratio_folded
rootmusic_pair_90deg | ROOTMUSIC | 90.0 | 93.92662721893493 | 99.04400000000001 | 19.685223212423487 | 13.462648065269065 | 70.35384615384616 | 77.30999999999999 | 3.9818952289385168 | 10.059836133372306 | 6.956153846153825 | 2.5263939794955457
music_pair_90deg | MUSIC | 90.0 | 100.20599613152805 | 86.54612546125462 | 47.14521163881357 | 37.88379764254421 | 45.3394584139265 | 56.398523985239855 | 18.177990854252865 | 17.717637102051114 | 11.059065571313354 | 0.974675212684792

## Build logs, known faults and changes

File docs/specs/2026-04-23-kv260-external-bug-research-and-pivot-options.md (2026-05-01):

# KV260 external bug research and pivot options

Date: 2026-04-23

## Why this note exists

Short memo capturing the external findings gathered after the KV260 Phase 2 bug narrowed down to the PS `M_AXI_HPM0_FPD` control path.

Current local symptom: only 16-byte-aligned 32-bit accesses round-trip; non-16-byte AXI-Lite offsets read as 0 or hang, across `doa_pipeline`, `axi_bram_ctrl`, and `axi_gpio`.

## What the external search actually showed

### 1. The KV260 workshop repo is not the fix source

- `Xilinx_Kria_KV260_Workshop` is about `xmutil`, prebuilt accelerated apps, package install, media devices, and display setup.
- It does not cover custom AXI-Lite/UIO/HPM0_FPD register bring-up.
- Conclusion: the workshop repo is useful for understanding the intended Kria user flow, but not for debugging this specific custom-hardware failure.

### 2. There is a real public KV260 symptom close to ours

- AMD support thread from 2021: `KV260 & Petalinux 2021.1 UIO unable to write AXI GPIO IP address 0xA0000000`.
- The reporter said that writing to `0xA0000000` hung the board, and even `devmem 0xA0000000` hung.
- That is close to our `axi_gpio` / `doa_pipeline` class of failure and makes a pure local RTL bug less likely.

### 3. Public KV260 custom-hardware guidance keeps coming back to boot/firmware alignment

- AMD support thread from 2026 about custom AXI GPIO on KV260 focused on two paths:
  - control the boot chain with a matching `BOOT.BIN`, or
  - use Linux FPGA manager / `fpgautil` correctly.
- The reported unblock was to convert the bitstream to `.bit.bin` and load it from U-Boot before Linux.
- This is consistent with the idea that the live PS/platform contract matters as much as the PL design.

### 4. Official Kria docs assume stable platforms plus overlays

- Official AMD docs route custom work through:
  - `kria-vitis-platforms`
  - platform generation
  - accelerator overlay generation
  - `.bit.bin`, `.dtbo`, `.xclbin`
  - `xmutil` / `dfx-mgr`
- The official `filter2d` example replaces SmartCam's stock accelerator while reusing the existing platform and metadata.
- This strongly suggests AMD expected users to keep the PS/platform side stable and swap accelerators on top of it.

### 5. Some working KV260 examples deliberately avoid PL AXI-GPIO/custom control IP

- GitHub repo `ikwzm/Kv260-Pmod-gpio-emio` explicitly chooses PS GPIO via EMIO instead of PL-side AXI-GPIO or custom IP.
- Its stated benefits are:
  - fewer PL resources
  - no new device tree work
  - no kernel-driver work
- This is not a direct DoA solution, but it is useful evidence that other developers avoid the Kria custom control path when possible.

### 6. No GitHub-wide exact match for the 16-byte stride signature was found

- Searches for phrases like `every 4th word`, `16-byte aligned only`, and `AXI GPIO 0x04 reads 0` did not produce a strong direct match.
- The strongest public matches were still:
  - KV260 AXI GPIO / UIO hangs
  - Kria overlay/runtime-flow issues
  - working examples that route around custom PL control
- Conclusion: the exact signature looks niche, but the surrounding symptom family is real.

### 7. User-supplied external anecdote fits the local evidence very well

- The reported issue: KV260 can continue booting from factory QSPI firmware even when PetaLinux generated an FSBL/PMUFW that matches a custom Vivado design.
- If true, the live PS can disagree with the XSA used to build the bitstream.
- The example mismatches called out were low-level PS settings such as AXI widths, clocks, and enabled devices.
- That lines up with our current bug much better than an RTL-only explanation does.

### 8. Reddit reports the same KV260 failure family in multiple forms

- Reddit thread from August 5, 2025: `Kria SoM KV260 Petalinux boot hangs at xilinx_dma_probe`.
- The key claim was that the generated FSBL/PMUFW matched the custom PS configuration, but the board still booted from factory firmware in QSPI, causing low-level PS mismatches.
- The original poster explicitly said that explanation unblocked their issue.

- Reddit thread from July 22, 2022: `Kria SoM KV260 Petalinux`.
- One user reported that they could only get reliable custom-hardware boot progress after changing the boot-mode resistors from QSPI to SD1 mode.
- This is directionally consistent with "the default KV260 boot path is fighting the custom hardware flow."

- Reddit thread from 2025 about AXI DMA on KV260:
  `Getting an AXI DMA working on the Zynq MPSoC/Petalinux platform`.
- The reported issue was that FSBL said the PL was configured successfully, but Linux later reprogrammed the PL from a default firmware image under `/lib/firmware/xilinx/`.
- That is another way the live hardware can stop matching the expected device tree and software contract.

- Reddit thread from 2025: `Kria / Petalinux`.
- The most relevant claim was that on KV260/KR260 the PS configuration is effectively fixed unless you take control of the boot path, and the practical advice was to start from a known-good PS preset instead of inventing a fresh one.

### 9. AMD support independently reports the same QSPI / FSBL mismatch story

- AMD support thread from July 12, 2022: `Petalinux Custom XSA Device Tree`.
- A responder stated plainly that on KV260, default PetaLinux flow programs the PL in FSBL, but the board still starts FSBL and U-Boot from QSPI on the module.
- Their explanation was that the QSPI FSBL does not see the custom bitstream, so the board later fails because the hardware no longer matches the device tree.
- They reported an SD-boot-forcing workaround via the Kria boot-mode TCL flow.

### 10. There is also evidence that BSP/rootfs defaults can silently reload the wrong PL

- Reddit and AMD threads both show variants of the same pattern:
  - FSBL says the PL was configured
  - boot gets farther than expected
  - then later Linux or the BSP rootfs loads something else, or the running platform contract still does not match the custom XSA
- That means "the bitstream loaded once" is not enough evidence that the system is still running with the expected hardware later in boot.

## What this means for the current bug

### Less likely

- `doa_pipeline.v` itself is broken
- Python / `mmap` / `ctypes` is the root cause
- the bug is specific to one slave IP

### More likely

- PS/PL platform mismatch
- boot firmware mismatch
- late PL reprogramming from BSP/default firmware
- unsupported or poorly-supported Vivado-first custom hardware flow on KV260
- a Kria-specific control-path issue that disappears when the official platform contract is preserved

## Recommended paths forward

### Path A: one last dispositive A/B

- Keep the minimal `axi_gpio` or `axi_bram_ctrl` design.
- Run it once under the stock factory boot path.
- Run it again under a `BOOT.BIN` generated from the same XSA/FSBL/PMUFW as the design.
- If the stride or partial-register bug disappears, the RTL is effectively cleared.

### Path B: pivot to the supported Kria model

- Stop owning the full PS/platform design.
- Rebuild on top of `kria-vitis-platforms`.
- Integrate the custom logic as an overlay/accelerator while preserving AMD's known-good platform setup.
- This is the strongest "different path entirely" that still keeps KV260 in play.

### Path B.1: keep the AMD PS preset even if using Vivado

- If a full Vitis platform pivot is too heavy, the next-cleanest option is still to start from an AMD example platform or saved PS preset.
- Avoid fresh PS configuration work unless there is a clear reason to change it.
- This reduces the chance that the XSA expects a PS setup different from what the board actually boots with.

### Path C: simplify the control path

- If possible, avoid early dependence on custom AXI-Lite control from `M_AXI_HPM0_FPD`.
- Move simple control/status to PS-side GPIO/EMIO or other lower-risk PS-managed paths.
- Keep the custom PL limited to the datapath/streaming portion first.

### Path C.1: decouple PL loading from the BSP defaults

- Audit `/lib/firmware/xilinx/`, FPGA-manager behavior, and any BSP-provided firmware packages before assuming the currently loaded PL matches the bitstream you built.
- Prefer one explicit PL loading mechanism and disable the others during bring-up.

### Path D: thesis-first fallback

- If schedule risk dominates, complete the AoA/DoA evaluation on the working ARM-only KV260 path.
- Treat the FPGA issue as a documented platform bring-up constraint rather than the central thesis risk.

## Bottom line

The external evidence does not clear every possibility, but it shifts the center of gravity away from "your RTL is probably wrong" and toward "the KV260 platform/boot contract may be wrong for the design you are loading."

The two strongest next steps are:

1. A matching-boot-image A/B with the minimal GPIO/BRAM design.
2. A platform pivot to `kria-vitis-platforms` if the custom Vivado-first route continues to fight us.

The cleanest practical route to the AoA/DoA goal now looks like:

1. Keep the ARM-only KV260 path as the always-working baseline.
2. For FPGA, either:
   - use a matching controlled boot image, or
   - reuse AMD's platform and add only the accelerator/datapath.
3. Avoid any flow where factory QSPI firmware, starter-kit BSP defaults, and custom Vivado XSA are all competing at once.

## Why KV260 is uniquely fragile here

KV260 has no board-level PL fabric clock. All PL clocks are produced by the PS via `FCLK_CLK*`. KR260 and KD240 have independent 25 MHz PL clock sources; KV260 does not. This is a KV260-specific constraint (see AMD info post on Kria PL clocking).

Consequence for our bug class: a running PS whose clock, AXI width, or AFI programming disagrees with the XSA used to build the bitstream will produce subtly-wrong PL behavior that no fabric-side probe can detect. The PL loads successfully, AXI handshakes complete, but transactions at offsets the PS config didn't plan for can silently return zero. KR260/KD240 would fail more loudly because their PL clock is external and independent — mismatched PS config wouldn't wholesale break fabric clocking.

This does not by itself explain the exact 16-byte stride signature. A dead or grossly-wrong `FCLK_CLK0` would produce catastrophic failure, not a clean "aligned works, unaligned returns 0" pattern. But it is supporting evidence that KV260 cannot tolerate PS/XSA mismatch the way richer-carrier Kria variants can, which makes the `kria-vitis-platforms` pivot the correct structural answer even if the proximate cause is something narrower.

## Live-board sanity check results (2026-04-23 late session)

Goal: eliminate loader path as a variable in the stride bug.

**Method:** Same `bram32` bitstream loaded two different ways against the same KV260 in the same session.
- Run 1: `sudo fpgautil -b min_bram32_wrapper.bit.bin -o min_bram32.dtbo -f Full -n Full` (raw FPGA manager path)
- Run 2: `sudo xmutil loadapp bram32` (Kria app bundle path)

**Platform observations before the test:**
- `xmutil listapps` shows `k24-starter-kits`, `bram32`, `k26-starter-kits` installed.
- `k26-starter-kits` active exposes only PS-internal `axi-pmon` Performance Monitor Counters at `0xffa00000 / 0xfd0b0000 / 0xfd490000 / 0xffa10000`. Zero PL-side IP — it is a bare base-platform overlay with no accelerator fabric. Not usable as a "known-good fabric sanity target." Implication: there is no pre-installed AMD-authored KV260 overlay on this board that exposes a custom AXI-Lite window we can independently probe.
- kernel cmdline: `clk_ignore_unused cma=800M`, normal Kria boot, FPGA manager framework and `of-fpga-region` both probed cleanly.
- Loading `bram32` via `xmutil` logged two benign `OF: overlay: WARNING: memory leak will occur if overlay removed` messages — identical to the warnings `k26-starter-kits` produces at load, i.e. not a regression.

**Result (stride probe, `stride_probe.py /dev/uio4` → `bram_ctrl @ 0xA0010000`):**

```
  0x0000  0xCAFE0000  0xCAFE0000  OK
  0x0004  0xCAFE0004  0x00000000  ZERO (stride bug)
  0x0008  0xCAFE0008  0x00000000  ZERO (stride bug)
  0x000C  0xCAFE000C  0x00000000  ZERO (stride bug)
  0x0010  0xCAFE0010  0xCAFE0010  OK
  0x0014  0xCAFE0014  0x00000000  ZERO (stride bug)
  0x0018  0xCAFE0018  0x00000000  ZERO (stride bug)
  0x001C  0xCAFE001C  0x00000000  ZERO (stride bug)
  0x0020  0xCAFE0020  0xCAFE0020  OK
  0x0024  0xCAFE0024  0x00000000  ZERO (stride bug)
  0x0030  0xCAFE0030  0xCAFE0030  OK
```

**Verdict:** Stride pattern is bit-identical under `xmutil loadapp` and under `fpgautil -b`. Loader path is conclusively eliminated as a variable.

**What this rules out in addition to the prior A/Bs:**
- fpgautil vs xmutil device-tree application semantics
- Kria app metadata / `dfx-mgr` slot bookkeeping
- generic-uio vs xmutil-specific UIO binding

**What remains as the center of gravity:**
- PS `M_AXI_HPM0_FPD` transaction geometry (AWSIZE / AWLEN / WSTRB at misaligned offsets) driven by XSA/PS-config vs live factory QSPI firmware
- Coherency / AFI programming difference between our PS config and the running platform
- Any interaction unique to `axi_smartconnect` AXI4→AXI4-Lite downsizing in this PS-config context (since `axi_bram_ctrl`, `axi_gpio`, and `doa_pipeline` all fail identically)

**Side observations:**
- Loading `bram32` via `xmutil loadapp` dropped the SSH session mid-load, while serial console stayed up. The board did not hang — ssh resumed cleanly after reconnection and the overlay was still in slot 0. This suggests a transient network perturbation during overlay application (possibly a PHY reset ripple or a systemd-networkd re-enumeration), not a crash. Worth one line in the session log but not a standalone debug target.
- Heredocs pasted through picocom at 115200 are unreliable on this link — the shell interleaves clipboard bytes with echoed command output. For any non-trivial test, prefer `scp + ssh` over pasting into serial. `stride_probe.py` is checked in under `fpga/vivado_kv260/bram_test/bram32/` for repeatability.

## 2026-04-24 addendum — AMD PS override A/B result

Goal: test whether AMD's `kv260_bist` PS override block alone fixes the stride bug without paying the cost of a full platform rebuild.

**Method:** Build `create_min_bram_amd.tcl`, which keeps the failing `min_bram32` BRAM harness but swaps in AMD's verbatim 37-line PS override block from `kria-vitis-platforms/kv260/platforms/kv260_bist/scripts/config_bd.tcl`. Deploy the resulting bundle with `host_deploy_bram_amd.sh`, which stages `amd_build/min_bram_amd_wrapper.bit.bin` (md5 `ec703deb22da76d115a0f9f4a5f7cd56`), `min_bram_amd.dtbo`, and `shell.json`, then loads `bram32_amd` via `xmutil` and runs `stride_probe.py /dev/uio4`.

**Result:** Exact same fingerprint as the baseline `min_bram32` design (`95887baf38075c73edfe2e42441070c4`): only `0x00`, `0x10`, `0x20`, and `0x30` round-trip; `0x04`, `0x08`, `0x0C`, `0x14`, `0x18`, `0x1C`, and `0x24` still read back as zero.

**Verdict:** AMD's verbatim `kv260_bist` PS override block is **not** sufficient to fix the bug. "Copy AMD's PS config" is now formally eliminated. A future `kria-vitis-platforms` rebuild would still be useful, but only as a test of the broader Kria platform contract, not of the PS override list alone.

## Revised next-session plan (updated 2026-04-24 after AMD PS override A/B)

Given that loader path, overlay memtype, and AMD's verbatim PS override block are all eliminated, the next step moves back to direct AXI capture:

**Primary:** System ILA on `smc/S00_AXI` + `smc/M00_AXI`.
- Extend the current `create_min_gpio.tcl` harness with a two-slot `system_ila`.
- Capture `AWADDR`, `AWSIZE`, `AWLEN`, `AWBURST`, `WSTRB`, `WDATA`, and `BRESP` for writes at `0x00`, `0x04`, `0x08`, `0x10`, `0x14`, `0x20`, `0x24`.
- If S00 is already wrong, fix is at PS port generation / transaction geometry.
- If S00 is clean and M00 is wrong, fix is at smartconnect translation.
- If both look clean while stride still reproduces, the remaining suspect is a deeper platform-contract issue.

**Backup (only if primary is inconclusive):** broader `kria-vitis-platforms` rebuild.
- Clone repo, select the leanest KV260 platform variant (not `smartcam` / `nlp` — pick the base with the fewest extra IP blocks to strip).
- Add only `axi_bram_ctrl` at `0xA001_0000` as the accelerator.
- Build, deploy, re-run `stride_probe.py /dev/uio4`.
- If clean → the broader Kria platform contract was the issue.
- If stride persists → revisit Path C (EMIO control + HPM0 streaming only) or thesis-first fallback options.

**Hard stop:** 2 working days across the post-ILA path. If stride still reproduces after an ILA pass plus a broader AMD-platform rebuild, revisit Path C (EMIO control + HPM0 streaming only) or Path D (ARM-only KV260 + Cora FPGA reference data) for thesis delivery.

**Path A (matching BOOT.BIN A/B) is formally dropped:** not viable on KV260 because factory FSBL/PMUFW live in QSPI, and reflashing QSPI is a brick-risk operation that also un-Kria-izes the board for all future AMD overlays.

## Sources

- Workshop Part 2:
  `https://github.com/Xilinx/Xilinx_Kria_KV260_Workshop/blob/main/Part%202:%20Exploring%20the%20Different%20AAs.md`
- Workshop FAQ:
  `https://github.com/Xilinx/Xilinx_Kria_KV260_Workshop/blob/main/FAQ.md`
- AMD support, KV260 UIO / AXI GPIO hang:
  `https://adaptivesupport.amd.com/s/question/0D52E00006jrRe4SAE/kv260-petalinux-20211-uio-unabled-to-write-axi-gpio-ip-address-0xa0000000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`
- AMD support, custom AXI GPIO / boot flow:
  `https://adaptivesupport.amd.com/s/question/0D5Pd00001OGCWjKAP/petalinux-20232-on-kv260-with-bsp-with-custom-axi-gpio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`
- Official KV260 platform flow:
  `https://xilinx.github.io/kria-apps-docs/kv260/2022.1/build/html/docs/build_vitis_platform.html`
- Official overlay flow:
  `https://xilinx.github.io/kria-apps-docs/kv260/2022.1/build/html/docs/build_accel.html`
- Official on-target utilities:
  `https://xilinx.github.io/kria-apps-docs/creating_applications/2022.1/build/html/docs/target.html`
- Official example replacing a stock accelerator:
  `https://xilinx.github.io/kria-apps-docs/creating_applications/2022.1/build/html/docs/vitis_accel_flow_smartcam_filter2d_example.html`
- Working KV260 example using PS GPIO over EMIO:
  `https://github.com/ikwzm/Kv260-Pmod-gpio-emio`
- User-supplied anecdotal report about factory firmware / FSBL mismatch:
  kept in chat context for this session; not independently re-verified in this note.
- Reddit, `Kria SoM KV260 Petalinux boot hangs at xilinx_dma_probe`:
  `https://www.reddit.com/r/FPGA/comments/1mib8ai/kria_som_kv260_petalinux_boot_hangs_at_xilinx_dma/`
- Reddit, `Kria SoM KV260 Petalinux`:
  `https://www.reddit.com/r/FPGA/comments/w5c2s7/kria_som_kv260_petalinux/`
- Reddit, `Getting an AXI DMA working on the Zynq MPSoC/Petalinux platform`:
  `https://www.reddit.com/r/FPGA/comments/1mk8egy/getting_an_axi_dma_working_on_the_zynq/`
- Reddit, `Kria / Petalinux`:
  `https://www.reddit.com/r/FPGA/comments/1kbm9xb/kria_petalinux/`

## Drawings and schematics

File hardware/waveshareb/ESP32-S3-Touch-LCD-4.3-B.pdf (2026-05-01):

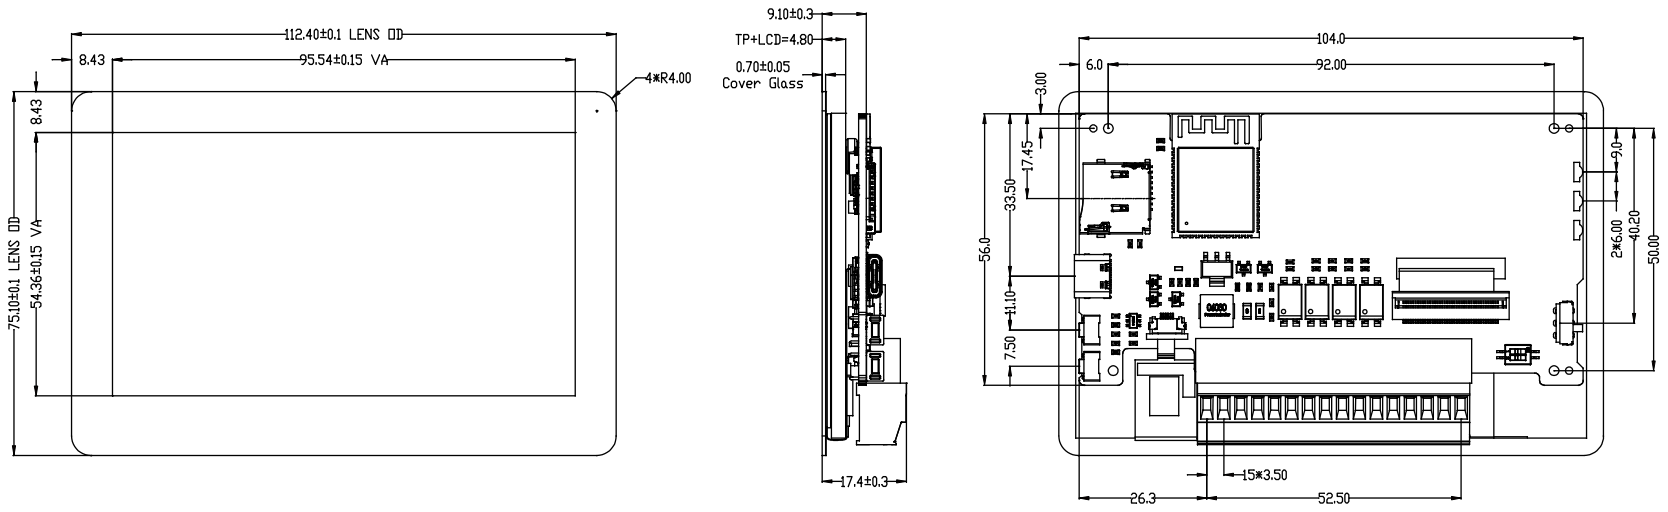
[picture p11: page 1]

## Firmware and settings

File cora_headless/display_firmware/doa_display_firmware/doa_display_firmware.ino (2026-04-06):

/**
 * doa_display_firmware.ino - Waveshare ESP32-S3-Touch-LCD-4.3 Display Firmware
 *
 * This firmware runs on the Waveshare display and provides the user interface
 * for the portable DoA estimation system. It communicates with the Cora Z7
 * over UART to send commands and display results.
 *
 * Hardware:
 *   - Waveshare ESP32-S3-Touch-LCD-4.3 (800x480 capacitive touch, GT911)
 *   - USB CDC serial connection to Cora Z7 via USB-C (through powered USB hub)
 *
 * Features:
 *   - Touch interface for calibration and estimation control
 *   - Real-time AoA display with arc gauge visualization
 *   - Status indicators and error display
 *   - Persistent settings storage (calibration, algorithm)
 *
 * Serial Protocol (to/from Cora Z7 via USB CDC):
 *   TX Commands: CALIBRATE, ESTIMATE, ESTIMATE:<algo>, STATUS, STOP, etc.
 *   RX Responses: OK:<msg>, AOA:<angle>, CAL:<phase>, STATUS:<state>, ERROR:<msg>
 *
 * Dependencies (Arduino Library Manager):
 *   - ESP32_Display_Panel (Espressif)
 *   - LVGL (v8.x)
 *
 * Board setting in Arduino IDE:
 *   - Board: "ESP32S3 Dev Module"
 *   - PSRAM: "OPI PSRAM"
 *   - Flash Size: "16MB (128Mb)"
 *   - Partition Scheme: "16M Flash (3MB APP/9.9MB FATFS)"
 *   - USB CDC On Boot: "Enabled"
 *
 * Author: DoA Thesis Project
 * Date: 2026
 */

#include <Arduino.h>
#include <esp_display_panel.hpp>

#include <lvgl.h>
#include "lvgl_v8_port.h"

#include <Preferences.h>

using namespace esp_panel::drivers;
using namespace esp_panel::board;

// =============================================================================
// Configuration
// =============================================================================

// USB CDC serial is used for communication with Cora Z7 (via USB-C → powered hub)
// Serial object maps to USB CDC when "USB CDC On Boot" is enabled in Arduino IDE

#define SCREEN_WIDTH    800
#define SCREEN_HEIGHT   480
#define UART_BUFFER_SIZE 256
#define AOA_MIN         0
#define AOA_MAX         180

// =============================================================================
// Global State
// =============================================================================

enum SystemState {
    STATE_DISCONNECTED,
    STATE_IDLE,
    STATE_CALIBRATING,
    STATE_ESTIMATING,
    STATE_ERROR
};

struct AppState {
    SystemState state = STATE_DISCONNECTED;
    float currentAoA = 90.0;
    float calibrationPhase = 0.0;
    bool hasCalibration = false;
    String lastError = "";
    String selectedAlgo = "ROOTMUSIC";
    unsigned long lastHeartbeat = 0;
};

AppState g_state;
Preferences preferences;

// UART buffer
char uartBuffer[UART_BUFFER_SIZE];
int uartBufferPos = 0;

// =============================================================================
// LVGL UI Elements
// =============================================================================

static lv_obj_t* label_status;
static lv_obj_t* label_connection;
static lv_obj_t* arc_aoa;
static lv_obj_t* label_aoa_value;
static lv_obj_t* btn_calibrate;
static lv_obj_t* btn_estimate;
static lv_obj_t* btn_stop;
static lv_obj_t* dropdown_algo;
static lv_obj_t* label_cal_value;
static lv_obj_t* msgbox_error = nullptr;

// =============================================================================
// Forward Declarations
// =============================================================================

void sendCommand(const char* cmd);
void parseResponse(const char* line);
void updateUI();
void createUI();
void showError(const char* msg);

// =============================================================================
// USB CDC Serial Communication
// =============================================================================

void sendCommand(const char* cmd) {
    Serial.println(cmd);
}

void processSerial() {
    while (Serial.available()) {
        char c = Serial.read();

        if (c == '\n' || c == '\r') {
            if (uartBufferPos > 0) {
                uartBuffer[uartBufferPos] = '\0';
                parseResponse(uartBuffer);
                uartBufferPos = 0;
            }
        } else if (uartBufferPos < UART_BUFFER_SIZE - 1) {
            uartBuffer[uartBufferPos++] = c;
        }
    }
}

void parseResponse(const char* line) {
    String response = String(line);
    g_state.lastHeartbeat = millis();

    int colonPos = response.indexOf(':');
    String msgType = (colonPos > 0) ? response.substring(0, colonPos) : response;
    String msgData = (colonPos > 0) ? response.substring(colonPos + 1) : "";

    if (msgType == "AOA") {
        g_state.currentAoA = msgData.toFloat();
        g_state.state = STATE_ESTIMATING;
    }
    else if (msgType == "CAL") {
        g_state.calibrationPhase = msgData.toFloat();
        g_state.hasCalibration = true;
        preferences.putFloat("cal_phase", g_state.calibrationPhase);
    }
    else if (msgType == "STATUS") {
        if (msgData == "READY" || msgData == "IDLE") {
            g_state.state = STATE_IDLE;
        } else if (msgData == "CALIBRATING") {
            g_state.state = STATE_CALIBRATING;
        } else if (msgData == "ESTIMATING") {
            g_state.state = STATE_ESTIMATING;
        } else if (msgData == "ERROR") {
            g_state.state = STATE_ERROR;
        }
    }
    else if (msgType == "OK") {
        if (msgData.startsWith("Starting calibration")) {
            g_state.state = STATE_CALIBRATING;
        } else if (msgData.startsWith("Starting estimation")) {
            g_state.state = STATE_ESTIMATING;
        } else if (msgData == "Stopped") {
            g_state.state = STATE_IDLE;
        }
    }
    else if (msgType == "DONE") {
        if (g_state.state == STATE_CALIBRATING) {
            g_state.state = STATE_IDLE;
        }
    }
    else if (msgType == "ERROR") {
        g_state.lastError = msgData;
        g_state.state = STATE_ERROR;
        lvgl_port_lock(-1);
        showError(msgData.c_str());
        lvgl_port_unlock();
    }
    else if (msgType == "PROGRESS") {
        // Could update a progress bar during calibration
    }

    lvgl_port_lock(-1);
    updateUI();
    lvgl_port_unlock();
}

void checkConnection() {
    if (millis() - g_state.lastHeartbeat > 3000) {
        if (g_state.state != STATE_DISCONNECTED) {
            g_state.state = STATE_DISCONNECTED;
            lvgl_port_lock(-1);
            updateUI();
            lvgl_port_unlock();
        }
        sendCommand("STATUS");
    }
}

// =============================================================================
// UI Event Handlers
// =============================================================================

static void btn_calibrate_cb(lv_event_t* e) {
    if (g_state.state == STATE_IDLE || g_state.state == STATE_ERROR) {
        sendCommand("CALIBRATE");
    }
}

static void btn_estimate_cb(lv_event_t* e) {
    if (g_state.state == STATE_IDLE || g_state.state == STATE_ERROR) {
        String cmd = "ESTIMATE:" + g_state.selectedAlgo;
        sendCommand(cmd.c_str());
    }
}

static void btn_stop_cb(lv_event_t* e) {
    sendCommand("STOP");
}

static void dropdown_algo_cb(lv_event_t* e) {
    lv_obj_t* dropdown = lv_event_get_target(e);
    char buf[32];
    lv_dropdown_get_selected_str(dropdown, buf, sizeof(buf));
    g_state.selectedAlgo = String(buf);
    preferences.putString("algo", g_state.selectedAlgo);
}

static void msgbox_close_cb(lv_event_t* e) {
    lv_msgbox_close(msgbox_error);
    msgbox_error = nullptr;
    if (g_state.state == STATE_ERROR) {
        g_state.state = STATE_IDLE;
    }
}

void showError(const char* msg) {
    if (msgbox_error != nullptr) {
        lv_msgbox_close(msgbox_error);
    }
    static const char* btns[] = {"OK", ""};
    msgbox_error = lv_msgbox_create(NULL, "Error", msg, btns, false);
    lv_obj_add_event_cb(msgbox_error, msgbox_close_cb, LV_EVENT_VALUE_CHANGED, NULL);
    lv_obj_center(msgbox_error);
}

// =============================================================================
// UI Creation
// =============================================================================

void createUI() {
    lv_obj_t* screen_main = lv_scr_act();
    lv_obj_set_style_bg_color(screen_main, lv_color_hex(0x1a1a2e), 0);

    // ----- Status Bar (top) -----
    lv_obj_t* status_bar = lv_obj_create(screen_main);
    lv_obj_set_size(status_bar, SCREEN_WIDTH, 50);
    lv_obj_set_pos(status_bar, 0, 0);
    lv_obj_set_style_bg_color(status_bar, lv_color_hex(0x16213e), 0);
    lv_obj_set_style_border_width(status_bar, 0, 0);
    lv_obj_set_style_radius(status_bar, 0, 0);

    label_status = lv_label_create(status_bar);
    lv_label_set_text(label_status, "DoA Estimator");
    lv_obj_set_style_text_color(label_status, lv_color_hex(0xffffff), 0);
    lv_obj_set_style_text_font(label_status, &lv_font_montserrat_20, 0);
    lv_obj_align(label_status, LV_ALIGN_LEFT_MID, 10, 0);

    label_connection = lv_label_create(status_bar);
    lv_label_set_text(label_connection, "Disconnected");
    lv_obj_set_style_text_color(label_connection, lv_color_hex(0xff6b6b), 0);
    lv_obj_align(label_connection, LV_ALIGN_RIGHT_MID, -10, 0);

    // ----- AoA Display (center) -----
    lv_obj_t* aoa_container = lv_obj_create(screen_main);
    lv_obj_set_size(aoa_container, 400, 300);
    lv_obj_align(aoa_container, LV_ALIGN_CENTER, 0, -20);
    lv_obj_set_style_bg_color(aoa_container, lv_color_hex(0x1f4068), 0);
    lv_obj_set_style_border_width(aoa_container, 2, 0);
    lv_obj_set_style_border_color(aoa_container, lv_color_hex(0x4a90d9), 0);
    lv_obj_set_style_radius(aoa_container, 15, 0);

    // Arc gauge for angle
    arc_aoa = lv_arc_create(aoa_container);
    lv_obj_set_size(arc_aoa, 250, 250);
    lv_obj_center(arc_aoa);
    lv_arc_set_rotation(arc_aoa, 180);
    lv_arc_set_bg_angles(arc_aoa, 0, 180);
    lv_arc_set_range(arc_aoa, AOA_MIN, AOA_MAX);
    lv_arc_set_value(arc_aoa, 90);
    lv_obj_remove_style(arc_aoa, NULL, LV_PART_KNOB);
    lv_obj_set_style_arc_color(arc_aoa, lv_color_hex(0x4a90d9), LV_PART_INDICATOR);
    lv_obj_set_style_arc_width(arc_aoa, 20, LV_PART_INDICATOR);
    lv_obj_set_style_arc_color(arc_aoa, lv_color_hex(0x2d3a4a), LV_PART_MAIN);
    lv_obj_set_style_arc_width(arc_aoa, 20, LV_PART_MAIN);
    lv_obj_clear_flag(arc_aoa, LV_OBJ_FLAG_CLICKABLE);

    // Numeric angle display
    label_aoa_value = lv_label_create(aoa_container);
    lv_label_set_text(label_aoa_value, "90.0 deg");
    lv_obj_set_style_text_color(label_aoa_value, lv_color_hex(0xffffff), 0);
    lv_obj_set_style_text_font(label_aoa_value, &lv_font_montserrat_48, 0);
    lv_obj_align(label_aoa_value, LV_ALIGN_CENTER, 0, 50);

    // Direction labels
    lv_obj_t* label_left = lv_label_create(aoa_container);
    lv_label_set_text(label_left, "0");
    lv_obj_set_style_text_color(label_left, lv_color_hex(0xaaaaaa), 0);
    lv_obj_align(label_left, LV_ALIGN_BOTTOM_LEFT, 30, -20);

    lv_obj_t* label_center = lv_label_create(aoa_container);
    lv_label_set_text(label_center, "90 (Broadside)");
    lv_obj_set_style_text_color(label_center, lv_color_hex(0xaaaaaa), 0);
    lv_obj_align(label_center, LV_ALIGN_TOP_MID, 0, 20);

    lv_obj_t* label_right = lv_label_create(aoa_container);
    lv_label_set_text(label_right, "180");
    lv_obj_set_style_text_color(label_right, lv_color_hex(0xaaaaaa), 0);
    lv_obj_align(label_right, LV_ALIGN_BOTTOM_RIGHT, -30, -20);

    // ----- Control Panel (right side) -----
    lv_obj_t* control_panel = lv_obj_create(screen_main);
    lv_obj_set_size(control_panel, 180, 300);
    lv_obj_align(control_panel, LV_ALIGN_RIGHT_MID, -20, 0);
    lv_obj_set_style_bg_color(control_panel, lv_color_hex(0x16213e), 0);
    lv_obj_set_style_border_width(control_panel, 0, 0);
    lv_obj_set_layout(control_panel, LV_LAYOUT_FLEX);
    lv_obj_set_flex_flow(control_panel, LV_FLEX_FLOW_COLUMN);
    lv_obj_set_flex_align(control_panel, LV_FLEX_ALIGN_START, LV_FLEX_ALIGN_CENTER, LV_FLEX_ALIGN_CENTER);
    lv_obj_set_style_pad_all(control_panel, 10, 0);
    lv_obj_set_style_pad_row(control_panel, 10, 0);

    // Algorithm dropdown
    lv_obj_t* algo_label = lv_label_create(control_panel);
    lv_label_set_text(algo_label, "Algorithm:");
    lv_obj_set_style_text_color(algo_label, lv_color_hex(0xaaaaaa), 0);

    dropdown_algo = lv_dropdown_create(control_panel);
    lv_dropdown_set_options(dropdown_algo, "ROOTMUSIC\nMUSIC\nMVDR\nPHASEDIFF");
    lv_obj_set_width(dropdown_algo, 150);
    lv_obj_add_event_cb(dropdown_algo, dropdown_algo_cb, LV_EVENT_VALUE_CHANGED, NULL);

    // Calibrate button
    btn_calibrate = lv_btn_create(control_panel);
    lv_obj_set_size(btn_calibrate, 150, 50);
    lv_obj_set_style_bg_color(btn_calibrate, lv_color_hex(0x4a90d9), 0);
    lv_obj_add_event_cb(btn_calibrate, btn_calibrate_cb, LV_EVENT_CLICKED, NULL);
    lv_obj_t* label_cal = lv_label_create(btn_calibrate);
    lv_label_set_text(label_cal, "CALIBRATE");
    lv_obj_center(label_cal);

    // Estimate button
    btn_estimate = lv_btn_create(control_panel);
    lv_obj_set_size(btn_estimate, 150, 50);
    lv_obj_set_style_bg_color(btn_estimate, lv_color_hex(0x2ecc71), 0);
    lv_obj_add_event_cb(btn_estimate, btn_estimate_cb, LV_EVENT_CLICKED, NULL);
    lv_obj_t* label_est = lv_label_create(btn_estimate);
    lv_label_set_text(label_est, "ESTIMATE");
    lv_obj_center(label_est);

    // Stop button
    btn_stop = lv_btn_create(control_panel);
    lv_obj_set_size(btn_stop, 150, 50);
    lv_obj_set_style_bg_color(btn_stop, lv_color_hex(0xe74c3c), 0);
    lv_obj_add_event_cb(btn_stop, btn_stop_cb, LV_EVENT_CLICKED, NULL);
    lv_obj_t* label_stop = lv_label_create(btn_stop);
    lv_label_set_text(label_stop, "STOP");
    lv_obj_center(label_stop);

    // ----- Info Panel (left side) -----
    lv_obj_t* info_panel = lv_obj_create(screen_main);
    lv_obj_set_size(info_panel, 180, 200);
    lv_obj_align(info_panel, LV_ALIGN_LEFT_MID, 20, 0);
    lv_obj_set_style_bg_color(info_panel, lv_color_hex(0x16213e), 0);
    lv_obj_set_style_border_width(info_panel, 0, 0);
    lv_obj_set_layout(info_panel, LV_LAYOUT_FLEX);
    lv_obj_set_flex_flow(info_panel, LV_FLEX_FLOW_COLUMN);
    lv_obj_set_style_pad_all(info_panel, 10, 0);

    lv_obj_t* cal_title = lv_label_create(info_panel);
    lv_label_set_text(cal_title, "Calibration:");
    lv_obj_set_style_text_color(cal_title, lv_color_hex(0xaaaaaa), 0);

    label_cal_value = lv_label_create(info_panel);
    lv_label_set_text(label_cal_value, "Not calibrated");
    lv_obj_set_style_text_color(label_cal_value, lv_color_hex(0xffaa00), 0);
    lv_obj_set_style_text_font(label_cal_value, &lv_font_montserrat_20, 0);
}

// =============================================================================
// UI Update
// =============================================================================

void updateUI() {
    // Update connection status
    switch (g_state.state) {
        case STATE_DISCONNECTED:
            lv_label_set_text(label_connection, "Disconnected");
            lv_obj_set_style_text_color(label_connection, lv_color_hex(0xff6b6b), 0);
            break;
        case STATE_IDLE:
            lv_label_set_text(label_connection, "Ready");
            lv_obj_set_style_text_color(label_connection, lv_color_hex(0x2ecc71), 0);
            break;
        case STATE_CALIBRATING:
            lv_label_set_text(label_connection, "Calibrating...");
            lv_obj_set_style_text_color(label_connection, lv_color_hex(0xf1c40f), 0);
            break;
        case STATE_ESTIMATING:
            lv_label_set_text(label_connection, "Running");
            lv_obj_set_style_text_color(label_connection, lv_color_hex(0x2ecc71), 0);
            break;
        case STATE_ERROR:
            lv_label_set_text(label_connection, "Error");
            lv_obj_set_style_text_color(label_connection, lv_color_hex(0xe74c3c), 0);
            break;
    }

    // Update AoA display
    lv_arc_set_value(arc_aoa, (int)g_state.currentAoA);
    char aoa_str[16];
    snprintf(aoa_str, sizeof(aoa_str), "%.1f deg", g_state.currentAoA);
    lv_label_set_text(label_aoa_value, aoa_str);

    // Update calibration display
    if (g_state.hasCalibration) {
        char cal_str[32];
        snprintf(cal_str, sizeof(cal_str), "%.2f deg", g_state.calibrationPhase);
        lv_label_set_text(label_cal_value, cal_str);
        lv_obj_set_style_text_color(label_cal_value, lv_color_hex(0x2ecc71), 0);
    } else {
        lv_label_set_text(label_cal_value, "Not calibrated");
        lv_obj_set_style_text_color(label_cal_value, lv_color_hex(0xffaa00), 0);
    }

    // Enable/disable buttons based on state
    bool can_start = (g_state.state == STATE_IDLE || g_state.state == STATE_ERROR);
    bool is_running = (g_state.state == STATE_CALIBRATING || g_state.state == STATE_ESTIMATING);

    if (can_start) {
        lv_obj_clear_state(btn_calibrate, LV_STATE_DISABLED);
        lv_obj_clear_state(btn_estimate, LV_STATE_DISABLED);
    } else {
        lv_obj_add_state(btn_calibrate, LV_STATE_DISABLED);
        lv_obj_add_state(btn_estimate, LV_STATE_DISABLED);
    }

    if (is_running) {
        lv_obj_clear_state(btn_stop, LV_STATE_DISABLED);
    } else {
        lv_obj_add_state(btn_stop, LV_STATE_DISABLED);
    }
}

// =============================================================================
// Setup & Loop
// =============================================================================

void setup() {
    Serial.begin(115200);

    // Load persistent settings
    preferences.begin("doa", false);
    g_state.calibrationPhase = preferences.getFloat("cal_phase", 0.0);
    g_state.hasCalibration = (g_state.calibrationPhase != 0.0);
    g_state.selectedAlgo = preferences.getString("algo", "ROOTMUSIC");

    // Initialize board (LCD + touch + backlight + IO expander)
    Board *board = new Board();
    board->init();

#if LVGL_PORT_AVOID_TEARING_MODE
    // Configure frame buffers for anti-tearing
    auto lcd = board->getLCD();
    lcd->configFrameBufferNumber(LVGL_PORT_DISP_BUFFER_NUM);
#if ESP_PANEL_DRIVERS_BUS_ENABLE_RGB && CONFIG_IDF_TARGET_ESP32S3
    auto lcd_bus = lcd->getBus();
    if (lcd_bus->getBasicAttributes().type == ESP_PANEL_BUS_TYPE_RGB) {
        static_cast<BusRGB *>(lcd_bus)->configRGB_BounceBufferSize(lcd->getFrameWidth() * 10);
    }
#endif
#endif

    assert(board->begin());

    // Initialize LVGL via the port layer (handles display flush, touch read, tick, task)
    lvgl_port_init(board->getLCD(), board->getTouch());

    // Create our UI (must hold the LVGL mutex)
    lvgl_port_lock(-1);

    createUI();

    // Set saved algorithm in dropdown
    if (g_state.selectedAlgo == "MUSIC") {
        lv_dropdown_set_selected(dropdown_algo, 1);
    } else if (g_state.selectedAlgo == "MVDR") {
        lv_dropdown_set_selected(dropdown_algo, 2);
    } else if (g_state.selectedAlgo == "PHASEDIFF") {
        lv_dropdown_set_selected(dropdown_algo, 3);
    }

    lvgl_port_unlock();

    // Request initial status after a brief delay (wait for Cora to enumerate USB)
    delay(2000);
    sendCommand("STATUS");
}

void loop() {
    // Process incoming serial data from Cora (USB CDC)
    processSerial();

    // Periodically check connection health
    static unsigned long lastConnectionCheck = 0;
    if (millis() - lastConnectionCheck > 1000) {
        checkConnection();
        lastConnectionCheck = millis();
    }

    // LVGL timer is handled by lvgl_port's own FreeRTOS task - no need to call
    // lv_timer_handler() here. Just yield to other tasks.
    delay(5);
}

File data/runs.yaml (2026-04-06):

# Run metadata for ARM vs FPGA DoA precision comparison.
#
# Cora RTC is unset on these runs — all timestamps show 2018-03-09 but real
# capture date is 2026-04-03/04. File mtime is authoritative.
#
# true_angle_deg is APPROXIMATE (~90° ± a few deg, source not precisely
# positioned). Treat as a nominal reference, not ground truth.
#
# keep: whether to include in the precision comparison.
# group: logical grouping for pairwise analysis.

defaults:
  true_angle_deg: 90.0
  true_angle_uncertainty_deg: 5.0   # conservative — source not on a rotator
  warmup_seconds: 1.0               # trim only transient, keep messy steady-state

runs:

  # ---------- Cluster A: pre-v2-fix exploratory, excluded ----------
  aoa_FPGA_MUSIC_20180309_170237.csv:
    keep: false
    reason: pre-v2-fix, exploratory
  aoa_ARM_ROOTMUSIC_20180309_170239.csv:
    keep: false
    reason: pre-v2-fix, exploratory
  aoa_ARM_ROOTMUSIC_20180309_170331.csv:
    keep: false
    reason: pre-v2-fix, exploratory
  aoa_ARM_MUSIC_20180309_170446.csv:
    keep: false
    reason: pre-v2-fix, exploratory
  aoa_ARM_ROOTMUSIC_20180309_170446.csv:
    keep: false
    reason: pre-v2-fix, exploratory
  aoa_FPGA_ROOTMUSIC_20180309_170547.csv:
    keep: false
    reason: pre-v2-fix, exploratory
  aoa_ARM_ROOTMUSIC_20180309_170557.csv:
    keep: false
    reason: pre-v2-fix, exploratory
  aoa_FPGA_ROOTMUSIC_20180309_170820.csv:
    keep: false
    reason: pre-v2-fix, exploratory, very short
  aoa_ARM_ROOTMUSIC_20180309_170955.csv:
    keep: false
    reason: pre-v2-fix, exploratory, mean 159° suggests moved source
  aoa_FPGA_ROOTMUSIC_20180309_171058.csv:
    keep: false
    reason: pre-v2-fix, exploratory

  # ---------- Post-v2-fix ROOTMUSIC pair at ~90° ----------
  # Referenced in CHANGELOG 2026-04-04: "FPGA ROOTMUSIC now matches ARM
  # results (~93° vs ~95° for the same source position)".
  aoa_ARM_ROOTMUSIC_20180309_171310.csv:
    keep: true
    group: rootmusic_pair_90deg
    true_angle_deg: 90.0
    notes: |
      First post-v2-fix ARM ROOTMUSIC run. 345 samples over 58s.
      Pair with aoa_FPGA_ROOTMUSIC_20180309_171428.csv.
  aoa_FPGA_ROOTMUSIC_20180309_171428.csv:
    keep: true
    group: rootmusic_pair_90deg
    true_angle_deg: 90.0
    notes: |
      First post-v2-fix FPGA ROOTMUSIC run. 103 samples over 53s.
      Main thesis figure for FPGA ≈ ARM demonstration.

  # ---------- Post-v2-fix ROOTMUSIC extras ----------
  aoa_FPGA_ROOTMUSIC_20180309_171655.csv:
    keep: false
    reason: |
      Post-v2-fix but mean 58.6° — inconsistent with ~90° source.
      UNCERTAIN: source moved? cal drift? Ask user to confirm or exclude.

  # ---------- Post-v2-fix MUSIC single ----------
  aoa_ARM_MUSIC_20180309_172644.csv:
    keep: false
    reason: |
      Only 100 samples over 26s, no FPGA MUSIC counterpart in same window.
      Borderline — can reactivate if we want more ARM MUSIC data points.

  # ---------- Cluster C: MUSIC pair at ~90° ----------
  # Longest and cleanest runs. User confirmed: source not moved between
  # 18:11 ARM and 18:16 FPGA, no recal between them.
  aoa_ARM_MUSIC_20180309_181138.csv:
    keep: true
    group: music_pair_90deg
    true_angle_deg: 90.0
    notes: |
      Reference-quality ARM MUSIC: 1039 samples over 276s. Same cal state
      as the FPGA MUSIC run immediately after.
  aoa_FPGA_MUSIC_20180309_181642.csv:
    keep: true
    group: music_pair_90deg
    true_angle_deg: 90.0
    notes: |
      FPGA MUSIC, 274 samples over 176s, back-to-back with ARM MUSIC above.
      Mean ~86.6° vs ARM's 100° — expect to show FPGA MUSIC spectral bias
      documented in CHANGELOG.
  aoa_FPGA_MUSIC_20180309_182924.csv:
    keep: false
    reason: only 17 samples over 9s, too short for stats

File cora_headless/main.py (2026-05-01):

#!/usr/bin/env python3
"""
main.py - UART Command Listener for Cora Z7 Headless DoA System

This script runs on the Cora Z7 at boot and listens for commands from the 
Waveshare ESP32-S3-Touch-LCD-4.3 display via UART. It dispatches commands
to the appropriate GNU Radio scripts for calibration and DoA estimation.

Hardware Setup:
    - Cora Z7 UART pins connected to Waveshare display UART pins
    - BladeRF 2.0 connected via USB (limited to 6 MSPS due to USB 2.0)

Protocol:
    Commands (from Display → Cora):
        CALIBRATE           - Run phase calibration routine
        ESTIMATE            - Run DoA estimation with current calibration
        ESTIMATE:<algo>     - Run specific algorithm (MUSIC, ROOTMUSIC, MVDR, PHASEDIFF)
        STATUS              - Report current system status
        GET_CAL             - Return current calibration coefficient
        SET_CAL:<value>     - Manually set calibration coefficient (degrees)
        STOP                - Stop any running estimation
        SHUTDOWN            - Safe shutdown sequence
    
    Responses (from Cora → Display):
        OK:<message>        - Command acknowledged
        ERROR:<message>     - Command failed
        CAL:<value>         - Calibration coefficient in degrees
        AOA:<value>         - Estimated angle of arrival in degrees
        STATUS:<state>      - Current system state
        DONE                - Operation completed

Author: DoA Thesis Project
Date: 2026
"""

import serial
import subprocess
import threading
import signal
import sys
import json
import time
from pathlib import Path
from datetime import datetime
from enum import Enum
from typing import Optional, Callable

# =============================================================================
# Configuration
# =============================================================================

class Config:
    """System configuration constants."""
    
    # UART Settings
    UART_PORT = "/dev/ttyACM0"  # ESP32-S3 USB CDC (full duplex, no RS485)
    UART_BAUD = 115200
    UART_TIMEOUT = 0.1  # seconds
    
    # File Paths
    SCRIPT_DIR = Path(__file__).parent
    DATA_DIR = SCRIPT_DIR / "data"
    LOG_DIR = SCRIPT_DIR / "logs"
    CAL_FILE = DATA_DIR / "calibration.json"
    
    # Script Paths (GNU Radio generated Python scripts)
    CALIBRATION_SCRIPT = SCRIPT_DIR / "phase_calibration_headless.py"
    ESTIMATION_SCRIPT = SCRIPT_DIR / "aoa_estimation_headless.py"
    ESTIMATION_FPGA_SCRIPT = SCRIPT_DIR / "aoa_estimation_fpga_v3.py"
    
    # Operational Parameters
    WARMUP_TIME = 30  # seconds to wait for BladeRF thermal stability
    CAL_DURATION = 10  # seconds to collect calibration data
    ESTIMATION_INTERVAL = 0.1  # seconds between AoA reports
    
    # Sample Rate (limited by USB 2.0 bandwidth)
    SAMPLE_RATE = 1e6  # 1 MSPS (conservative for USB 2.0)


class SystemState(Enum):
    """System state machine states."""
    IDLE = "IDLE"
    WARMING_UP = "WARMING_UP"
    CALIBRATING = "CALIBRATING"
    ESTIMATING = "ESTIMATING"
    ERROR = "ERROR"
    SHUTTING_DOWN = "SHUTTING_DOWN"


# =============================================================================
# Calibration Storage
# =============================================================================

class CalibrationStore:
    """Manages persistent storage of calibration data."""
    
    def __init__(self, filepath: Path):
        self.filepath = filepath
        self.filepath.parent.mkdir(parents=True, exist_ok=True)
        self._data = self._load()
    
    def _load(self) -> dict:
        """Load calibration data from file."""
        if self.filepath.exists():
            try:
                with open(self.filepath, 'r') as f:
                    return json.load(f)
            except (json.JSONDecodeError, IOError):
                pass
        return {
            "phase_offset_deg": 0.0,
            "timestamp": None,
            "gain_setting": None,
            "frequency_hz": None
        }
    
    def _save(self):
        """Save calibration data to file."""
        with open(self.filepath, 'w') as f:
            json.dump(self._data, f, indent=2)
    
    @property
    def phase_offset_deg(self) -> float:
        return self._data.get("phase_offset_deg", 0.0)
    
    @phase_offset_deg.setter
    def phase_offset_deg(self, value: float):
        self._data["phase_offset_deg"] = value
        self._data["timestamp"] = datetime.now().isoformat()
        self._save()
    
    def update(self, phase_deg: float, gain: int = None, freq_hz: float = None):
        """Update calibration with full context."""
        self._data["phase_offset_deg"] = phase_deg
        self._data["timestamp"] = datetime.now().isoformat()
        if gain is not None:
            self._data["gain_setting"] = gain
        if freq_hz is not None:
            self._data["frequency_hz"] = freq_hz
        self._save()
    
    def is_valid(self) -> bool:
        """Check if calibration exists and is recent."""
        return self._data.get("timestamp") is not None


# =============================================================================
# Data Logging
# =============================================================================
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

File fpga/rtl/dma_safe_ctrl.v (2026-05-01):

// dma_safe_ctrl.v -- AXI-Lite register-stride shim for KV260 AXI DMA
//
// The KV260 HPM0_FPD control path in this project only reliably commits the
// first 32-bit word of each 16-byte region. This shim exposes a 16-byte-spaced
// AXI-Lite slave window to Linux, then performs normal 32-bit AXI-Lite accesses
// to the stock AXI DMA control port inside PL.
//
// Software-visible safe offset -> real DMA offset:
//   0x000 -> 0x00  MM2S_DMACR
//   0x010 -> 0x04  MM2S_DMASR
//   0x020 -> 0x08  MM2S_CURDESC
//   0x040 -> 0x10  MM2S_TAILDESC
//
// In general: real_offset = safe_offset >> 2, provided safe_offset[3:0] == 0.

`timescale 1ns / 1ps

module dma_safe_ctrl #(
    parameter C_S_AXI_ADDR_WIDTH = 12,
    parameter C_M_AXI_ADDR_WIDTH = 12,
    parameter C_AXI_DATA_WIDTH   = 32
)(
    (* X_INTERFACE_INFO = "xilinx.com:signal:clock:1.0 clk CLK" *)
    (* X_INTERFACE_PARAMETER = "ASSOCIATED_BUSIF s_axi:m_axi, ASSOCIATED_RESET resetn" *)
    input  wire                              clk,
    (* X_INTERFACE_INFO = "xilinx.com:signal:reset:1.0 resetn RST" *)
    (* X_INTERFACE_PARAMETER = "POLARITY ACTIVE_LOW" *)
    input  wire                              resetn,

    (* X_INTERFACE_INFO = "xilinx.com:interface:aximm:1.0 s_axi AWADDR" *)
    (* X_INTERFACE_PARAMETER = "PROTOCOL AXI4LITE, DATA_WIDTH 32, ADDR_WIDTH 12, NUM_READ_OUTSTANDING 1, NUM_WRITE_OUTSTANDING 1, HAS_BURST 0, HAS_LOCK 0, HAS_PROT 1, HAS_CACHE 0, HAS_QOS 0, HAS_REGION 0, SUPPORTS_NARROW_BURST 0" *)
    input  wire [C_S_AXI_ADDR_WIDTH-1:0]     s_axi_awaddr,
    (* X_INTERFACE_INFO = "xilinx.com:interface:aximm:1.0 s_axi AWPROT" *)
    input  wire [2:0]                        s_axi_awprot,
    (* X_INTERFACE_INFO = "xilinx.com:interface:aximm:1.0 s_axi AWVALID" *)
    input  wire                              s_axi_awvalid,
    (* X_INTERFACE_INFO = "xilinx.com:interface:aximm:1.0 s_axi AWREADY" *)
    output wire                              s_axi_awready,

    (* X_INTERFACE_INFO = "xilinx.com:interface:aximm:1.0 s_axi WDATA" *)
    input  wire [C_AXI_DATA_WIDTH-1:0]       s_axi_wdata,
    (* X_INTERFACE_INFO = "xilinx.com:interface:aximm:1.0 s_axi WSTRB" *)
    input  wire [(C_AXI_DATA_WIDTH/8)-1:0]   s_axi_wstrb,
    (* X_INTERFACE_INFO = "xilinx.com:interface:aximm:1.0 s_axi WVALID" *)
    input  wire                              s_axi_wvalid,
    (* X_INTERFACE_INFO = "xilinx.com:interface:aximm:1.0 s_axi WREADY" *)
    output wire                              s_axi_wready,

    (* X_INTERFACE_INFO = "xilinx.com:interface:aximm:1.0 s_axi BRESP" *)
    output reg  [1:0]                        s_axi_bresp,
    (* X_INTERFACE_INFO = "xilinx.com:interface:aximm:1.0 s_axi BVALID" *)
    output reg                               s_axi_bvalid,
    (* X_INTERFACE_INFO = "xilinx.com:interface:aximm:1.0 s_axi BREADY" *)
    input  wire                              s_axi_bready,

    (* X_INTERFACE_INFO = "xilinx.com:interface:aximm:1.0 s_axi ARADDR" *)
    input  wire [C_S_AXI_ADDR_WIDTH-1:0]     s_axi_araddr,
    (* X_INTERFACE_INFO = "xilinx.com:interface:aximm:1.0 s_axi ARPROT" *)
    input  wire [2:0]                        s_axi_arprot,
    (* X_INTERFACE_INFO = "xilinx.com:interface:aximm:1.0 s_axi ARVALID" *)
    input  wire                              s_axi_arvalid,
    (* X_INTERFACE_INFO = "xilinx.com:interface:aximm:1.0 s_axi ARREADY" *)
    output wire                              s_axi_arready,
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

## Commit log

2026-04-06 Initial release: 2.4 GHz DoA estimation system
    Portable Direction-of-Arrival estimation using Cora Z7 (Zynq-7000),
    BladeRF 2.0 xA4, and custom FPGA cross-correlation IP. Includes ARM
    and FPGA implementations of Root-MUSIC, MUSIC, MVDR, and Phase
    Difference algorithms with web dashboard and touch display interfaces.
    [antenna_bracke_1.stl, antenna_bracket.scad, antenna_bracket.stl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]
2026-05-01 Sync from working repo: apr 2026 v2 campaign + KV260 EMIO bring-up
    Brings the public release current with thesis development through
    2026-04-29:
    - KV260 (Kria K26) headless driver path (kv260_headless/) using EMIO
    GPIO + udmabuf, replacing the Cora /dev/mem + OCM transport. Includes
    AoA estimation, phase calibration, EMIO probe, and DMA probe scripts.
    - doa_pipeline RTL extended with FIR filter, phase-rotate calibration,
    xcorr/autocorr accumulators, and dma_safe_ctrl shim (fpga/rtl/).
    - Apr 2026 v2 measurement campaign data + analysis (data/runA-runE,
    results/campaign_*).
    - Headless ARM driver bug fixes (symmetric bandpass on CF32, advisory
    SOAPY_SDR_OVERFLOW handling).
    - New anal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
    [aoa_ARM_F_20180309_173946.csv, aoa_ARM_MUSIC_20180309_170446.csv, aoa_ARM_MUSIC_20180309_172644.csv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]
2026-05-01 docs: rewrite README + INSTALL_GUIDE for KV260-primary platform; drop dead configs
    README now documents both platforms with KV260 as primary and Cora as
    the frozen validated reference. Adds the "Why two platforms?" rationale
    (PetaLinux 2025.2 chipidea USB binding regression — AMD AR#000039143)
    that drove the pivot. Hardware table, RF parameters, repo structure,
    quick-start commands, and FPGA pipeline section all reflect the live
    2026-04-29 driver state.
    INSTALL_GUIDE replaces the GNU Radio + gr-aoa walkthrough (no longer
    the active path) with two explicit tracks:
    - Path A: host PC for offline replay/analysis (pure pip install)
    - Path B: KV260 deployment from system packages + SoapySDR / l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
